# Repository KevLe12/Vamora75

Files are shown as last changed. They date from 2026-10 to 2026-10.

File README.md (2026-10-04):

# Vamora75

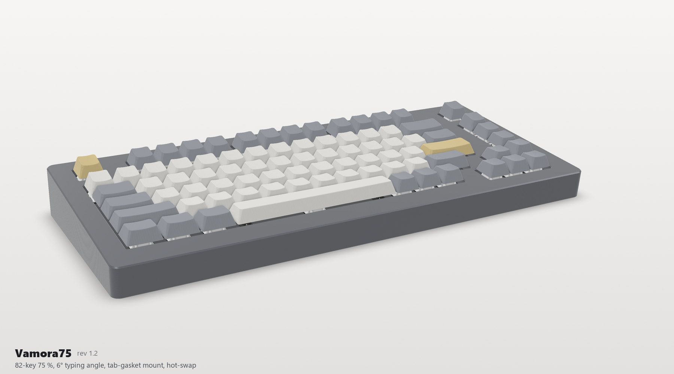
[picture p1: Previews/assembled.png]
Vamora75


**An 82-key 75 % mechanical keyboard with a 6° typing angle, a tab-gasket mount, hot-swap sockets
and an on-board RP2040.** Designed by **Kevin Le, Sammy DeGraaff and Mohammed-Mehdi Hamdaoui**.

> **Status: revision 1.2, complete and checked in software, not built yet.** ERC, DRC, schematic
> parity, plate DRC, 14 CAD interference checks and 30 firmware tests all pass
> ([validation/STATUS.md](validation/STATUS.md)). Build one prototype before a group order and work
> through the open items in [DESIGN_REVIEW.md](DESIGN_REVIEW.md).

## Features

- Exploded 75 % Windows ANSI layout, 82 keys, with a separated arrow cluster
- Hot-swap Kailh sockets for any 3- or 5-pin MX-compatible switch
- PCB-mount screw-in stabilisers on plated, copper-reinforced holes; the plate openings let the
  stabiliser housings pass through
- Tab-gasket sandwich mount: 8 plate tabs, 16 gaskets at 20 % compression, optional flex-cut plate
- 6° typing angle; two-piece case whose top follows the key clusters, so no plate shows between
  them; printed in one piece, in 4 pieces for 250 x 210 mm beds, or CNC
- RP2040 on the board (the Raspberry Pi Pico core circuit), USB-C, ESD protection, fuse, BOOT and
  RESET buttons
- QMK + VIA, or CircuitPython with no compiler
- Black PCB with ENIG gold; "Vamora75" across the PCB front, engraved under the case and in gold on
  the plate (under the top case); *Nam Quốc Sơn Hà* and the designers' names on the PCB back
- Generated from source: one command rebuilds the PCB, plate, case, firmware, manufacturing files,
  3D models and renders, then re-runs every check

## Gallery

| Exploded | Top |
|---|---|
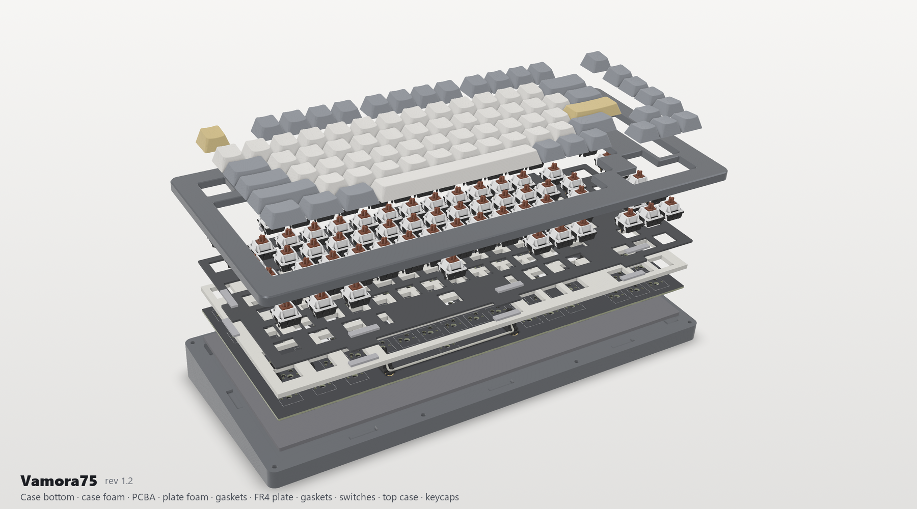
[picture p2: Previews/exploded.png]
Exploded
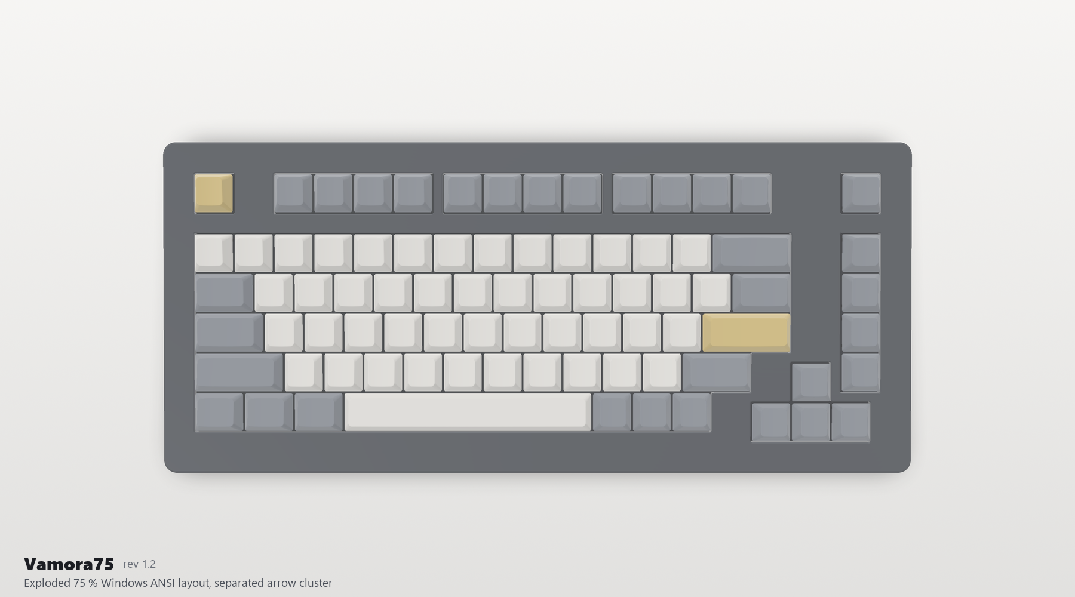
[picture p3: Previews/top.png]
Top
|  |  |
| **Profile** | **Underside** |
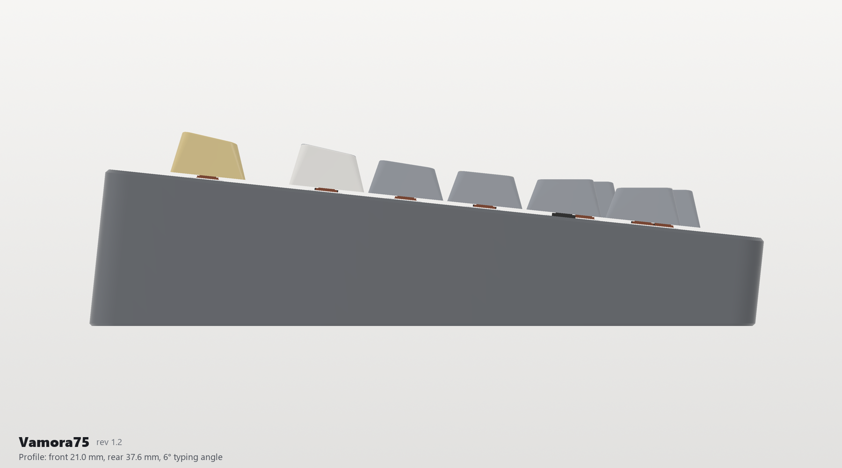
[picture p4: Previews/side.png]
Side
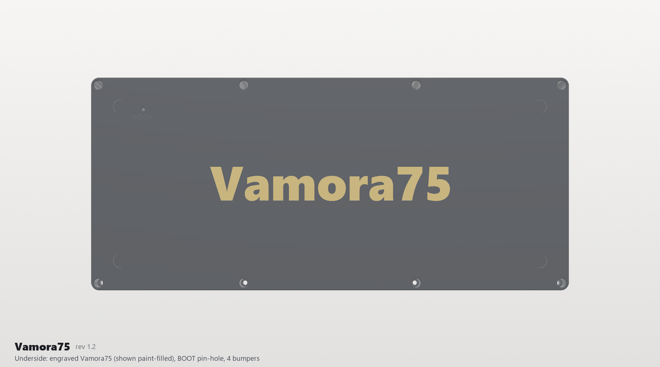
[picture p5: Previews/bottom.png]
Bottom
|  |  |

**PCB + plate + components** (no case): Joe Scotto's MX switches, the PCB-mount stabilisers, Kailh
sockets and every SMD part ([3D file](Mechanical/Vamora75_PCB_plate.step),
[quick-look .glb](Mechanical/Vamora75_PCB_plate.glb)):

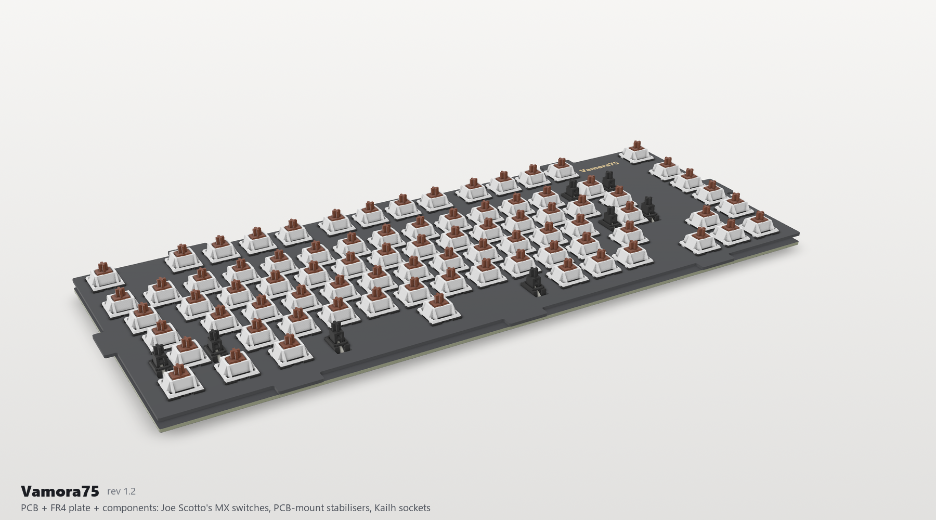
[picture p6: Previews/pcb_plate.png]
PCB and plate


### PCB

| Front ("Vamora75" silkscreen) | Back (*Nam Quốc Sơn Hà*, designers, gold stabiliser rings) |
|---|---|
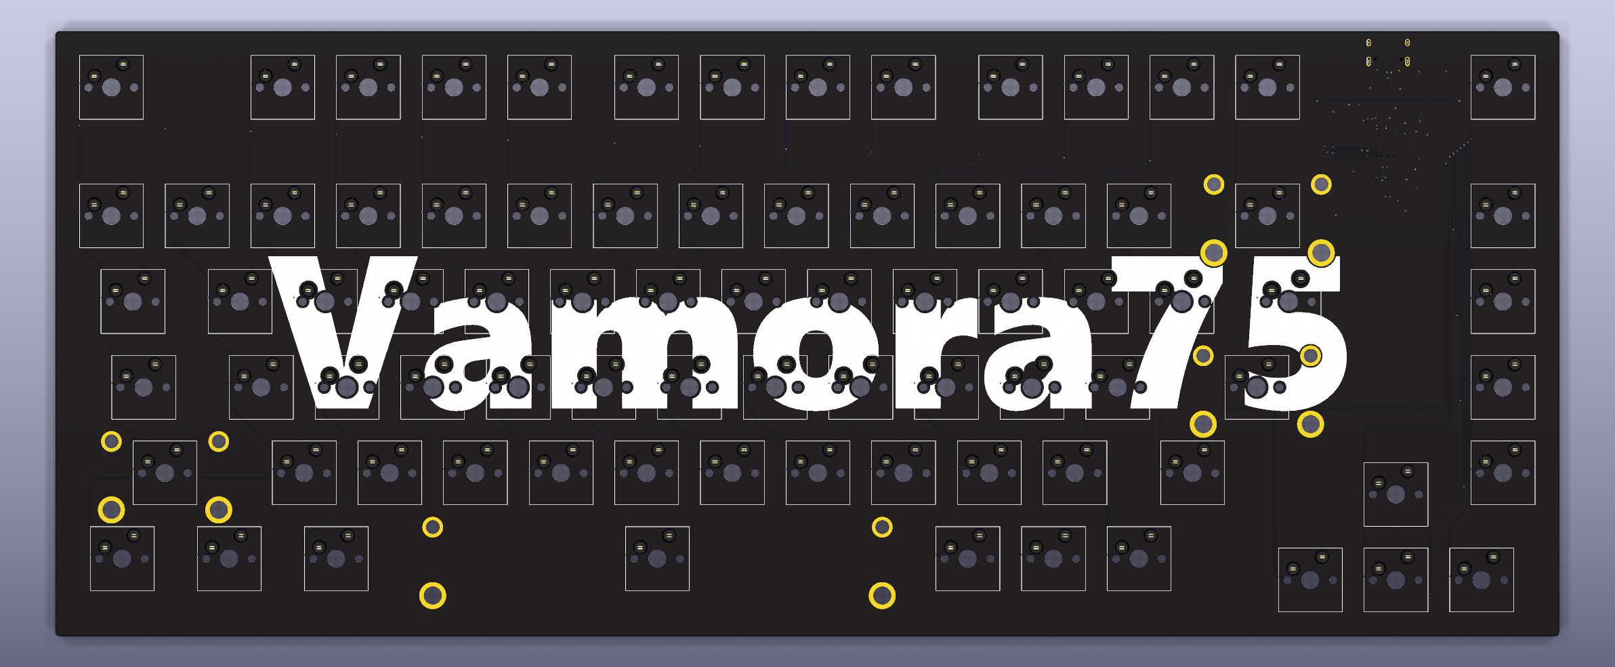
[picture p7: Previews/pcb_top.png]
PCB front
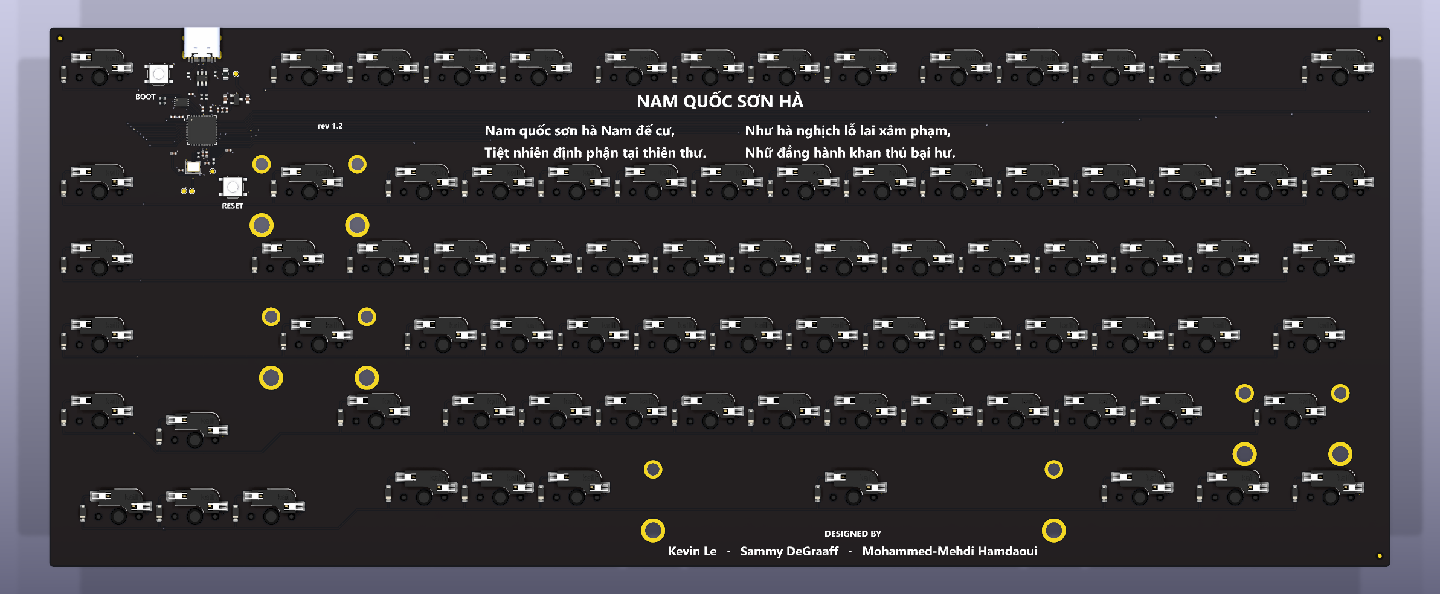
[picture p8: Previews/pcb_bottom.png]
PCB back
|  |  |
| **With Joe Scotto's switch models** | **FR4 plate (name in gold ENIG, under the top case)** |
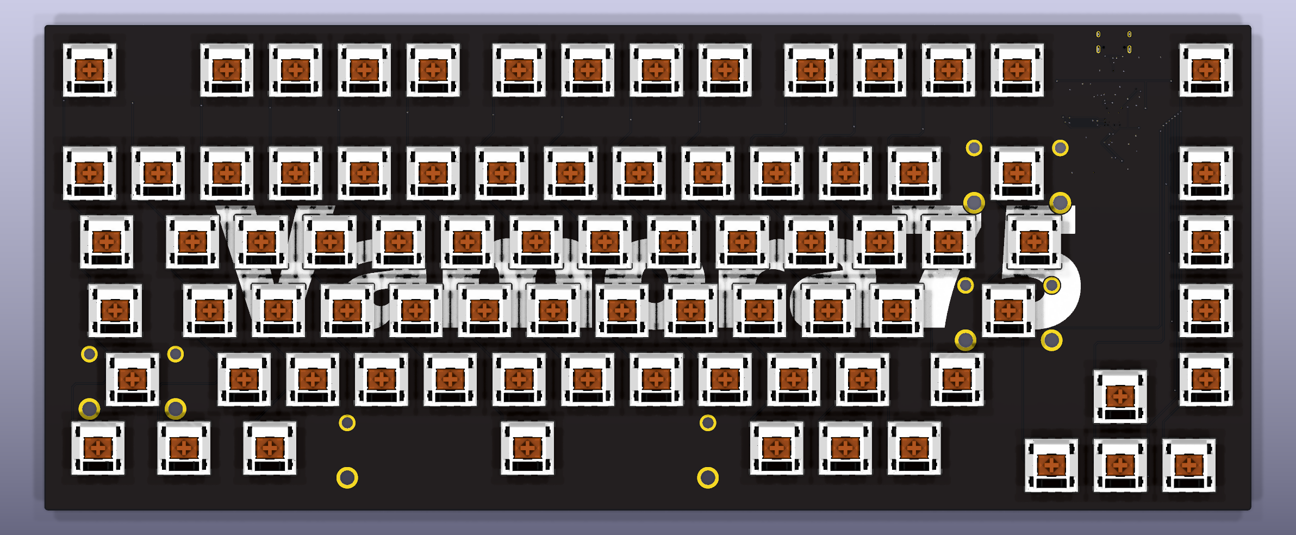
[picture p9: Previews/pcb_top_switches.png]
PCB with switches
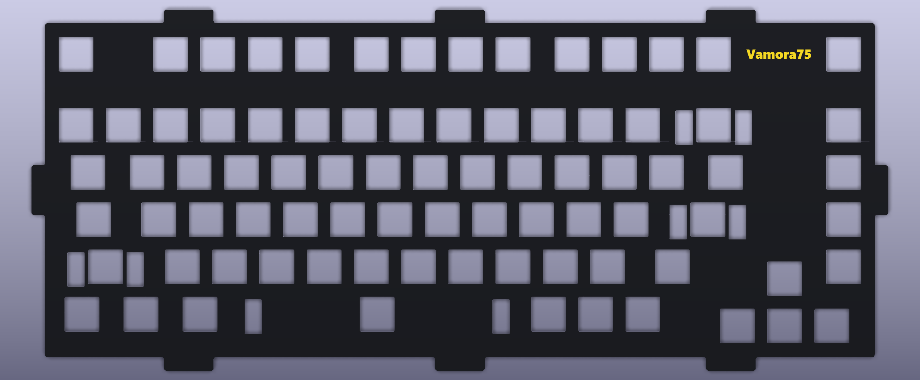
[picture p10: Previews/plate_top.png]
Plate
|  |  |

## 3D files

| File | Shows | Open with |
|---|---|---|
| [Mechanical/Vamora75_assembly.step](Mechanical/Vamora75_assembly.step) | The whole keyboard: case, gaskets, foams, plate, PCBA, switches, stabilisers, keycaps | FreeCAD, Fusion 360, Onshape, SolidWorks |
| [Mechanical/Vamora75_PCB_plate.step](Mechanical/Vamora75_PCB_plate.step) | PCB + plate + every component, without the case | any STEP viewer |
| [Mechanical/Vamora75_PCB_plate.glb](Mechanical/Vamora75_PCB_plate.glb) | The same, as a light coloured model | Windows 3D Viewer, Blender, any web glTF viewer |
| [Mechanical/Vamora75_PCBA.step](Mechanical/Vamora75_PCBA.step) | The PCBA only (KiCad export) | any STEP viewer |
| [PCB/Vamora75.kicad_pro](PCB/Vamora75.kicad_pro) | Schematic and board; press Alt+3 for the 3D view | KiCad 10 |

Case parts, the plate and the soft parts are in [Mechanical/](Mechanical) as STEP/STL/DXF.

## Specifications

| | |
|---|---|
| Layout | 82 keys: exploded 75 % Windows ANSI with an F-row in clusters, a Del/Home/PgUp/PgDn/End column, a separated arrow cluster (0.25u gap), 1.75u RShift and 6.25u space ([layout](Previews/layout.png)) |
| Switches | Any MX-compatible switch, 3- or 5-pin, in Kailh CPG151101S11 hot-swap sockets (ScottoKicad `Hotswap_MX` footprints) |
| Stabilisers | PCB-mount screw-in: Backspace (2u), Enter and LShift (2.25u), Space (6.25u), standard orientation. Plated holes with 4.6 / 6.0 mm copper reinforcement rings; plate openings 7.0 x 14 mm |
| Controller | RP2040, W25Q16JV 2 MB flash, 12 MHz crystal (the Raspberry Pi Pico core circuit), BOOT and RESET buttons |
| USB | USB-C (HRO TYPE-C-31-M-12), USB 2.0 full speed, 5.1 kΩ CC resistors (C-C and A-C cables), USBLC6-2SC6 ESD protection, 0.5 A PTC fuse, XC6206 3.3 V LDO |
| Matrix | 6 x 16, COL2ROW, one 1N4148W per key |
| PCB | 334.61 x 134.59 mm, 2 layers, 1.6 mm, black solder mask, white silkscreen, ENIG. All SMT parts on the bottom (one-sided assembly), GND pour on both layers |
| Plate | FR4, 1.5 mm (1.6 mm also fits), black, 8 gasket tabs, optional flex cuts, "Vamora75" in gold ENIG |
| Mount | Tab-gasket sandwich: 16 gaskets of 20 x 4.5 x 2 mm at 20 % compression. PCB and plate float as one unit |
| Case | Two pieces, 6° typing angle, 21.0 mm high at the front and 37.6 mm at the rear, 358.6 x 161.5 mm. The top-case opening follows the key clusters (the case covers every gap between them). 8 M3 screws into heat-set inserts, "Vamora75" engraved underneath |
| Firmware | QMK + VIA, or CircuitPython |

## Bill of materials

<!-- BOM:start (generated by Source/export_manufacturing.py) -->
Full list: [BOM.csv](BOM.csv). The PCBA parts are placed by JLCPCB from
[Vamora75_BOM_JLCPCB.csv](Manufacturing/PCB/Vamora75_BOM_JLCPCB.csv) and
[Vamora75_CPL_JLCPCB.csv](Manufacturing/PCB/Vamora75_CPL_JLCPCB.csv); you only buy the kit items.

**Kit: what to buy or make**

| Item | Qty | Specification | Source / file |
|---|---|---|---|
| PCBA (this design) | 1 | 2-layer FR4 1.6 mm, black mask, ENIG, bottom-side SMT assembled | Manufacturing/PCB - JLCPCB/PCBWay |
| FR4 plate | 1 | 1.5 mm (1.6 mm fits), black mask, ENIG for the gold name | Manufacturing/Plate - any PCB fab |
| Case top | 1 | PETG/ASA print or CNC 6061 | Mechanical/Case |
| Case bottom | 1 | PETG/ASA print or CNC 6061 (solid wedge, 6 deg) | Mechanical/Case |
| MX-compatible switches | 82 | 3-pin or 5-pin | user choice |
| Keycaps | 82 | 1u x 71, 1.25u x 3, 1.5u x 2, 1.75u x 2, 2u x 1, 2.25u x 2, 6.25u x 1 | any MX set with a 75 % kit (1.75u RShift, 6.25u space) |
| PCB-mount screw-in stabilisers | 4 | 3 x 2u (Backspace, Enter, LShift) + 1 x 6.25u (Space) | Durock/Cherry/TX |
| Gaskets | 16 | 20 x 4.5 x 2 mm Poron 4701-50 or 40A silicone | Mechanical/Soft DXF |
| Case foam | 1 | 3 mm PE / Poron | Mechanical/Soft DXF |
| Plate foam (optional) | 1 | 3.5 mm Poron / PE, with stabiliser/wire windows | Mechanical/Soft DXF |
| Screws | 8 | M3 x 8 ISO 4762 socket head |  |
| Heat-set inserts | 8 | M3 x 4 x 4.0 mm heat-set insert (printed top case; tap M3 if CNC) |  |
| Dowel pins (split print only) | 5 | 3 x 12 mm steel dowel (or printed pin) | only for the 4-piece printed case |
| Bumpers | 4 | 10 x 3 mm silicone bumper |  |
| USB-C cable | 1 | overmould <= 12.3 x 6.5 mm |  |

**PCBA: parts on the board** (197 placements, all on the bottom side)

| Part | Qty | Designators | Footprint | LCSC |
|---|---|---|---|---|
| 10uF CL10A106KP8NNNC | 2 | C1-C2 | C_0603_1608Metric | [C19702](https://www.lcsc.com/product-detail/C19702.html) |
| 100nF CL05B104KO5NNNC | 10 | C3-C7, C9-C12, C15 | Capacitor_0402 | [C1525](https://www.lcsc.com/product-detail/C1525.html) |
| 1uF CL05A105KA5NQNC | 2 | C13-C14 | Capacitor_0402 | [C52923](https://www.lcsc.com/product-detail/C52923.html) |
| 15pF 0402CG150J500NT | 2 | C16-C17 | Capacitor_0402 | [C1548](https://www.lcsc.com/product-detail/C1548.html) |
| 1N4148W | 82 | D1-D82 | Diode_SOD-123 | [C81598](https://www.lcsc.com/product-detail/C81598.html) |
| 500mA SMD0805-050 | 1 | F1 | Fuse_0805_2012Metric | [C66452](https://www.lcsc.com/product-detail/C66452.html) |
| HRO TYPE-C-31-M-12 | 1 | J1 | USB_C_HRO_TYPE-C-31-M-12 | [C165948](https://www.lcsc.com/product-detail/C165948.html) |
| 5.1k 0402WGF5101TCE | 2 | R1-R2 | Resistor_0402 | [C25905](https://www.lcsc.com/product-detail/C25905.html) |
| 27R 0402WGF270JTCE | 2 | R3-R4 | Resistor_0402 | [C25100](https://www.lcsc.com/product-detail/C25100.html) |
| 10k 0402WGF1002TCE | 2 | R5, R7 | Resistor_0402 | [C25744](https://www.lcsc.com/product-detail/C25744.html) |
| 1k 0402WGF1001TCE | 2 | R6, R8 | Resistor_0402 | [C11702](https://www.lcsc.com/product-detail/C11702.html) |
| Kailh CPG151101S11 MX hot-swap socket | 82 | SW1-SW82 | Kailh_CPG151101S11 | [C5156480](https://www.lcsc.com/product-detail/C5156480.html) |
| BOOT TS-1187A-B-A-B | 1 | SW90 | SW_Push_1P1T_XKB_TS-1187A | [C318884](https://www.lcsc.com/product-detail/C318884.html) |
| RESET TS-1187A-B-A-B | 1 | SW91 | SW_Push_1P1T_XKB_TS-1187A | [C318884](https://www.lcsc.com/product-detail/C318884.html) |
| RP2040 | 1 | U1 | QFN-56-1EP_7x7mm_P0.4mm_EP3.2x3.2mm_ThermalVias | [C2040](https://www.lcsc.com/product-detail/C2040.html) |
| USBLC6-2SC6 | 1 | U2 | ESD_SOT-23-6 | [C7519](https://www.lcsc.com/product-detail/C7519.html) |
| XC6206P332MR | 1 | U3 | Voltage_SOT-23 | [C5446](https://www.lcsc.com/product-detail/C5446.html) |
| W25Q16JVUXIQ | 1 | U4 | Winbond_USON-8-1EP_3x2mm_P0.5mm_EP0.2x1.6mm | [C2843335](https://www.lcsc.com/product-detail/C2843335.html) |
| 12MHz ABM8-272-T3 | 1 | Y1 | Crystal_SMD_3225-4Pin_3.2x2.5mm | [C20625731](https://www.lcsc.com/product-detail/C20625731.html) |
<!-- BOM:end -->

## Getting started

1. Read [DESIGN_REVIEW.md](DESIGN_REVIEW.md): the mount, the stabilisers, what changed, and what to
   check on the first prototype.
2. Order the PCBA, the plate, the case and the soft parts:
   [Manufacturing/FABRICATION.md](Manufacturing/FABRICATION.md).
3. Assemble it: [BUILD_GUIDE.md](BUILD_GUIDE.md).
4. Flash the firmware: [Firmware/README.md](Firmware/README.md).
5. To change the design, edit the parameter files and rebuild: [Source/README.md](Source/README.md).

## Repository

| Folder | Contents |
|---|---|
| [PCB/](PCB) | KiCad 10 project: schematic, 2-layer board, project footprint library (ScottoKicad + KiCad stock) with 3D models, custom DRC rules |
| [Plate/](Plate) | KiCad boards for ordering the FR4 plate as a PCB (standard and flex-cut) |
| [Mechanical/](Mechanical) | Case (one-piece and 4-piece print split), plate DXF/STEP/STL, gasket and foam DXFs, assembly STEP, PCB + plate STEP/GLB, PCBA STEP, key positions |
| [Manufacturing/](Manufacturing) | JLCPCB-ready Gerbers/drill, BOM + CPL, schematic PDF, assembly drawing, plate Gerbers, kit BOM |
| [Firmware/](Firmware) | QMK + VIA source, VIA definition, CircuitPython, KLE layout |
| [Artwork/](Artwork) | The "Vamora75" name in SVG/PNG/DXF ([NAME.md](Artwork/NAME.md)) |
| [Previews/](Previews) | Renders |
| [Source/](Source) | Python generators for everything (`build_all.py`) |
| [validation/](validation) | ERC/DRC, mechanical, plate and firmware reports |
| [Archive/](Archive) | Earlier revisions: `rev0.1/`, `rev1.0_outputs.zip`, `rev1.1_outputs.zip` |
| [Reference/](Reference) | Input snapshots (Keyboard75, Aster75) |

## Revisions

- **1.2** (2026-10-03): top case covers the gaps between key clusters, plate openings and foam
  windows for PCB-mount stabilisers, plated and reinforced stabiliser holes, black PCB, designers'
  names on the PCB back, sculpted keycaps, new 3D files and renders.
- **1.1**: arrow cluster moved away from the nav column, Joe Scotto's ScottoKicad footprints and
  models, name-only branding.
- **1.0**: on-board RP2040, new matrix and routing, 6° gasket-mount case.

Details: [CHANGELOG.md](CHANGELOG.md).

## Credits

Designed by **Kevin Le, Sammy DeGraaff and Mohammed-Mehdi Hamdaoui** (team Vamora).

Footprints and 3D models for the switches, sockets, stabilisers and several components are from
Joe Scotto's [ScottoKicad](https://github.com/joe-scotto/scottokeebs). Third-party data and licences:
[ATTRIBUTION.md](ATTRIBUTION.md) and [Licenses/](Licenses).

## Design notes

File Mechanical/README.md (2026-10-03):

# Vamora75 mechanical files

All parts share one coordinate system (STEP/STL, mm): X runs left to right along the front edge,
Y runs toward the rear, and Z points up from the desk. The case sits at its 6° typing angle.
The internal design frame (plate-parallel) is described in `Source/vamora_mech.py`.

| File | Contents |
|---|---|
| `Vamora75_assembly.step` | The whole keyboard: case, gaskets, plate (with its gold name), plate foam, case foam, the PCBA in KiCad's colours (black mask, white silkscreen, gold pads, Joe Scotto's switches, stabilisers, sockets and SMD parts) and sculpted keycaps. Coloured and instanced. |
| `Vamora75_PCB_plate.step` | **PCB + plate + every component**, without the case: the PCBA as above with the FR4 plate fitted 3.5 mm above the PCB (where it sits in the keyboard). Same frame as the PCBA STEP. |
| `Vamora75_PCB_plate.glb` | The same as a coloured glTF file: opens in Windows 3D Viewer, Blender or any web glTF viewer (no CAD software needed). |
| `Vamora75_PCBA.step` | The PCB with solder mask, silkscreen, pads and every component, including Joe Scotto's MX switch on every footprint, exported by KiCad. Origin is the PCB's front-left corner, board bottom at z = 0. |
| `Case/Vamora75_case_top.*`, `Case/Vamora75_case_bottom.*` | One-piece case parts. The top-case opening follows the key clusters (0.25 mm beyond each key's 19.05 mm cell, R1 corners, 0.5 mm chamfer); bridges of 4.3 mm and wider cover every gap between clusters, 1 mm above the plate |
| `Case/print_split/*_L/_R.*` | The same parts split for 250 x 210 mm beds (staggered seams, dowel holes) |
| `Plate/Vamora75_plate_FR4[_flexcut].dxf/.step/.stl` | Plate outline and openings (the DXF has OUTLINE, CUTOUTS and FLEX layers). Stabiliser openings 7.0 x 14 mm for PCB-mount stabilisers. |
| `Soft/*.dxf` | Gaskets (16), case foam (3 mm), plate foam (3.5 mm, with stabiliser/wire windows) |
| `key_positions.csv` | Every key: label, size, matrix, switch/diode refs, PCB and CAD coordinates, stabiliser spacing |
| `build/` | Intermediate files. The switch-free PCBA STEP used by `build_case.py` and the coloured render meshes (`*.npz`) are written here and deleted again by `build_all.py` after rendering. |

Key numbers (from `validation/mechanical.json`):

* Footprint 358.6 x 161.5 mm. Height 21.0 mm at the front and 37.6 mm at the rear. Typing angle 6°.
* Mount: 8 plate tabs (20 x 5.5 mm), 16 gaskets (20 x 4.5 x 2.0 mm) set to 1.6 mm (20 %).
  Tab pockets have 0.5 mm clearance. The PCB and plate have 1.0 mm clearance to every wall.
* Fasteners: 8 M3 x 8 ISO 4762 screws from below, into M3 x 4 heat-set inserts (4.0 mm holes) in the top case.
* USB-C tunnel: 14.0 x 8.0 mm, R3.5, centred on J1. It passes a USB-IF maximum overmould (12.35 x 6.5 mm)
  with 0.8 mm to spare.
* BOOT pin-hole: 2.2 mm, through the floor under SW90.
* 14 interference checks run on every rebuild. Every overlap volume is 0 mm³, including the PCB-mount
  stabilisers through the plate and the plate foam, keycaps pressed fully down (4 mm), the switches
  against the top case, and the gaskets against the plate and case.
* Keycaps in the models are generated sculpted (Cherry-like) caps for looks and clearance checks;
  any MX keycap set fits.

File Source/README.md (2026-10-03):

# Vamora75 sources

Every deliverable in this repository is generated by the scripts in this folder from a few
parameter files. Edit the parameters, rerun, and every file (PCB, plate, case, firmware,
artwork, manufacturing outputs, renders, reports) stays consistent.

```
python -m venv .venv && .venv\Scripts\pip install -r Source\requirements.txt
.venv\Scripts\python Source\build_all.py              # everything, ~8 min (PCB routing ~3 min)
.venv\Scripts\python Source\build_all.py --skip-pcb   # keep the routed board, rebuild the rest
.venv\Scripts\python Source\build_all.py --footprints # also regenerate footprints + 3D models
```

KiCad 10.0.6 must be installed at `C:\Program Files\KiCad\10.0` (paths are at the top of
`build_pcb.py`, `build_all.py`, `export_manufacturing.py`). Joe Scotto's **ScottoKicad** library
is read from `A:\ScottoKicad` (set `VAMORA_SCOTTO` to move it). You only need it to regenerate
footprints (`--footprints`); the project already carries copies of everything it uses. The Segoe UI fonts ship with Windows; any TTF works
(constants in `vamora_logo.py`).

## Parameter files (edit these)

| File | Controls |
|---|---|
| `vamora_layout.py` | revision, date and designers; key positions and sizes, keycodes, matrix row/column of every key, RP2040 GPIO map, stabiliser spacing, PCB size |
| `pcb_plan.py` | placement of diodes and of every controller part (board coordinates), fan-out rule areas |
| `vamora_mech.py` | Z stack, plate tabs, gaskets, case margins, screws, USB tunnel, typing angle, plate cut-outs (incl. stabiliser openings), foam windows, print split |
| `vamora_logo.py` | the "Vamora75" name (`name_text`, Segoe UI Black), text shaping, the product colour palette |

## Pipeline

| Step | Script | Output |
|---|---|---|
| Footprints + 3D models | `gen_footprints.py`, `upgrade_footprints.py` (KiCad Python) | `PCB/Vamora75.pretty`, `PCB/3dmodels`: ScottoKicad hot-swap (with his MX switch model), stabiliser, diode, USB-C and passive footprints and models; KiCad stock RP2040, flash and crystal parts; a generated TS-1187A model. Re-saved in KiCad 10 format; stabiliser holes plated with copper reinforcement rings and keep-outs. |
| Schematic | `gen_schematic.py` | `PCB/Vamora75.kicad_sch` + project symbol library |
| Project / rules | `gen_project.py`, `make_board_plan.py` | `.kicad_pro` (net classes, JLCPCB limits), `.kicad_dru` (0.15 mm only inside fan-out areas) |
| Routing | `route_board.py` (+ `router.py`) | `PCB/build/routes.json` - deterministic: rows on B.Cu, columns on F.Cu, controller fan-out by a grid A* router with clearance fields |
| Checks | `check_connectivity.py` | connectivity + clearance before KiCad sees the board |
| Board | `kicad_build.py` (KiCad Python), `kicad_stackup.py` | `PCB/Vamora75.kicad_pcb` - footprints, nets, tracks, vias, GND pours, rule areas, artwork, black-mask ENIG stackup |
| Silkscreen art | `extract_obstacles.py` (KiCad Python), `gen_artwork.py` | front: a very large "Vamora75" across the middle (knocked out around holes and pads); back: *Nam Quốc Sơn Hà* centred under the F-row, the designers' names under the space bar, BOOT/RESET/rev labels, readable from below |
| DRC / ERC | `build_pcb.py` (orchestrates all of the above) | `validation/erc.json`, `validation/drc.json` |
| Plate | `build_plate.py`, `kicad_plate.py` | `Mechanical/Plate/*` DXF/STEP/STL, `Plate/*.kicad_pcb` |
| Case | `build_case.py` (+ `cad_mesh.py`) | `Mechanical/Case/*`, `Mechanical/Soft/*`, `Mechanical/Vamora75_assembly.step`, `Mechanical/Vamora75_PCB_plate.step/.glb`, `validation/mechanical.json`, render meshes. Inputs: a switch-free PCBA STEP for the checks and the full PCBA STEP for the assemblies. Sculpted keycaps are generated here. |
| Renders | `render_previews.py` | `Previews/*.png`: VTK product renders (PBR materials, studio lighting, ambient occlusion, soft shadows) + KiCad renders in the board's stackup colours (`pcb_top` bare, `pcb_top_switches`, `pcb_bottom`, `plate_top`) |
| Manufacturing | `export_manufacturing.py` | Gerbers, drill, JLCPCB BOM/CPL, PDFs, plate Gerbers, kit BOM |
| Firmware | `gen_firmware.py`, `test_firmware.py` | QMK/VIA/CircuitPython/KLE + `validation/firmware.json` |
| Artwork | `export_artwork.py` | `Artwork/*`: "Vamora75" name SVG/PNG/DXF + overview sheet |
| Layout data | `export_layout.py` | `layout.json`, `Mechanical/key_positions.csv`, `Previews/layout.png` |
| Report | `build_all.py` | `validation/STATUS.md` |

Helpers: `sexp.py` (KiCad s-expressions), `kicad_fp.py` (footprint pad geometry in board
coordinates; bottom side = mirror then rotate, verified against pcbnew), `router.py`,
`cad_mesh.py` (coloured STEP reading, meshes, STEP/GLB assembly writer), `kicad_stackup.py`.

## Changing things safely

* **Moving a key or changing the matrix**: edit `vamora_layout.py`, run `build_all.py`. Routing of
  the matrix is regenerated; check `validation/STATUS.md` for zero DRC/unconnected items.
* **Moving controller parts**: `pcb_plan.py`; the hand-guided fan-out in `route_board.py` refers to
  pad positions, so re-check the DRC carefully.
* **Different typing angle / case height**: `vamora_mech.py` (`TYPING_ANGLE`, `CASE_TOP`, `FLOOR_Z`) -
  `build_case.py` re-runs every interference check.
* The KiCad files are normal KiCad 10 files: you can also edit them by hand in KiCad. A later
  `build_pcb.py` run overwrites the schematic and board, so either keep working in KiCad from then
  on or port the change into the generators.

`Archive/rev0.1/Source` holds the rev 0.1 scripts (module-based board, flat case) for reference.

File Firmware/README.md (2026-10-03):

# Vamora75 firmware

The PCB carries a bare **RP2040** with a **W25Q16JV 2 MB flash** and a **12 MHz crystal** - the same
core circuit as a Raspberry Pi Pico - so both options below run on it unchanged.

| | Matrix | Pins |
|---|---|---|
| Rows 0-5 (diode cathodes) | 6 | GP0, GP6, GP5, GP4, GP3, GP2 |
| Columns 0-15 | 16 | GP29, GP28, GP27, GP26, GP24, GP23, GP22, GP21, GP20, GP19, GP18, GP17, GP16, GP8, GP7, GP1 |
| Diodes | COL2ROW | 1N4148W (SOD-123), one per switch |

Free GPIO: GP9-GP15 and GP25 (GP25 is the Pico's status-LED pin, deliberately left unconnected).

## Entering the bootloader (UF2 drive `RPI-RP2`)

* Brand-new board (blank flash): it enumerates as `RPI-RP2` by itself.
* Hold **Esc** while plugging in (QMK bootmagic), or press **Fn+Esc**.
* Double-tap the **RESET** button (QMK build).
* Hold the **BOOT** button - reachable with a paper clip through the pin-hole in the case bottom - while plugging in.

## Option A - QMK + VIA (recommended)

1. Copy `qmk/keyboards/vamora75` into `qmk_firmware/keyboards/`.
2. `qmk compile -kb vamora75 -km via` (or `-km default`).
3. Copy the resulting `vamora75_via.uf2` to the `RPI-RP2` drive.
4. Remap live in https://usevia.app : Settings -> enable *Show Design tab* -> Design -> load
   `via/vamora75.via.json` (needed until the board is merged into the VIA repository).

`keyboard.json` is data-driven (QMK 0.22+). These sources were generated and statically checked
here (layout/matrix consistency, keymap arity) but **not compiled** - no QMK toolchain in this
environment. Do the first compile before ordering boards.

Default layers: 0 = base, 1 = Fn (hold the Fn key):

| Fn + | Action | Fn + | Action |
|---|---|---|---|
| Esc | bootloader (QK_BOOT) | F7 / F8 | brightness - / + |
| F1 | mute | F9 | calculator |
| F2 / F3 | volume - / + | F10 | Pause |
| F4 | play / pause | F11 | Scroll Lock |
| F5 / F6 | previous / next track | F12 | Print Screen |
| Del | Insert | Win | Windows-key lock (gaming) |
| N | NKRO on/off | | |

## Option B - CircuitPython (no compiler needed)

1. Download the **Raspberry Pi Pico** UF2 from https://circuitpython.org/board/raspberry_pi_pico/
   (10.x). Do *not* use the rev 0.1 Waveshare RP2040-Zero UF2: that build drives GP16 (a matrix
   column on this board) as its NeoPixel.
2. Copy it to `RPI-RP2`; the `CIRCUITPY` drive appears.
3. Copy `CircuitPython/boot.py`, `code.py`, `keymap.py`, `report.py` to `CIRCUITPY`, then replug.
4. Normal use hides the drive and serial port and offers a BIOS-compatible boot keyboard.
   Hold **Esc** while plugging in to get `CIRCUITPY` back for edits.

CircuitPython sends 6 keys + modifiers (6KRO), 5 ms debounce, same Fn layer except Win-lock and NKRO.

## Layout files

* `layout/vamora75.kle.json` - paste into http://www.keyboard-layout-editor.com (Raw data).
* `via/vamora75.via.json` - VIA definition (rows,cols labels).

Generated by `Source/gen_firmware.py`; tests: `Source/test_firmware.py`.

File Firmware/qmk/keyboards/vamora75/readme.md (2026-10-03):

# Vamora75

82-key 75 % (exploded Windows ANSI) hot-swap keyboard with an on-board RP2040.
Designed by Kevin Le, Sammy DeGraaff and Mohammed-Mehdi Hamdaoui (team Vamora).

* Keyboard maintainer: vamora
* Hardware supported: Vamora75 PCB (RP2040, W25Q16JV, USB-C, Kailh hot-swap)
* Hardware availability: open-source design files

Make example for this keyboard (after setting up your build environment):

    qmk compile -kb vamora75 -km default
    qmk compile -kb vamora75 -km via

Flashing example: copy the `.uf2` file to the `RPI-RP2` drive.

See the [build environment setup](https://docs.qmk.fm/#/getting_started_build_tools) and the
[make instructions](https://docs.qmk.fm/#/getting_started_make_guide) for more information.

## Bootloader

Enter the bootloader in 4 ways:

* **Bootmagic reset**: hold Esc (top-left key) and plug in the keyboard
* **Keycode in layout**: Fn+Esc (`QK_BOOT`)
* **Double-tap reset**: double-tap the RESET button on the PCB
* **Physical**: hold BOOT (pin-hole in the case bottom) while plugging in

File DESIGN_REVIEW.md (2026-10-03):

# Vamora75 - design review of rev 0.1 and what changed in rev 1.0 / 1.1 / 1.2

> **rev 1.2 update:** the top-case opening follows the key clusters, so the case covers every gap
> between them and no plate shows inside the keyboard. PCB-mount stabilisers checked in 3D against the plate and plate foam; plate
> stabiliser openings widened to 7.0 mm, foam windows added, and the PCB stabiliser holes are now
> plated with copper reinforcement rings. Black solder mask, the designers' names on the PCB back,
> sculpted keycaps and new renders. See below and `CHANGELOG.md`.
>
> **rev 1.1 update:** the arrow cluster sits 0.25u left and 0.25u down so it no longer crowds the
> Del/Home/PgUp/PgDn/End column. Switch, stabiliser, diode, USB-C and passive footprints and their 3D
> models now come from Joe Scotto's ScottoKicad library, and his MX switch model is shown on the board.
> The PCB front carries a very large "Vamora75" (no logo), the back keeps *Nam Quốc Sơn Hà*, and the
> case and plate show only the name. See `CHANGELOG.md`.

## Is it gasket mount?

**Yes. Rev 0.1 was already a tab-gasket ("sandwich") mount, and rev 1.0 keeps that mount style
and refines it.**

The evidence in the rev 0.1 sources (`Archive/rev0.1/Source/build_mechanical.py`):

* The FR4 plate had six tabs (24 x 6 mm), three on the front edge and three on the rear edge.
* Twelve foam strips (24 x 5.5 x 2 mm) sat in pockets: one under and one over each tab. The
  pockets were cut into the bottom case (Z 18.5-21) and the top case (Z 19.9-23.2).
* The case split at Z 20.0, inside the plate's thickness (plate Z 20.1-21.6). So the only path
  from the plate to the case went through the gaskets.
* The PCB hung from the switches. Nothing screwed the PCB or the plate to the case, and the
  build guide said not to add standoffs.

In rev 1.0 the plate has **8 tabs** (3 front, 3 rear, 1 left, 1 right) and **16 gaskets**
(20 x 4.5 x 2.0 mm). The pockets set each gasket to exactly 1.6 mm, which is 20 % compression.
An optional flex-cut plate adds relief slots behind every tab. The PCB and plate still float as
one unit: the 8 case screws only join the two case halves.

## Do PCB-mount stabilisers fit through the plate?

**Yes.** Every stabilised key (Backspace, Enter, LShift, Space) has a stabiliser opening on each
side of the switch opening, so a PCB-mount (screw-in) stabiliser is screwed to the PCB first and
its housing then passes up through the plate. Rev 1.2 checks this in 3D with Joe Scotto's
stabiliser model on the real PCB, plate and foam:

* **Plate:** the openings are 7.0 x 14 mm (6 mm to the rear, 8 mm to the front for the wire). The
  model's housing is 6.8 mm wide where it passes the plate, so the 6.75 mm Cherry/ai03 opening used
  up to rev 1.1 was 0.025 mm too narrow for it. The 7.0 mm opening leaves 0.1 mm a side even for
  that housing, and more for narrower ones, which also absorbs PCB-to-plate misalignment. The narrowest FR4 web is now between switch
  and stabiliser openings (see `validation/STATUS.md`).
* **Plate foam:** near the PCB the housing base is longer than the plate opening (about
  6.8 x 19.2 mm) and the wire runs in front of it, so the foam now has one window per stabilised
  key that clears both housings and the wire by 0.6 mm.
* **PCB:** the four holes per stabiliser are plated and carry copper rings on both sides (4.6 mm on
  the 3.05 mm holes, 6.0 mm on the 3.99 mm screw holes). The screw head and washer clamp onto a
  flat metal ring instead of solder mask, and the plated barrels stiffen the hole walls. No trace
  runs within 0.5 mm of a ring on the bottom side.
* Both new checks (plate x stabilisers, plate foam x stabilisers) report 0 mm³ of overlap.

Plate-mount (clip-in) stabilisers are not supported: the openings are deliberately loose.

## Review findings and fixes

| Area | Rev 0.1 finding | Consequence | Rev 1.0 |
|---|---|---|---|
| Controller | Waveshare RP2040-Zero module soldered upside-down under the PCB on headers, 3.5 mm gap set with a home-made spacer jig | Tall stack (module board plus its parts under the main PCB), so the case was 28 mm with no typing angle. The module had to be hand-soldered at an exact height. BOOT/RESET could only be reached through an open hole in the case floor. The tunnel had to be 20 x 8.5 mm. | RP2040 on the PCB, using the Raspberry Pi Pico core circuit (W25Q16JV, 12 MHz ABM8 crystal, 1 kΩ XOUT resistor, 15 pF). Added USBLC6-2SC6 ESD protection, a 0.5 A PTC fuse, 5.1 kΩ CC resistors, an XC6206 LDO, BOOT/RESET buttons and test pads, all machine-placed. USB-C sits at the PCB rear edge behind a 14 x 8 mm tunnel; BOOT is reachable through a 2.2 mm pin-hole. |
| Matrix | 7 x 12 (84 slots) for 6 physical rows; GP7-15 + GP26-28 columns | Rows did not match the physical rows, and the matrix could not be fanned out cleanly from a bare MCU | 6 x 16 COL2ROW. Each row is one physical row. GPIOs were chosen so the QFN fans out with no crossings. GP9-15 and GP25 are left free. |
| PCB | Inherited routing, cleaned from 5,820 to 1,686 segments; COL9 kept its original routing after a failed shortcut | Hard to maintain or modify | Re-routed from scratch by a deterministic generator: rows on B.Cu at y+3 mm, columns on F.Cu, a column bus in the 0.5u gap, and the controller fan-out by a grid A* router. GND pour on both layers. Zero DRC violations under JLCPCB-legal rules (0.15 mm only inside three named fan-out areas). |
| Hot-swap footprint | Keyboard75 MX hot-swap footprints | No accurate 3D model or bottom-side courtyard data for assembly | ScottoKicad `Hotswap_MX_*` footprints (Kailh CPG151101S11 on B.Cu) and `Stabilizer_MX_*` footprints with keep-outs, with Scotto's socket, switch and stabiliser models (rev 1.1; rev 1.0 used generated equivalents). LCSC part C5156480. All SMT parts are on the bottom side, so JLCPCB can assemble the board in one pass. Rev 1.2: plated stabiliser holes with copper reinforcement rings. |
| Plate openings | Sharp 14 mm squares; stabiliser openings were plain 8 x 18.4 mm boxes | FR4 is routed with cutters of 1 mm or more, so true sharp corners are impossible. The stabiliser openings did not follow any stabiliser specification. | 14.0 mm openings with 0.5 mm corners (router-native; MX housings have chamfered corners). Stabiliser openings: ai03's "MX simple" profile (6.75 x 14 mm, +6/-8 mm) up to rev 1.1, 7.0 x 14 mm from rev 1.2 so PCB-mount housings pass with clearance. |
| Stabilisers | Spacebar stabiliser drilled reversed relative to the 2u keys | Needs reversed wires or a different stabiliser part | All four stabilisers (Backspace, Enter, LShift, Space) use the standard Cherry orientation. |
| Mount | 6 tabs, long edges only | Plate support was uneven along the short edges | 8 tabs, pockets sized for 20 % gasket compression, optional flex cuts |
| Case | Flat (0 deg), 28 mm tall, needed a 359 mm print bed; M3 screws tapped into 2.5 mm printed pilots and cut to 24 mm | Uncomfortable typing angle, threads that wear out, and few printers could print it | 6 deg wedge (21.0 mm at the front, 37.1 mm at the rear). M3x8 screws into heat-set inserts. A 4-piece split with staggered seams and dowels fits 250 x 210 mm beds. Added bumper recesses, a BOOT pin-hole and a USB tunnel sized for the largest overmould the USB spec allows. |
| Manufacturing | BOM without assembly data | Needed manual sourcing and hand assembly | JLCPCB BOM with LCSC numbers, a CPL with socket centroid correction, Gerbers/drill, schematic PDF and bottom assembly drawing. The plate is ordered as a PCB with the name in gold ENIG. |
| Branding | Generic "V / mountain / river" mark | Did not fit the product | Rev 1.0 had a badge (archived). Rev 1.1 uses the name only: a very large "Vamora75" across the PCB front, engraved on the case and in gold on the plate (see `Artwork/NAME.md`). The PCB back keeps *Nam Quốc Sơn Hà* and, from rev 1.2, the designers' names. |
| Firmware | QMK for the module pin-out; CircuitPython UF2 for the RP2040-Zero | That UF2 drives GP16 as a NeoPixel, which is now a matrix column | QMK (data-driven) + VIA keymap and definition; CircuitPython for the Raspberry Pi Pico build. 30 automated checks, including netlist vs. firmware pins. |

## Kept from rev 0.1

* Layout: 82-key exploded 75 % Windows ANSI with the same key positions, except the arrow
  cluster, which rev 1.1 moved 0.25u left and down (the PCB grew to 334.6125 x 134.5875 mm).
* Kailh CPG151101S11 sockets, 1N4148W SOD-123 diodes, COL2ROW.
* FR4 plate, tab-gasket mount, two-piece case.
* *Nam Quốc Sơn Hà* on the PCB bottom silkscreen, centred under the F-row in rev 1.1.

## Open items - verify on the first prototype

1. **QMK compile** (`qmk compile -kb vamora75 -km via`). The sources are statically checked but have
   not been compiled here.
2. **JLCPCB stock and rotations**: check the stock of C5156480 (Kailh socket), C2040 (RP2040),
   C2843335 (flash), C20625731 (crystal) and C165948 (USB-C). In the placement preview, check every
   bottom-side part, in particular the socket orientation, U1 pin 1 and the diode cathode (pad 1 = ROW).
3. **USB-C on the bottom side**: the plug enters below the PCB through the rear tunnel. Use a cable
   whose overmould is 12.35 x 6.5 mm or smaller (most are).
4. **Printed tolerances**: tab pockets have 0.5 mm clearance and insert holes are 4.0 mm. Print one
   corner first.
5. **Plate thickness**: designed for 1.5 mm. 1.6 mm also fits, with about 0.05 mm more compression per gasket.
6. **Electrical bring-up**: before plugging in, check the test pads TP1-TP4 for shorts. The board must
   show up as `RPI-RP2` with blank flash (see `BUILD_GUIDE.md`).
7. **Stabilisers**: screw one stabiliser in, fit the plate over it and press the stabilised key a few
   times before fitting the rest. The plated holes are finished to the Cherry sizes (3.05 / 3.99 mm,
   PTH tolerance ±0.08 mm); check that the first housing seats flat on the PCB.

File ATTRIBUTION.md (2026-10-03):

# Attribution

Vamora75 is designed by **Kevin Le, Sammy DeGraaff and Mohammed-Mehdi Hamdaoui** (team Vamora).
Every deliverable is generated by the scripts in `Source/`. The inputs and third-party material are
listed below. Keep this file and `Licenses/` when you share the project.

## Project inputs (supplied by the team)

- **Keyboard75 / Keyboard75_Exploded_ANSI** (local project): the 82-key exploded 75 % layout, key
  positions and PCB outline. Rev 1.0 keeps the layout. Its schematic, matrix, controller and
  routing were all replaced. Original notes: `Reference/Keyboard75_README.md`.
- **Aster75** (local project): the two-piece tab-gasket case approach used in rev 0.1. Rev 1.0
  rebuilt the case with new code and dimensions. Its attribution is in `Reference/Aster75_ATTRIBUTION.md`.
  Aster75 credits **The Manta75** by Eric Becourt (mymakercorner), hardware licensed CC BY 4.0
  (https://github.com/mymakercorner/the_manta75). The licence is in `Licenses/`.
- **Rev 0.1** (`Archive/rev0.1/`) also used ai03's MX_V2 library (MIT, `Licenses/MX_V2_LICENSE.txt`)
  and the Waveshare RP2040-Zero.

## ScottoKicad (Joe Scotto) - used from rev 1.1

Rev 1.1 uses footprints and 3D models from Joe Scotto's **ScottoKicad** library
(https://github.com/joe-scotto/scottokeebs, local copy `A:\ScottoKicad`), copied into
`PCB/Vamora75.pretty` and `PCB/3dmodels` so the project opens without the library installed:

- `Hotswap_MX_1.00u` ... `Hotswap_MX_6.25u`: MX switch + Kailh CPG151101S11 hot-swap socket
  footprints, with the `Hotswap_MX.step` socket model and `MX_PCB.step` switch model.
- `Stabilizer_MX_2.00u`, `Stabilizer_MX_6.25u`: PCB-mount stabiliser footprints and models.
- `Diode_SOD-123`, `USB_C_HRO_TYPE-C-31-M-12`, `Resistor_0402`, `Capacitor_0402`,
  `ESD_SOT-23-6`, `Voltage_SOT-23`, and the diode and USB-C models.
- `MX_*_CAD.step` keycap models (rev 1.1 renders and assembly only; rev 1.2 uses generated
  sculpted keycaps instead).

Changes made in the copies: re-saved in KiCad 10 format; USB-C shield pads renamed `S1` to
`SH` to match KiCad's USB-C symbol; stabiliser holes turned into plated holes with copper
reinforcement rings (4.6 / 6.0 mm, rev 1.2) and B.Cu keep-outs 0.5 mm beyond the rings; the MX
switch model added to the hot-swap footprints; 3D-model paths pointed at `${KIPRJMOD}/3dmodels`. Per ScottoKicad's README, its parts come from several libraries, mostly
licensed CC-BY-SA 4.0: KiSwitch (switches, stabilisers, sockets), Keebio, Kleeb, Marbastlib,
Adafruit and others. See `Licenses/ScottoKicad-NOTICE.md`. Check the individual upstream
libraries before redistributing the library files themselves.

## Third-party data (rev 1.0, still used)

- **KiCad 10 libraries**: the stock footprints and 3D models for QFN-56 (RP2040), USON-8, crystal,
  0603 capacitors, fuse, test pad, fiducial and TS-1187A, plus the 0402/SOT-23 models.
  They are licensed CC-BY-SA 4.0 with the KiCad design exception (`Licenses/KiCad-library-license.md`).
  The files are copied into `PCB/Vamora75.pretty` and `PCB/3dmodels` so the project is
  self-contained.
- **Plate stabiliser openings**: based on the "MX simple" profile from ai03's plate generator
  (https://github.com/ai03-2725/another-keyboard-builder), widened to 7.0 mm in rev 1.2. Only the
  published dimensions are used; they are reimplemented in `Source/vamora_mech.py`.
- **Reference circuit**: the RP2040 core circuit (crystal, flash, decoupling, USB) follows Raspberry
  Pi's "Hardware design with RP2040" guide and the Pico design. The part numbers are the same ones
  Raspberry Pi uses.
- **Fonts**: the "Vamora75" name and the small labels are glyph outlines from **Segoe UI Black /
  Segoe UI Bold** (Microsoft, shipped with Windows), shaped with HarfBuzz and converted with
  fontTools. Only vector outlines appear in the outputs; no font file is redistributed. To use an
  open font, point `SEGOE_BLACK`/`SEGOE_BOLD` in `Source/vamora_logo.py` at, for example, Noto Sans
  (SIL OFL) and rebuild.
- **Nam Quốc Sơn Hà** (PCB bottom silkscreen): a medieval poem in the public domain, in the common
  Hán-Việt transcription, set in Segoe UI Bold.
- **QMK Firmware** is GPL-2.0-or-later (https://github.com/qmk/qmk_firmware, `Licenses/QMK-LICENSE.txt`).
  The keyboard definition in `Firmware/qmk` is provided under the same licence. The QMK core is not included.
- **CircuitPython** (MIT, `Licenses/CircuitPython-LICENSE.txt`): the user downloads the official
  Raspberry Pi Pico UF2 from circuitpython.org. The four `.py` files in `Firmware/CircuitPython` are
  original.
- **Manufacturer and part names** (Raspberry Pi, Winbond, Kailh, HRO, Abracon, STMicroelectronics,
  Torex, XKB, JLCPCB/LCSC, Poron) identify compatible parts only. No endorsement is implied.

## Original work in this project

The case and plate design, the PCB design, the sculpted keycap models, the renders and all
`Source/` scripts were created for Vamora75 (the rev 1.0 badge artwork is kept in
`Archive/rev1.0_outputs.zip`). The AnnovaX75 project by Arnav Kumar (AGPL-3.0) was looked at as a
reference for presentation only; none of its files are used. No new licence is claimed
over third-party inputs beyond their own notices.

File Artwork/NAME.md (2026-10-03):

# Vamora75 name artwork

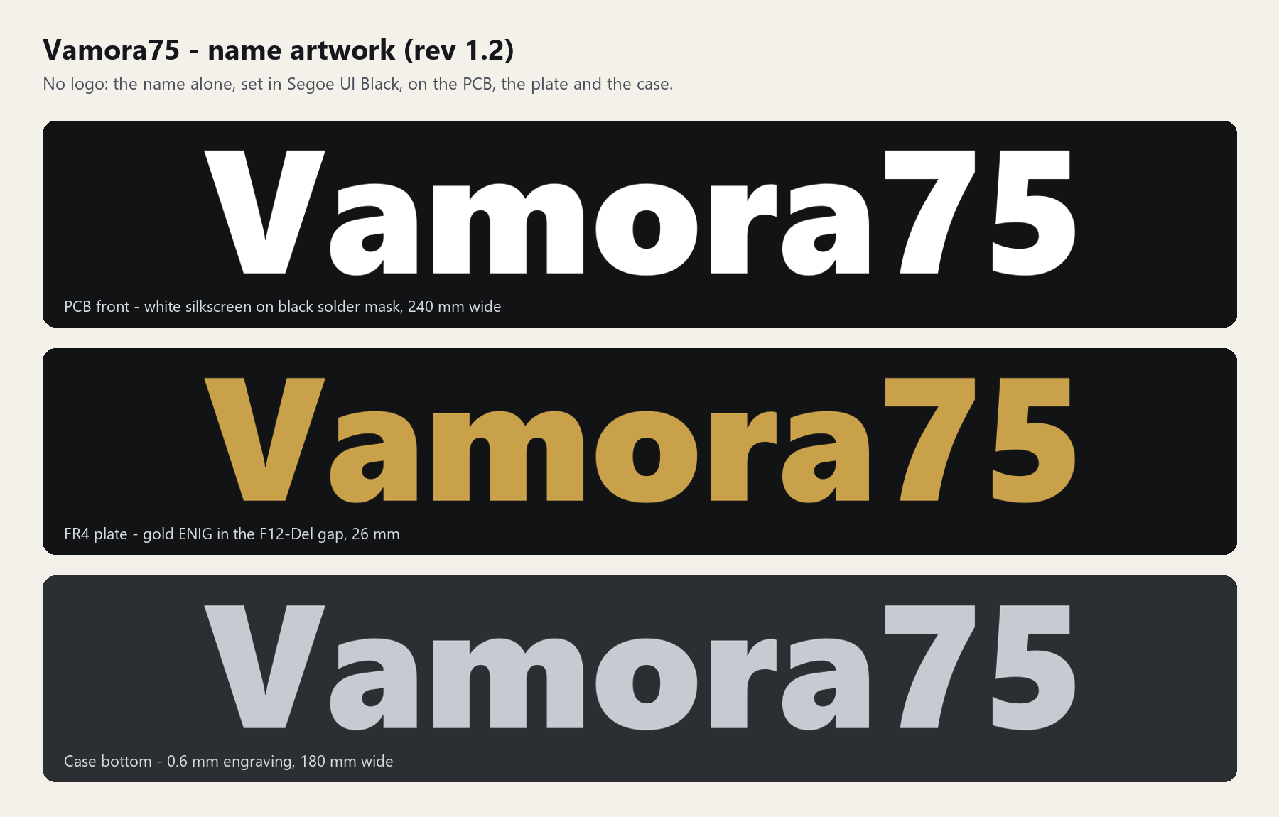
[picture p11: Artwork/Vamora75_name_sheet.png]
Vamora75


From rev 1.1 the board carries **no logo, only the name "Vamora75"**. It is set in Segoe UI
Black and is the same outline everywhere:

| Place | Size | Process |
|---|---|---|
| PCB front, across the middle of the board | 240 mm wide (about 72 % of the board) | White silkscreen on black solder mask, knocked out around every hole and exposed pad. Joe Scotto's switch outlines run through the letters; the tented vias are printed over. |
| FR4 plate, in the key-free F12-Del gap | 26 mm wide | Bare copper under a mask opening (gold with ENIG). From rev 1.2 the top case covers this gap, so the name shows only with the case open |
| Case bottom, centred | 180 mm wide | 0.6 mm engraving, can be paint-filled. The print-split seam is placed so it falls between two letters. |

Files:

| File | Use |
|---|---|
| `Vamora75_name_black.svg/.png` | Dark name, transparent background |
| `Vamora75_name_white.svg/.png` | White name, transparent background |
| `Vamora75_name_on_graphite.svg/.png` | White on the case colour (graphite) |
| `Vamora75_name_engrave.dxf` | Closed outlines in mm (CNC, laser, engraving) |
| `Vamora75_name_sheet.png` | Overview |

The geometry comes from `Source/vamora_logo.py` (`name_text`); regenerate with
`Source/export_artwork.py`. To use a different font, change `SEGOE_BLACK` there and rebuild
(`Source/build_all.py`) so the PCB, plate and case stay identical. The PCB back carries the
*Nam Quốc Sơn Hà* poem and the designers' names (Segoe UI Bold, generated by `Source/gen_artwork.py`). The rev 1.0 badge
(keycap with interlaced star and trilingual tagline) is kept in `Archive/rev1.0_outputs.zip`.

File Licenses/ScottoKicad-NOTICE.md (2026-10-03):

# ScottoKicad - notice

Footprints and 3D models in `PCB/Vamora75.pretty` and `PCB/3dmodels` whose names start with
`Hotswap_MX_`, `Stabilizer_MX_`, `Diode_SOD-123`, `USB_C_HRO_TYPE-C-31-M-12`, `Resistor_0402`,
`Capacitor_0402`, `ESD_SOT-23-6` and `Voltage_SOT-23` (plus `Hotswap_MX.step`, `MX_PCB.step`,
`Stabilizer_MX_*.step`, `Diode_SOD-123.step`, `USB_C_HRO_TYPE-C-31-M-12.step`) come from
**ScottoKicad** by Joe Scotto (rev 1.1 also used his keycap models; rev 1.2 does not):
https://github.com/joe-scotto/scottokeebs

ScottoKicad's README says it collects parts from these libraries and asks users to check each one's
licence ("most are Creative Commons CC-BY-SA 4.0"):

- KiSwitch - https://github.com/kiswitch/kiswitch (switches, stabilisers, sockets)
- KiCad-RP-Pico - https://github.com/ncarandini/KiCad-RP-Pico
- kicad-lib-arduino - https://github.com/g200kg/kicad-lib-arduino
- Marbastlib - https://github.com/ebastler/marbastlib
- Kleeb - https://github.com/crides/kleeb
- Keebio-Parts.pretty - https://github.com/keebio/Keebio-Parts.pretty
- Adafruit_CAD_Parts - https://github.com/adafruit/Adafruit_CAD_Parts

The modifications made for Vamora75 are listed in `ATTRIBUTION.md`. Where CC-BY-SA 4.0 applies,
redistributed copies of these library files keep that licence.

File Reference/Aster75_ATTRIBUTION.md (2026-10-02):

# Attribution and sources

## Manta75 hardware and firmware

Controller circuitry and the key arrangement are derived from **The Manta75**, by **Eric Becourt (Rico / mymakercorner)**.

- Hardware source: https://github.com/mymakercorner/the_manta75
- Supplied local reference: the_manta75 directory provided by the user.
- Hardware license: Creative Commons Attribution 4.0 International, copied in Licenses/Manta75-CC-BY-4.0.md.
- Firmware source: https://github.com/mymakercorner/qmk_firmware/tree/the_manta75
- QMK source and binary retain their original GPL licensing and notices; see Firmware/QMK-LICENSE.txt.

Changes made for this package: fixed 83-key ANSI layout; Kailh MX socket footprints; fresh matrix routing; removal of personal copper/mask artwork; new ISP access pads and service markings; local libraries; a rebuilt modern schematic; a new two-piece gasket-mounted case, plate, gasket pattern, and optional risers. Original source-author credit is retained here instead of decorative PCB artwork. The supplied VIA firmware binary is unmodified.

## USB daughterboard

**Unified Daughterboard Project — UDB-C-JSH**, revision C5, downloaded source commit prefix **2b6c52a**.

- Source: https://github.com/Unified-Daughterboard/UDB-C-JSH
- Documentation: https://unified-daughterboard.github.io/
- License: MIT; complete notice in USB_daughterboard/LICENSE.
- Original contributors are credited in USB_daughterboard/README.md.
- Changes and remaining assembly review item are recorded in USB_daughterboard/MODIFICATIONS.md.

## Library symbols and manufacturer drawing

- Local schematic symbol subset: KiCad community libraries from the installed KiCad 10 distribution. They retain the KiCad library CC-BY-SA 4.0 license with design-use exception; see Licenses/KiCad-library-license.md and https://www.kicad.org/libraries/license/ . The symbol subsets were expanded from inherited symbols and packaged locally for portability.
- Kailh socket geometry reference: manufacturer drawing **CPG151101S11-16 / KHA-PG1511-388EN**, 2022-06-01, in the manufacturer's product specification: https://www.kailhswitch.com/Content/upload/pdf/202215927/CPG151101S11-16.pdf . Manufacturer documents and marks remain the property of their owners; the original PDF is not redistributed in this package.

The new files are provided as a prototype derivative with these provenance notices. No endorsement by the original designers, KiCad, or component manufacturers is claimed.

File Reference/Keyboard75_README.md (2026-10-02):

# Keyboard75 — exploded ANSI, Rev A

82-key, two-layer, full-height MX hot-swap keyboard with a Windows key, standard US ANSI legends, and a USB-C Waveshare RP2040-Zero module. This is a custom PCB, not a drop-in replacement for a commercial 75% case.

## Open the project

Open `Keyboard75_Exploded_ANSI.kicad_pro` in KiCad 7 or newer. The schematic, routed PCB, symbols and footprints are included; no third-party library installation is needed. The controller is an off-the-shelf **original Waveshare RP2040-Zero module**, not a bare RP2040 chip. USB-C, power regulation, flash and decoupling are already on that module.

## Mechanical specification

- PCB: 334.6125 × 129.825 × 1.6 mm FR4, 2 copper layers.
- Switch pitch: 19.05 mm. 82 Kailh CPG151101S11 sockets on the **bottom**. Supports full-height 3-pin and 5-pin MX compatible switches.
- Keycaps: 6.25u spacebar, 1.75u right Shift, 1.25u left modifiers, 1u right Alt/Fn/Ctrl.
- Four stabilized keys: Backspace, Enter, left Shift and Space. Use three 2u Cherry compatible PCB stabilizers and one 6.25u / 100 mm stabilizer pair. Spacebar stabilizers are reversed relative to the other stabilized keys.
- Six 2.2 mm M2 mounting holes. Keep screw head diameter at or below 4.4 mm. Coordinates are in `docs/mounting_holes.csv`.
- Module: 18 × 23.5 mm body mounted underneath, components toward the case bottom. USB-C faces the rear in the Esc/F1 gap, 31.575 mm from the PCB left edge. Module bottom header row is 0.21 mm below the bottom side-row pins; the footprint reflects this.
- The module, pins and sockets require bottom clearance. Design the case using their actual assembled heights. Leave access to module BOOT and RESET buttons.
- Plate DXF uses millimetres: 14 mm switch openings, 8 × 18.4 mm stabilizer clearance openings, M2 holes and PCB outline. Use a nominal 1.5 mm plate and check clip/kerf tolerances against the chosen switches and stabilizers. The plate is a starting mechanical drawing, not a certified fit.

## Circuit and firmware

7 × 12 matrix, one 1N4148W SOD-123 diode per key. Switch pad 1 goes to COL; switch pad 2 goes to diode anode; diode cathode **pad 1** goes to ROW. Use QMK `COL2ROW`. Diode cathode stripe must face the cathode pad marked by the diode footprint.

ROW0–ROW6: GP0–GP6. COL0–COL8: GP7–GP15. COL9–COL11: GP26, GP27, GP28. Module pin 20 / GP29 is unused. There are two spare matrix positions. Module 5V, 3V3 and GND are exposed at three measurement pads; do not connect external power while using USB.

Copy `firmware/qmk/keyboards/custom/kb75_ansi` into a current QMK checkout and run `qmk compile -kb custom/kb75_ansi -km default`. The base layer includes left Windows (GUI) and an Fn key. Fn+Esc enters the bootloader; Fn+F1–F6 controls media, Fn+F12 is Print Screen and Fn+Home is Insert. For initial flashing hold the module BOOT button while connecting USB, then copy the built UF2 to the bootloader drive. Firmware is provided as source and **has not been compiled or tested on hardware**.

## Fabrication and assembly

Use `fabrication/` Gerbers and both PTH and NPTH Excellon drill files. Board defaults: 2 layers, FR4 1.6 mm, 1 oz copper, no impedance control, 0.25 mm traces, 0.20 mm clearance, 0.60/0.30 mm vias. Inspect the boardhouse preview before ordering. Front paste may be empty because sockets and diodes are on the bottom and the measurement pads require no paste.

1. Confirm keycap, plate, stabilizer and case fit using the provided position drawings.
2. Solder the 82 bottom diodes, aligning cathode stripes to pad 1.
3. Solder the 82 bottom hot-swap sockets. Support each socket when inserting a switch.
4. Attach the RP2040-Zero underneath through its 23 header connections. Pin 1 is GP0; pin 23 is 5V. Verify orientation against the schematic and footprint before soldering.
5. Inspect for solder bridges, check resistance between 5V and GND, flash firmware and test every key before completing the case.

## Validation and status

The native KiCad DRC report and independent net/matrix checks are in `checks/`. These checks cover the manufactured PCB connections and geometry, not physical production. **Rev A is an unbuilt prototype**: no hardware, USB enumeration, stabilizer/plate/case fit or firmware build has been tested. Standalone schematic ERC was not run; schematic-to-PCB net agreement is checked separately. Review the mechanical design with the actual parts before ordering a batch.

## Files

Native KiCad project, schematic and routed PCB; self-contained libraries; Gerbers and drill files; plate DXF; layout and PCB SVGs; BOM and coordinate CSVs; matching QMK source; generation/routing scripts and validation reports.

## Sources

- Kailh socket drawing: https://www.kailhswitch.com/uploads/15927/files/CPG151101S11.pdf
- MX socket geometry reference: https://github.com/ai03-2725/MX_V2
- Original module: https://www.waveshare.com/wiki/RP2040-Zero
- Module schematic: https://files.waveshare.com/upload/4/4c/RP2040_Zero.pdf
- QMK RP2040 documentation: https://docs.qmk.fm/platformdev_rp2040

SOD-123 and test point footprints originate from KiCad's standard footprint library. Keyboard/module footprints and project files are included locally. See `sources/KiCad_footprints_copyright.txt` for distribution terms.

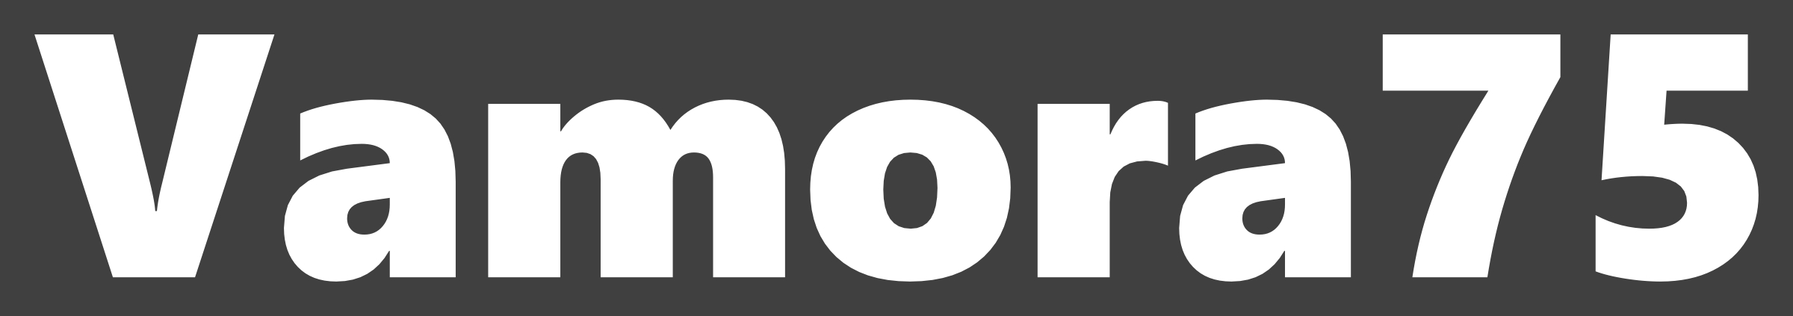
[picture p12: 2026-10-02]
Artwork/Vamora75_name_white.png

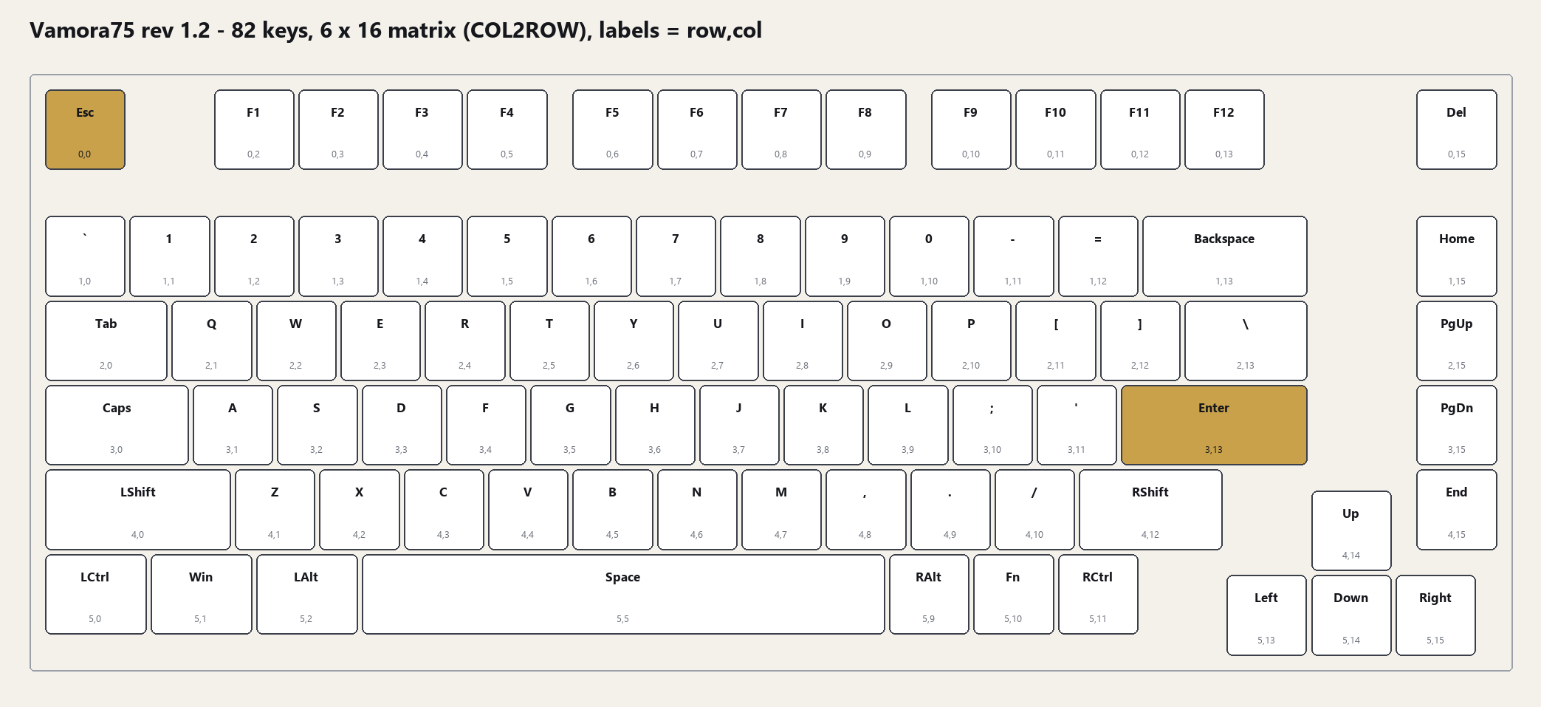
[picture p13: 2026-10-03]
Previews/layout.png

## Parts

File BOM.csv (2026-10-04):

Section | Item | Qty | Specification | Designators | LCSC part | Source / file
Kit | PCBA (this design) | 1 | 2-layer FR4 1.6 mm, black mask, ENIG, bottom-side SMT assembled |  |  | Manufacturing/PCB - JLCPCB/PCBWay
Kit | FR4 plate | 1 | 1.5 mm (1.6 mm fits), black mask, ENIG for the gold name |  |  | Manufacturing/Plate - any PCB fab
Kit | Case top | 1 | PETG/ASA print or CNC 6061 |  |  | Mechanical/Case
Kit | Case bottom | 1 | PETG/ASA print or CNC 6061 (solid wedge, 6 deg) |  |  | Mechanical/Case
Kit | MX-compatible switches | 82 | 3-pin or 5-pin |  |  | user choice
Kit | Keycaps | 82 | 1u x 71, 1.25u x 3, 1.5u x 2, 1.75u x 2, 2u x 1, 2.25u x 2, 6.25u x 1 |  |  | any MX set with a 75 % kit (1.75u RShift, 6.25u space)
Kit | PCB-mount screw-in stabilisers | 4 | 3 x 2u (Backspace, Enter, LShift) + 1 x 6.25u (Space) |  |  | Durock/Cherry/TX
Kit | Gaskets | 16 | 20 x 4.5 x 2 mm Poron 4701-50 or 40A silicone |  |  | Mechanical/Soft DXF
Kit | Case foam | 1 | 3 mm PE / Poron |  |  | Mechanical/Soft DXF
Kit | Plate foam (optional) | 1 | 3.5 mm Poron / PE, with stabiliser/wire windows |  |  | Mechanical/Soft DXF
Kit | Screws | 8 | M3 x 8 ISO 4762 socket head
Kit | Heat-set inserts | 8 | M3 x 4 x 4.0 mm heat-set insert (printed top case; tap M3 if CNC)
Kit | Dowel pins (split print only) | 5 | 3 x 12 mm steel dowel (or printed pin) |  |  | only for the 4-piece printed case
Kit | Bumpers | 4 | 10 x 3 mm silicone bumper
Kit | USB-C cable | 1 | overmould <= 12.3 x 6.5 mm
PCBA (assembled by JLCPCB) | 10uF CL10A106KP8NNNC | 2 | C_0603_1608Metric | C1,C2 | C19702 | Manufacturing/PCB/Vamora75_BOM_JLCPCB.csv
PCBA (assembled by JLCPCB) | 100nF CL05B104KO5NNNC | 10 | Capacitor_0402 | C3,C4,C5,C6,C7,C9,C10,C11,C12,C15 | C1525 | Manufacturing/PCB/Vamora75_BOM_JLCPCB.csv
PCBA (assembled by JLCPCB) | 1uF CL05A105KA5NQNC | 2 | Capacitor_0402 | C13,C14 | C52923 | Manufacturing/PCB/Vamora75_BOM_JLCPCB.csv
PCBA (assembled by JLCPCB) | 15pF 0402CG150J500NT | 2 | Capacitor_0402 | C16,C17 | C1548 | Manufacturing/PCB/Vamora75_BOM_JLCPCB.csv
PCBA (assembled by JLCPCB) | 1N4148W | 82 | Diode_SOD-123 | D1,D2,D3,D4,D5,D6,D7,D8,D9,D10,D11,D12,D13,D14,D15,D16,D17,D18,D19,D20,D21,D22,D23,D24,D25,D26,D27,D28,D29,D30,D31,D32,D33,D34,D35,D36,D37,D38,D39,D40,D41,D42,D43,D44,D45,D46,D47,D48,D49,D50,D51,D52,D53,D54,D55,D56,D57,D58,D59,D60,D61,D62,D63,D64,D65,D66,D67,D68,D69,D70,D71,D72,D73,D74,D75,D76,D77,D78,D79,D80,D81,D82 | C81598 | Manufacturing/PCB/Vamora75_BOM_JLCPCB.csv
PCBA (assembled by JLCPCB) | 500mA SMD0805-050 | 1 | Fuse_0805_2012Metric | F1 | C66452 | Manufacturing/PCB/Vamora75_BOM_JLCPCB.csv
PCBA (assembled by JLCPCB) | HRO TYPE-C-31-M-12 | 1 | USB_C_HRO_TYPE-C-31-M-12 | J1 | C165948 | Manufacturing/PCB/Vamora75_BOM_JLCPCB.csv
PCBA (assembled by JLCPCB) | 5.1k 0402WGF5101TCE | 2 | Resistor_0402 | R1,R2 | C25905 | Manufacturing/PCB/Vamora75_BOM_JLCPCB.csv
PCBA (assembled by JLCPCB) | 27R 0402WGF270JTCE | 2 | Resistor_0402 | R3,R4 | C25100 | Manufacturing/PCB/Vamora75_BOM_JLCPCB.csv
PCBA (assembled by JLCPCB) | 10k 0402WGF1002TCE | 2 | Resistor_0402 | R5,R7 | C25744 | Manufacturing/PCB/Vamora75_BOM_JLCPCB.csv
PCBA (assembled by JLCPCB) | 1k 0402WGF1001TCE | 2 | Resistor_0402 | R6,R8 | C11702 | Manufacturing/PCB/Vamora75_BOM_JLCPCB.csv
PCBA (assembled by JLCPCB) | Kailh CPG151101S11 MX hot-swap socket | 82 | Kailh_CPG151101S11 | SW1,SW2,SW3,SW4,SW5,SW6,SW7,SW8,SW9,SW10,SW11,SW12,SW13,SW14,SW15,SW16,SW17,SW18,SW19,SW20,SW21,SW22,SW23,SW24,SW25,SW26,SW27,SW28,SW29,SW30,SW31,SW32,SW33,SW34,SW35,SW36,SW37,SW38,SW39,SW40,SW41,SW42,SW43,SW44,SW45,SW46,SW47,SW48,SW49,SW50,SW51,SW52,SW53,SW54,SW55,SW56,SW57,SW58,SW59,SW60,SW61,SW62,SW63,SW64,SW65,SW66,SW67,SW68,SW69,SW70,SW71,SW72,SW73,SW74,SW75,SW76,SW77,SW78,SW79,SW80,SW81,SW82 | C5156480 | Manufacturing/PCB/Vamora75_BOM_JLCPCB.csv
PCBA (assembled by JLCPCB) | BOOT TS-1187A-B-A-B | 1 | SW_Push_1P1T_XKB_TS-1187A | SW90 | C318884 | Manufacturing/PCB/Vamora75_BOM_JLCPCB.csv
PCBA (assembled by JLCPCB) | RESET TS-1187A-B-A-B | 1 | SW_Push_1P1T_XKB_TS-1187A | SW91 | C318884 | Manufacturing/PCB/Vamora75_BOM_JLCPCB.csv
PCBA (assembled by JLCPCB) | RP2040 | 1 | QFN-56-1EP_7x7mm_P0.4mm_EP3.2x3.2mm_ThermalVias | U1 | C2040 | Manufacturing/PCB/Vamora75_BOM_JLCPCB.csv
PCBA (assembled by JLCPCB) | USBLC6-2SC6 | 1 | ESD_SOT-23-6 | U2 | C7519 | Manufacturing/PCB/Vamora75_BOM_JLCPCB.csv
PCBA (assembled by JLCPCB) | XC6206P332MR | 1 | Voltage_SOT-23 | U3 | C5446 | Manufacturing/PCB/Vamora75_BOM_JLCPCB.csv
PCBA (assembled by JLCPCB) | W25Q16JVUXIQ | 1 | Winbond_USON-8-1EP_3x2mm_P0.5mm_EP0.2x1.6mm | U4 | C2843335 | Manufacturing/PCB/Vamora75_BOM_JLCPCB.csv
PCBA (assembled by JLCPCB) | 12MHz ABM8-272-T3 | 1 | Crystal_SMD_3225-4Pin_3.2x2.5mm | Y1 | C20625731 | Manufacturing/PCB/Vamora75_BOM_JLCPCB.csv

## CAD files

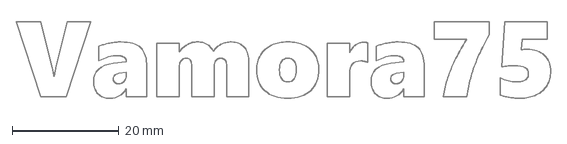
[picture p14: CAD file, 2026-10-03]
Artwork/Vamora75_name_engrave.dxf
100.0 x 14.3 mm

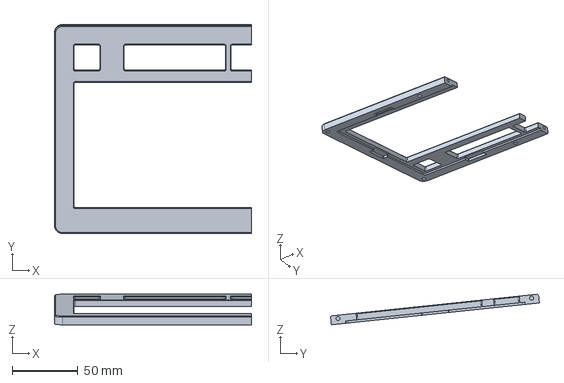
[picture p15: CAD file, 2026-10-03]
Mechanical/Case/print_split/Vamora75_case_top_L.step
149.3 x 158.3 x 23.2 mm

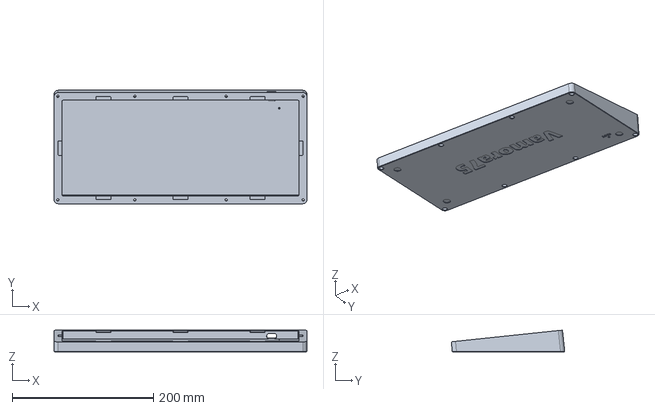
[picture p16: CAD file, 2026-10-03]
Mechanical/Case/Vamora75_case_bottom.step
358.6 x 160.9 x 30.8 mm

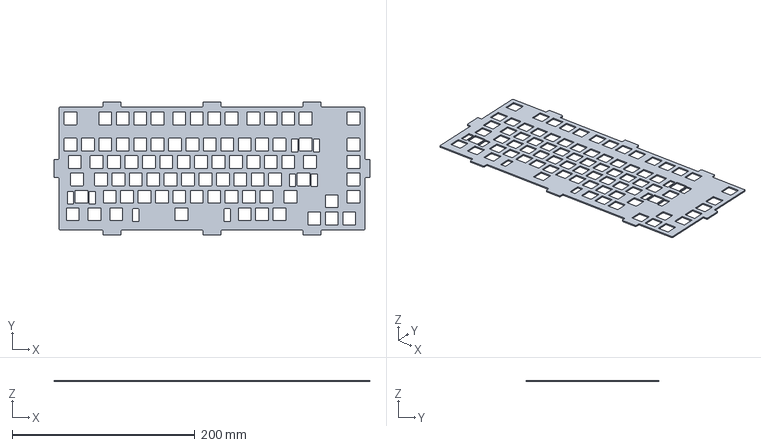
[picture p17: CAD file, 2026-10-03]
Mechanical/Plate/Vamora75_plate_FR4.step
345.6 x 145.6 x 1.50 mm

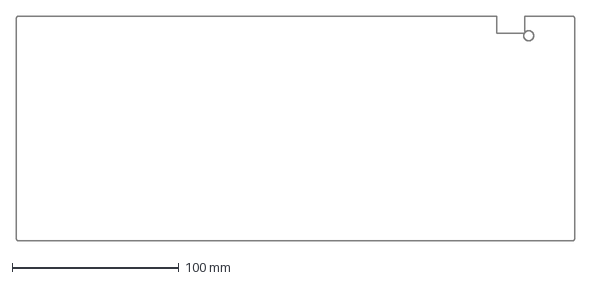
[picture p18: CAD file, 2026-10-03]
Mechanical/Soft/Vamora75_case_foam_3mm.dxf
335.1 x 135.1 mm

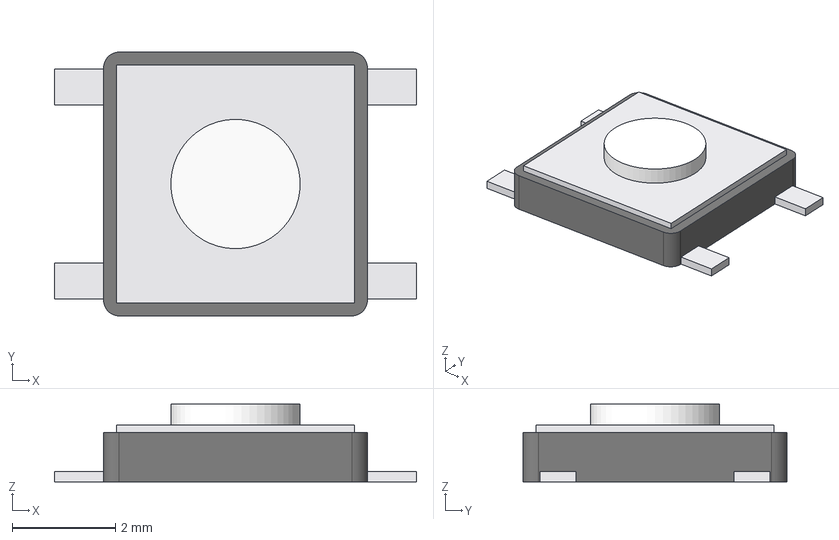
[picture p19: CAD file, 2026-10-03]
PCB/3dmodels/SW_Push_1P1T_XKB_TS-1187A.step
7.00 x 5.10 x 1.50 mm
metal
actuator

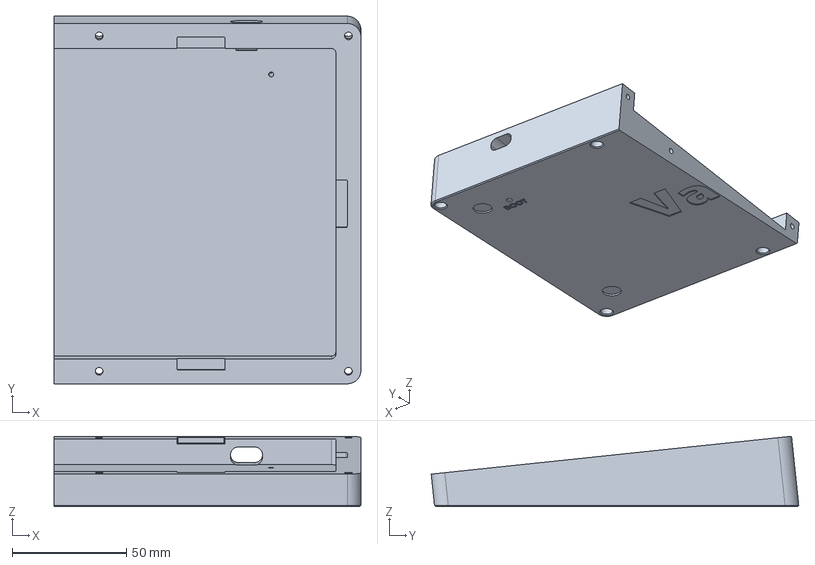
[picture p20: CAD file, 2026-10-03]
Mechanical/Case/print_split/Vamora75_case_bottom_R.step
134.4 x 160.9 x 30.8 mm

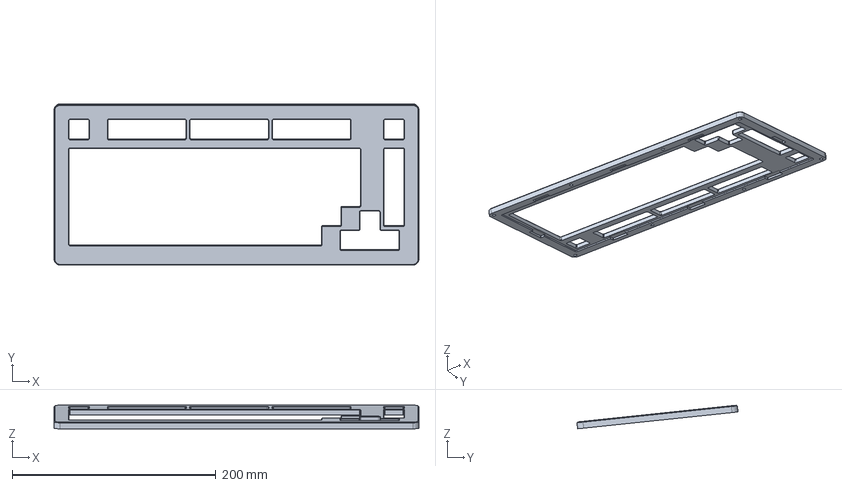
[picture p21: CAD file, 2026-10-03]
Mechanical/Case/Vamora75_case_top.step
358.6 x 158.3 x 23.2 mm

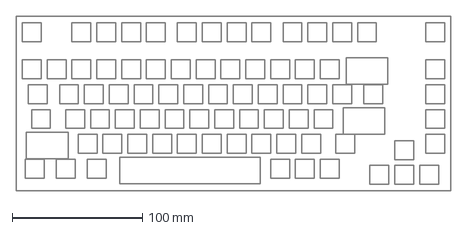
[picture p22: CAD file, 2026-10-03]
Mechanical/Soft/Vamora75_plate_foam_3.5mm.dxf
333.6 x 133.6 mm

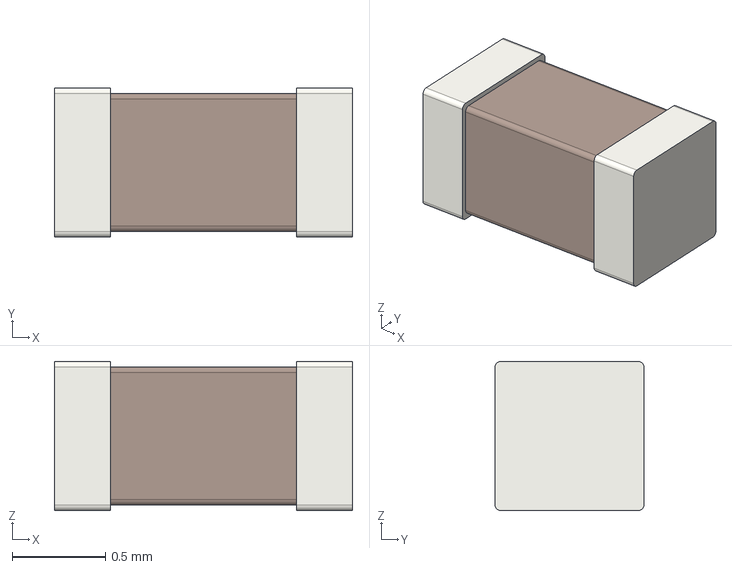
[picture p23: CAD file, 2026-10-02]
PCB/3dmodels/C_0603_1608Metric.step
1.60 x 0.8 x 0.8 mm

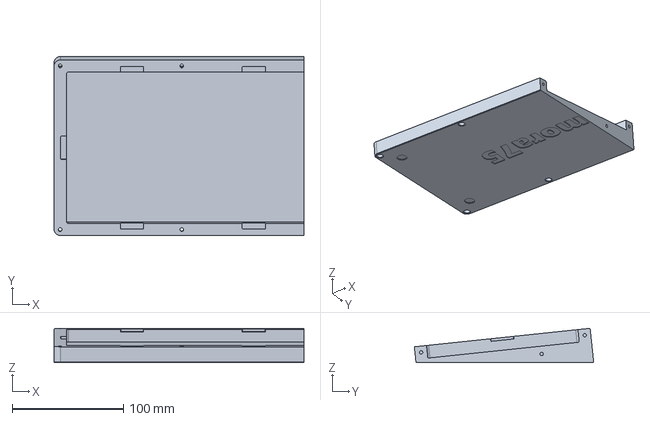
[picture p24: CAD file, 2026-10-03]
Mechanical/Case/print_split/Vamora75_case_bottom_L.step
224.2 x 160.9 x 30.8 mm

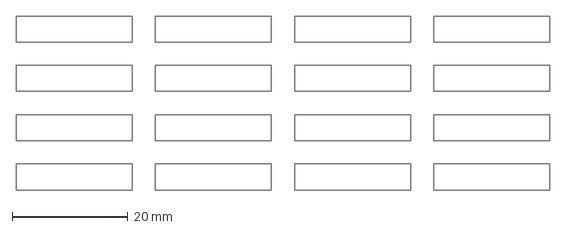
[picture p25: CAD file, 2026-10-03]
Mechanical/Soft/Vamora75_gaskets_16x_20x4.5x2mm.dxf
92.0 x 30.0 mm

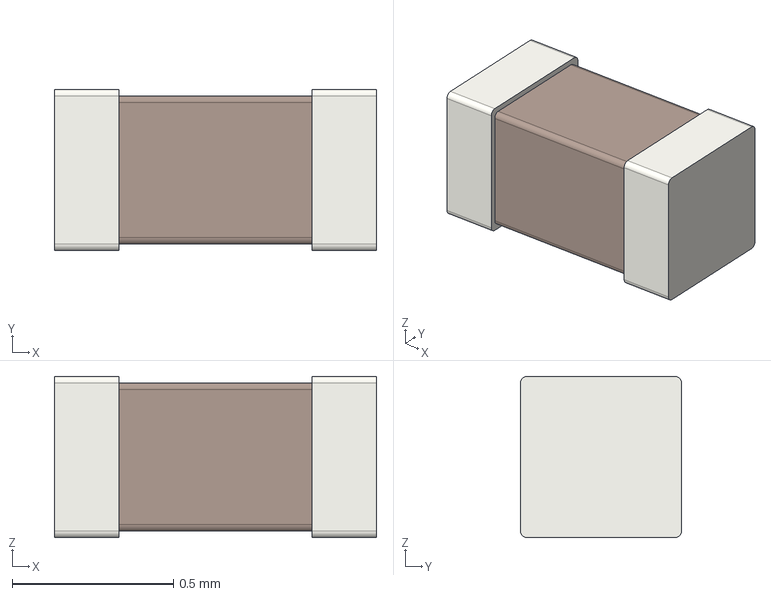
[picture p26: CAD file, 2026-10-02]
PCB/3dmodels/C_0402_1005Metric.step
1.00 x 0.5 x 0.5 mm

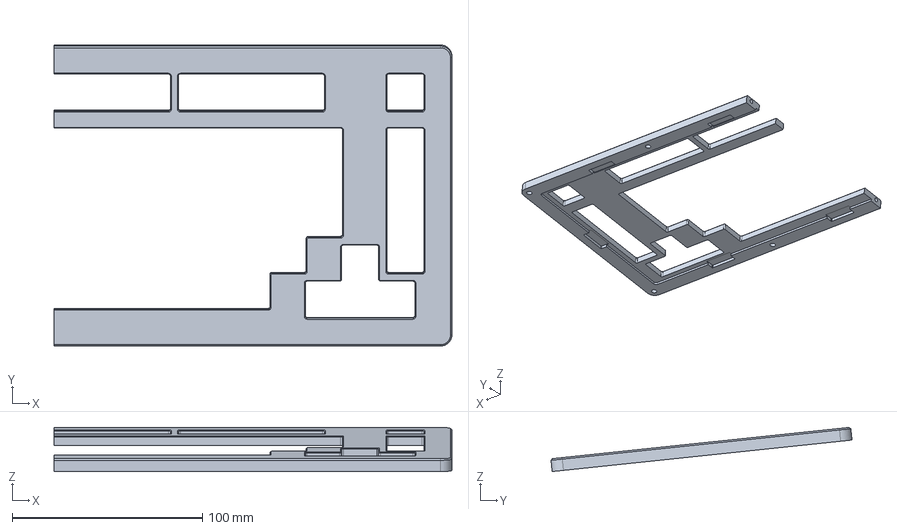
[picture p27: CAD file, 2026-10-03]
Mechanical/Case/print_split/Vamora75_case_top_R.step
209.3 x 158.3 x 23.2 mm

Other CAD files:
Mechanical/Plate/Vamora75_plate_FR4_flexcut.step
PCB/3dmodels/R_0402_1005Metric.step
PCB/3dmodels/Winbond_USON-8-1EP_3x2mm_P0.5mm_EP0.2x1.6mm.step
PCB/3dmodels/Stabilizer_MX_2.00u.step
Mechanical/Case/Vamora75_case_bottom.stl
Mechanical/Case/Vamora75_case_top.stl
Mechanical/Case/print_split/Vamora75_case_bottom_L.stl
Mechanical/Case/print_split/Vamora75_case_bottom_R.stl
Mechanical/Case/print_split/Vamora75_case_top_L.stl
Mechanical/Case/print_split/Vamora75_case_top_R.stl
Mechanical/Plate/Vamora75_plate_FR4.dxf
Mechanical/Plate/Vamora75_plate_FR4.stl
Mechanical/Plate/Vamora75_plate_FR4_flexcut.dxf
Mechanical/Plate/Vamora75_plate_FR4_flexcut.stl
PCB/3dmodels/Crystal_SMD_3225-4Pin_3.2x2.5mm.step
PCB/3dmodels/Diode_SOD-123.step
PCB/3dmodels/Fuse_0805_2012Metric.step
PCB/3dmodels/Hotswap_MX.step
PCB/3dmodels/MX_PCB.step
PCB/3dmodels/QFN-56-1EP_7x7mm_P0.4mm_EP3.2x3.2mm.step
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

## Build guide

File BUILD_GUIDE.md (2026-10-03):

# Vamora75 rev 1.2 - build guide

## 1. Parts

The complete list is [Manufacturing/Vamora75_kit_BOM.csv](Manufacturing/Vamora75_kit_BOM.csv), and
how to order each item is in [Manufacturing/FABRICATION.md](Manufacturing/FABRICATION.md). In short:

* The PCBA. All parts are on the bottom: 82 sockets, 82 diodes, RP2040, flash, crystal, USB-C,
  ESD protection, LDO and buttons. It is assembled by the fab in one pass.
* The FR4 plate (standard or flex-cut) and 16 gaskets (20 x 4.5 x 2 mm).
* Case top and bottom, printed or machined, with 8 M3 x 8 socket-head screws and 8 M3 heat-set
  inserts. A split print also needs 5 dowels (3 x 12 mm).
* 4 PCB-mount screw-in stabilisers: three 2u (Backspace, Enter, LShift) and one 6.25u (Space).
* 82 MX-compatible switches (3- or 5-pin) and a 75 % keycap set (RShift 1.75u, Space 6.25u).
* Optional: 3 mm case foam, 3.5 mm plate foam and 4 bumpers (10 x 3 mm).

Tools: a multimeter, a soldering iron with a heat-set insert tip, a 2.5 mm hex key (long), tweezers
or a bent paper clip, and a USB-C cable whose plug overmould is 12.35 x 6.5 mm or smaller.

## 2. Bring up the bare PCBA (before any mechanical work)

1. **Look it over.** Check the bottom side for bridges at U1 (QFN-56) and U4, and check that every
   socket is flat. Diode cathode bars face pad 1, which is the ROW side.
2. **Check for shorts** with a meter, using the test pads near the controller:
   TP4 (+5V), TP2 (+3V3), TP1 (RUN), TP3 (GND). Neither +5V nor +3V3 may read as a short to GND
   (more than about 100 Ω, rising as the capacitors charge).
3. **Plug in USB.** With blank flash, the RP2040 enumerates as the drive `RPI-RP2`. Measure
   3.3 V (±3 %) between TP2 and TP3.
4. **Flash the firmware**: copy the QMK `.uf2`, or the CircuitPython UF2 plus its 4 files (see
   [Firmware/README.md](Firmware/README.md)).
5. **Test the matrix.** Open the VIA key tester (usevia.app -> Key Tester) or
   https://config.qmk.fm/#/test. Short each socket by touching both of its contacts through the two
   3 mm switch-pin holes from the top, using tweezers. All 82 keys must register, and each must
   register only once. The silkscreen has no key legends (the front carries the big "Vamora75", the
   back the poem and the designers' names); use `Previews/layout.png` or
   `Manufacturing/PCB/Vamora75_assembly_bottom.pdf` to find a key.

## 3. Stabilisers, switches, plate

6. **Stabilisers.** Clip and lube them if you like, then fit the four screw-in stabilisers on the
   PCB top (ScottoKicad `Stabilizer_MX` footprints, marked ST1-ST4 on the fabrication layer). Each
   housing clips into the small 3.05 mm hole at the rear and is screwed through the large 3.99 mm
   hole at the front; the screw heads (with washers if your set has them) sit on the bottom on the
   6 mm gold reinforcement rings. All four are in the standard orientation: wire toward the front
   (toward you). Tighten the screws snugly, not hard. Check that each housing sits flat on the PCB.
7. **Plate foam (optional).** Lay the 3.5 mm foam on the PCB top. It has a window around each
   stabiliser and its wire, so nothing presses on the housings.
8. **Switches.** Lower the plate over the PCB so the stabiliser housings come up through their
   openings (7.0 x 14 mm, they pass without force). Clip four switches into the plate corners (Esc,
   Del, LCtrl, Right), line up the plate with the PCB, and press those switches into their sockets.
   Then fit the rest, and check that every stabilised key returns freely.
   **Support the sockets from below** as you press. The USB-C receptacle stands 3.3 mm below the
   PCB, taller than the sockets (1.85 mm), so let that corner hang over the edge of the table, or
   rest the PCB on the case foam. Straighten any bent switch pin rather than forcing it.

## 4. Case

9. **Heat-set inserts.** Press the 8 M3 inserts into the underside of the top case (the parting
   face) with an iron at about 220-240 °C for PETG/ASA. Keep them straight and flush.
   For a machined case, tap M3 instead (2.5 mm pilot).
10. **Split print only.** Glue each pair of halves with 3 x 12 mm dowels: 2 in the top seam, 3 in the
    bottom seam. Use epoxy or CA, and clamp the halves on a flat surface.
11. **Case foam.** Lay the 3 mm foam in the bottom case. It has cut-outs for the USB-C receptacle and
    the BOOT pin-hole.
12. **Gaskets.** Stick 8 gaskets onto the floors of the 8 pockets in the bottom case. Stick the other
    8 either on top of the plate tabs or onto the pocket ceilings of the top case.
13. **Drop in the PCB and plate as one unit.** The USB-C goes to the rear right, in line with the
    tunnel, and each tab rests on its lower gasket. The PCB and plate must not touch the case walls
    anywhere (there is 1 mm of clearance all round).
14. **Close the case.** Put the top case on, then drive the 8 M3 x 8 screws in from below. The rear
    counterbores are deep, so use a long hex key. Tighten in a cross pattern only until the two halves
    meet: the pockets already set the gasket compression (1.6 mm, 20 %), so overtightening only
    strains the inserts.
15. **Finish.** Fit the keycaps and the 4 bumpers in their recesses, then test every key again.
    Also test Fn+F1-F12, NKRO (Fn+N), sleep/wake and replugging the cable.

## 5. Reference data

Z stack, measured perpendicular to the plate, from the PCB top surface (0):

| Item | Z (mm) |
|---|---:|
| Case floor | -7.1 |
| Case foam (3 mm) | -7.1 to -4.1 |
| Lowest bottom-side part (USB-C) | -4.9 |
| Sockets (bottom of body) | -3.45 |
| PCB | -1.6 to 0 |
| Plate foam (optional) | 0 to 3.5 |
| Lower gasket seat / plate / upper gasket seat | 1.9 / 3.5-5.0 / 6.6 |
| Case parting plane | 4.25 |
| Top-case lip underside | 6.0 |
| Top of case | 11.0 |

The whole frame is tilted 6° about the front-bottom edge. The front edge of the case is 21.0 mm
high and the rear is 37.6 mm.

**Entering the bootloader later:** press Fn+Esc, hold Esc while plugging in, or double-tap RESET
(QMK). Last resort: push a paper clip through the pin-hole marked BOOT on the case bottom (rear
left as you look at the bottom) while plugging in.

**Hand-assembly alternative:** if your fab cannot source the Kailh sockets, order the PCBA without
them and hand-solder the 82 sockets (two large pads each). The controller parts (0.4 mm-pitch QFN)
should still be machine-assembled.

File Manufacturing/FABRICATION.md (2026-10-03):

# Vamora75 rev 1.2 - fabrication

Everything here is generated by `Source/export_manufacturing.py` from `PCB/` and `Plate/`.
Regenerate it after any design change.

## 1. Main PCB + assembly (PCBA)

Files in `PCB/`:

| File | Use |
|---|---|
| `Vamora75_gerbers_JLCPCB.zip` | Gerber X2 (9 layers) + Excellon drill (PTH and NPTH) + drill maps |
| `Vamora75_BOM_JLCPCB.csv` | 19 lines, 197 placements, all with LCSC part numbers |
| `Vamora75_CPL_JLCPCB.csv` | Positions: origin at the board's lower-left corner, mm. Every placement is on the **Bottom** side. The ScottoKicad switch footprints sit on the top layer in KiCad, but the Kailh socket they carry is a bottom-side part, so the CPL reports sockets as Bottom, rotated 180, at the socket body centre (-0.62, +3.81 mm from the switch centre). |
| `Vamora75_schematic.pdf`, `Vamora75_assembly_bottom.pdf` | Review and hand-assembly drawings (the bottom view is mirrored so it reads correctly) |
| `gerbers/` | The same files unzipped, for viewers |

Board order settings (JLCPCB names):

| Setting | Value |
|---|---|
| Layers | 2 |
| Dimensions | 334.61 x 134.59 mm |
| Thickness | 1.6 mm, FR-4 |
| Outer copper | 1 oz |
| Min. track / space | 0.15 / 0.15 mm (0.15 mm clearance only in the RP2040, flash and USB fan-outs) |
| Min. via | 0.45 mm pad / 0.2 mm drill (standard price at 0.45 mm and up) |
| Surface finish | **ENIG** (the design assumes it: flat 0.4 mm QFN pads and the gold stabiliser rings). HASL lead-free also works |
| Mask / silkscreen | **Black** / white (set in the KiCad stackup). The top silkscreen carries a 240 mm "Vamora75" across the middle, the bottom silkscreen the *Nam Quốc Sơn Hà* poem. Keep vias tented (the default for KiCad Gerbers): both artworks print over them. |
| Order number | Choose "Specify location" or "Remove", so it does not land on the artwork |
| Plated holes | The 16 stabiliser holes are plated (finished 3.05 / 3.99 mm) with exposed copper rings; they are in the PTH drill file. No castellated or edge-plated features |

Assembly settings: **assemble the bottom side**, Economic or Standard (JLCPCB tells you if a part
needs Standard), tooling holes added by JLCPCB.

| Part | LCSC | Notes |
|---|---|---|
| Kailh CPG151101S11 socket x 82 | C5156480 | Check stock; if unavailable, hand-solder (BUILD_GUIDE §5) |
| RP2040 | C2040 | Extended part |
| W25Q16JVUXIQ | C2843335 | 2 MB, the same flash as the Raspberry Pi Pico |
| ABM8-272-T3 12 MHz | C20625731 | RP2040-approved crystal (15 pF + 1 kΩ) |
| HRO TYPE-C-31-M-12 | C165948 | |
| USBLC6-2SC6 / XC6206P332MR / PTC 0.5 A | C7519 / C5446 / C66452 | |
| 1N4148W x 82 | C81598 | Cathode (pad 1) to ROW |
| TS-1187A x 2 (BOOT, RESET) | C318884 | |
| Passives | C1525, C19702, C52923, C1548, C25905, C25100, C25744, C11702 | 0402 / 0603 |

**Before paying, check the placement preview for every bottom part**: socket orientation (its two
metal tabs on the two large pads), the U1 pin-1 dot, the U4 pin-1 dot, the D1-D82 cathode bars on
the ROW pad, and the J1 opening at the board edge. Bottom-side rotations are the most common CPL
error. Test pads TP1-TP4 and fiducials FID1-FID3 are deliberately left out of the BOM and CPL.

## 2. FR4 plate (order it as a PCB)

Files in `Plate/`: `Vamora75_Plate_gerbers.zip` (standard) and `Vamora75_Plate_flexcut_gerbers.zip`
(relief slots behind each gasket tab). The KiCad sources are in `../Plate/`.

| Setting | Value |
|---|---|
| Layers | 2 (copper is used only for the "Vamora75" name) |
| Thickness | **1.5 mm** if offered, otherwise 1.6 mm (fits; gaskets compress about 0.05 mm more) |
| Surface finish | **ENIG** gives a gold name; HASL gives silver |
| Mask / silkscreen | Black recommended / white |
| Notes | 98 routed openings, no drilled holes, stabiliser openings 7.0 x 14 mm, minimum web 1.44 mm, slots 1.2 mm |

The plate is also provided as DXF and STEP (`../Mechanical/Plate/`) for laser-cut aluminium, brass,
POM or PC. Use the same outline. For metal plates, check that the switch clips fit the thickness.

## 3. Case

`../Mechanical/Case/`: one-piece STEP/STL for CNC or for printers with a bed of 360 mm or more.
`../Mechanical/Case/print_split/`: four pieces (the largest is about 224 x 161 mm) for 250 x 210 mm beds.
The seams are staggered, and each one has dowel holes (3.1 mm, 6 mm deep per side). The bottom seam is placed in a gap between two letters of the engraved name.

* **3D printing (PETG or ASA):** print the bottom on its flat underside (the engraved "Vamora75" prints
  as a 0.6 mm recess in the first layers), and print the top upside down (keyboard face on the bed;
  the bridges between key clusters then print flat on the bed, no supports).
  Use 0.2 mm layers, 4 walls, 20 % gyroid infill and 5 top/bottom layers. The insert holes are
  4.0 mm for M3 x 4 heat-set inserts.
* **CNC (6061-T6):** use the one-piece STEP. Tap M3 instead of using inserts. The solid wedge under
  the floor can be pocketed from below to save weight; keep 2.5 mm under the floor and leave the
  screw bosses solid.

## 4. Soft parts (`../Mechanical/Soft/`, DXF in mm)

| File | Material |
|---|---|
| `Vamora75_gaskets_16x_20x4.5x2mm.dxf` | 2.0 mm Poron 4701-50 or 40A silicone, adhesive-backed |
| `Vamora75_case_foam_3mm.dxf` | 3 mm PE or Poron |
| `Vamora75_plate_foam_3.5mm.dxf` | 3.5 mm Poron or PE (optional); square switch openings plus one window per stabilised key |

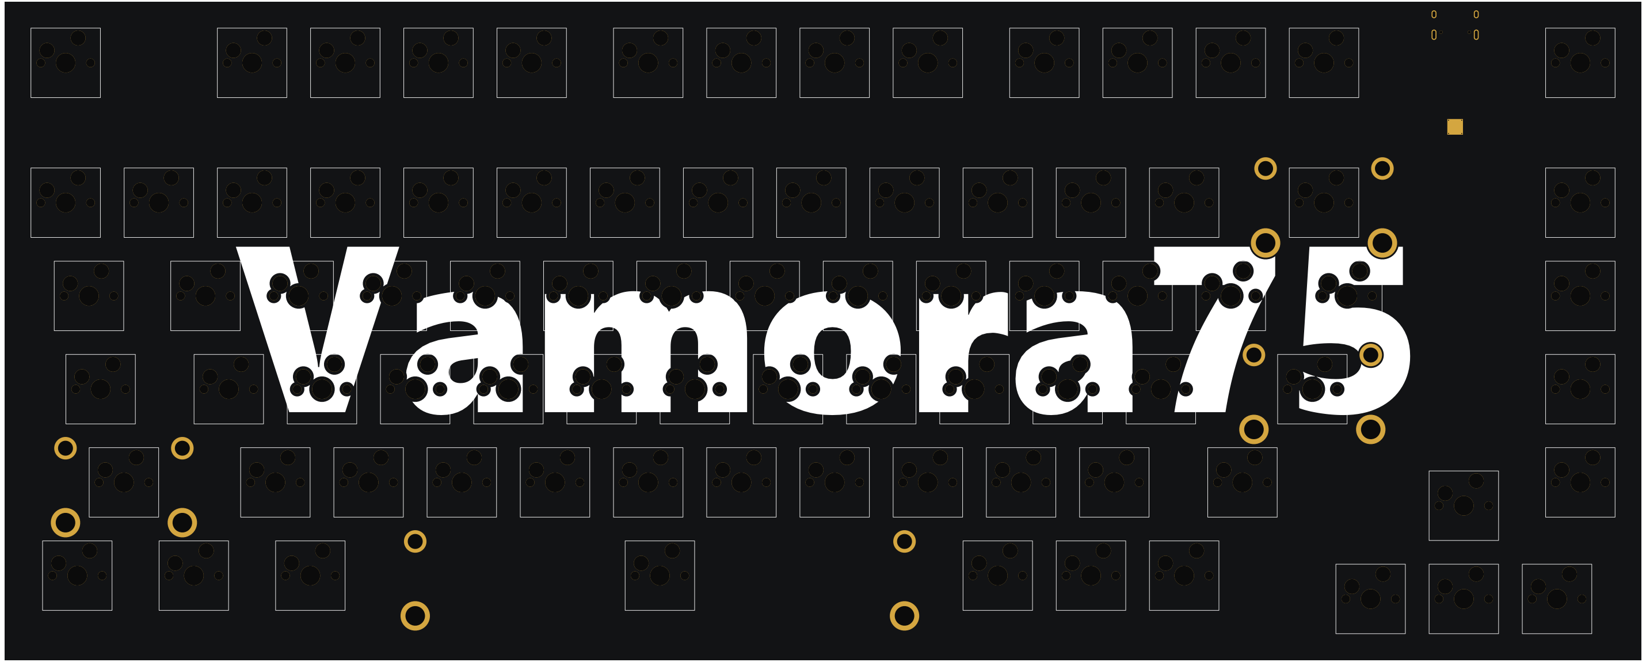
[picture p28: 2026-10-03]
PCB/build/artwork_front_view.png

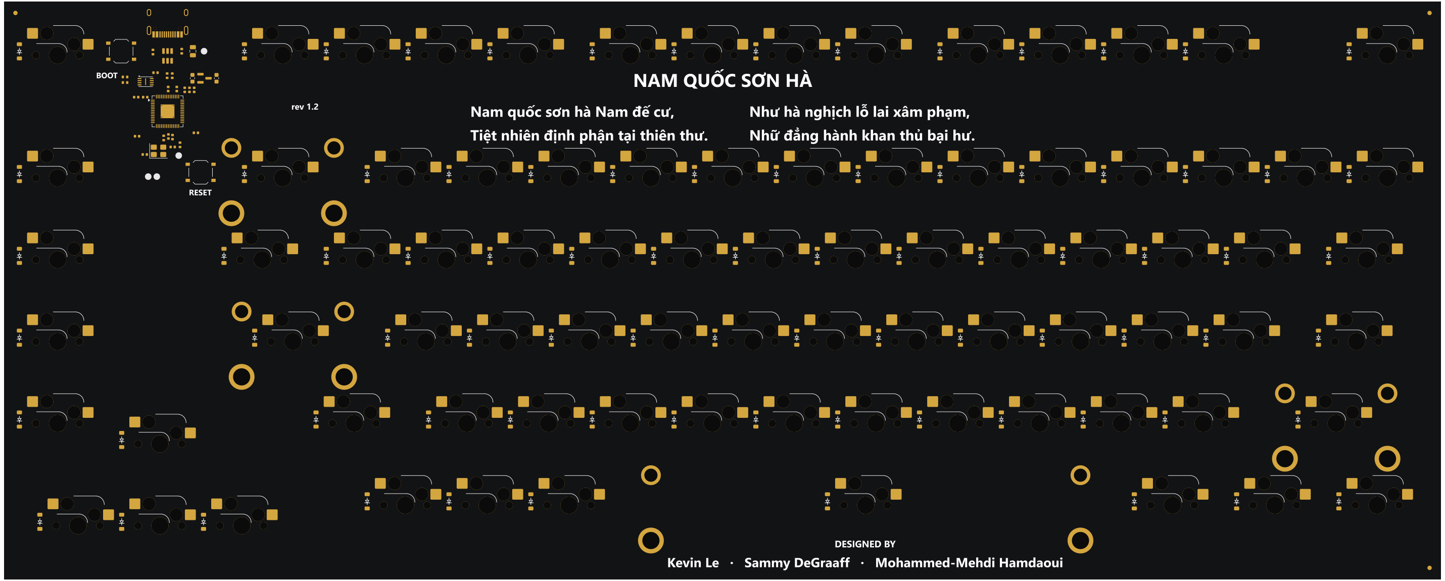
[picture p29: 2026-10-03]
PCB/build/artwork_bottom_view.png

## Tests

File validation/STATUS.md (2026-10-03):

# Vamora75 rev 1.2 - validation status

Generated 2026-10-03 by `Source/build_all.py`. These are digital checks of the
design files; no board has been built or tested yet (see BUILD_GUIDE.md, bring-up).

| Check | Result |
|---|---|
| Schematic ERC (KiCad 10, all severities) | clean |
| PCB DRC violations (all severities, zones refilled) | clean |
| PCB unconnected items | clean |
| Schematic <-> PCB parity | clean |
| Vamora75_Plate DRC / unconnected | clean / clean |
| Vamora75_Plate_flexcut DRC / unconnected | clean / clean |
| Plate min. FR4 web (switch-stab) | 1.438 mm |
| Mechanical interference (14 pairs, incl. stabilisers through plate and foam, keycaps bottomed out, USB-C plug) | PASS |
| PCBA bottom parts to case floor | 2.1 mm |
| USB-C plug clearance in tunnel (side / vertical) | 0.825 / 0.75 mm |
| Firmware checks (QMK/VIA/KLE vs layout, netlist vs pins, CircuitPython HID) | 30/30 pass |

Not verified here: QMK compilation (no toolchain in the build environment), JLCPCB part stock and
rotations in their placement preview, physical fit of printed parts, USB enumeration, typing feel.

Raw reports: `erc.json`, `drc.json`, `mechanical.json`, `plate.json`, `firmware.json`, `schematic.net.xml`.

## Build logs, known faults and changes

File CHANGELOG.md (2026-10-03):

# Changelog

## rev 1.2 - 2026-10-03

Designed by Kevin Le, Sammy DeGraaff and Mohammed-Mehdi Hamdaoui.

**Stabilisers (PCB-mount, screw-in)**
- Plate: the stabiliser openings are **7.0 mm wide** (were 6.75 mm), still 14 mm long. A 3D check
  against Joe Scotto's stabiliser model showed its housing is 6.8 mm wide where it passes through
  the plate, so the 6.75 mm opening would have rubbed it. The new opening leaves 0.1 mm a side
  even for that housing.
- PCB: the stabiliser holes are now **plated, with copper reinforcement rings** on both sides
  (4.6 mm rings on the 3.05 mm holes, 6.0 mm rings on the 3.99 mm screw holes, exposed and gold
  with ENIG). The plated barrels and rings stiffen the board where the screws and washers clamp it
  and where the housings sit. The finished hole sizes are unchanged. The bottom-layer keep-outs now
  extend 0.5 mm beyond each ring, and two column traces near LShift were re-routed around the rings.
- Plate foam: one window per stabilised key over both housings and the wire. Close to the PCB the
  housing base is longer than the plate opening, so the old foam cut-outs would have pressed on it.
- Two new interference checks: plate x stabilisers and plate foam x stabilisers (both 0 mm³).

**Top case**
- The opening now **follows the key clusters** instead of being one rectangle over the key field:
  the case covers every gap between clusters (Esc-F1, the band under the F-row, the gaps between the
  F-key groups, the area around Del and the nav column, around the arrows and under the bottom row),
  so the plate is no longer visible inside the keyboard. Each key keeps at least 0.7 mm of clearance
  around its keycap; the narrowest bridge between clusters is 4.3 mm wide and sits 1 mm above the
  plate, so the plate still floats on its gaskets. The gold name on the plate is now under the case.

**PCB**
- **Black solder mask**, white silkscreen, ENIG finish: set in the board stackup, so KiCad's 3D
  viewer, the renders and the fabrication notes all show the black board.
- The back silkscreen adds the designers: "DESIGNED BY Kevin Le · Sammy DeGraaff ·
  Mohammed-Mehdi Hamdaoui", under the space bar. The poem and the name on the front are unchanged.
- The title blocks name the team instead of countries.
- The board file had lost all of its footprint-to-schematic links during a KiCad editing session;
  the rebuild restored them (schematic parity is clean). The schematic labels that were tidied by
  hand in that session (power symbols near the RP2040, the crystal value) are kept.

**3D model and renders**
- Sculpted keycaps (Cherry-like row profile with a dished top) replace the flat CAD keycaps in the
  assembly and the renders.
- `Mechanical/Vamora75_assembly.step` now keeps KiCad's colours: black solder mask, white silkscreen,
  gold pads, and the real colours of every part, including Scotto's switches.
- New: **`Mechanical/Vamora75_PCB_plate.step`** and **`.glb`**, the PCB, plate and every component
  (switches, stabilisers, sockets, SMD parts) without the case. The .glb opens in Windows 3D Viewer
  or any web glTF viewer.
- New renders with studio lighting, physically based materials, ambient occlusion and soft
  shadows, plus a top view and a PCB + plate view. KiCad renders use the board's stackup colours.
- New colourway: graphite case, bone alphas, slate modifiers, brass Esc and Enter.

**Docs**
- README rewritten. References to countries and flags were removed from the files, the firmware
  headers and the colour palette (the archived revisions are unchanged).

The rev 1.1 outputs are kept in `Archive/rev1.1_outputs.zip`.

## rev 1.1 - 2026-10-02

**Layout**
- The arrow cluster moved **0.25u left and 0.25u down**. Up no longer touches End, and Right no
  longer sits in the Del/Home/PgUp/PgDn/End column; there is a 0.25u gap on both sides. The PCB,
  plate and case are 4.76 mm deeper (PCB 334.61 x 134.59 mm).

**Joe Scotto's ScottoKicad library**
- Switch footprints are now ScottoKicad `Hotswap_MX_*` (Kailh CPG151101S11 on B.Cu), and the
  stabilisers are separate ScottoKicad `Stabilizer_MX_2.00u/6.25u` footprints.
- The diode, HRO USB-C, 0402 R/C and SOT-23(-6) footprints also come from ScottoKicad. Their pads
  are identical to the KiCad-stock parts they replace, so the controller routing is unchanged.
- His 3D models are used: socket, MX switch, stabilisers, USB-C, diode, and the MX keycaps in the
  assembly STEP and renders. His MX switch model is shown on every switch footprint, so the
  KiCad 3D viewer and `Mechanical/Vamora75_PCBA.step` show the board with switches fitted.

**Branding**
- No logo. The PCB **front** carries one very large "Vamora75" (240 mm wide) across the middle,
  knocked out around every hole and exposed pad; Scotto's switch outlines run through the letters.
  The case bottom is engraved "Vamora75" (180 mm), and the plate carries "Vamora75" in gold.
- The PCB **back** keeps *Nam Quốc Sơn Hà*, now centred under the F-row and larger than in rev 1.0
  (2.4 mm letters, title over the two couplets), next to the BOOT/RESET labels and "rev 1.1".
- Removed from the PCB: the badge, tagline, credits and per-key legends.

**Board**
- Re-routed: row lines jog to the lowered arrows, column 15 and the ROW5 feed were re-planned, and a
  router clean-up step removes vias left connected on one layer only.
- ERC, DRC, unconnected items and schematic parity are all clean again.
- CPL: the sockets are reported as bottom-side parts (the ScottoKicad switch footprints sit on the
  top layer).

**Everything else** (plate, case, foams, firmware layout data, renders, Gerbers, BOM/CPL) was
regenerated for the new outline. The rev 1.0 outputs are kept in `Archive/rev1.0_outputs.zip`.

## rev 1.0 - 2026-10-02

The whole design was rebuilt from the same layout. See [DESIGN_REVIEW.md](DESIGN_REVIEW.md) for the reasons.

**Electronics**
- The RP2040-Zero module is replaced by an RP2040 on the board, using the Pico core circuit:
  W25Q16JV flash, 12 MHz ABM8-272-T3 crystal, XC6206 3.3 V LDO, USBLC6-2SC6 ESD protection, 0.5 A
  PTC fuse, HRO TYPE-C-31-M-12 at the rear edge, BOOT and RESET buttons, and 4 test pads.
- Matrix changed from 7 x 12 to 6 x 16 COL2ROW, with a crossing-free GPIO map and GP9-15/GP25 left free.
- New footprints for the Kailh CPG151101S11 sockets (1u-6.25u, PCB-mount stabiliser holes), with
  3D models of the socket, the MX switch, the USB-C receptacle and the tact switch.
- Re-routed from scratch on 2 layers with a GND pour on both. All parts are on the bottom side.
  ERC, DRC, unconnected items and schematic parity are all clean in KiCad 10.0.6.
- JLCPCB BOM (LCSC numbers) and CPL, Gerbers/drill, schematic PDF and bottom assembly drawing.

**Plate**
- MX openings with 0.5 mm router corners and ai03 "MX simple" stabiliser openings. All stabilisers
  are in the standard orientation (the spacebar was reversed in rev 0.1).
- 8 gasket tabs (rev 0.1 had 6), an optional flex-cut variant, and a gold ENIG emblem and wordmark in
  the visible gaps. Ordered as a KiCad board.

**Case**
- 6° wedge (rev 0.1 was flat), 21.0 mm at the front and 37.1 mm at the rear.
- Tab-gasket sandwich kept: 16 gaskets with pockets sized for 20 % compression.
- M3 x 8 screws into heat-set inserts (rev 0.1 tapped printed pilots and cut screws to length).
- 4-piece print split for 250 x 210 mm beds, with dowels.
- USB tunnel sized for the largest USB-IF overmould, BOOT pin-hole, bumper recesses, and the badge
  engraved on the bottom.
- 12 automated interference checks: case, PCBA, plate, gaskets, switches, keycaps pressed down,
  and the USB plug.

**Firmware**
- QMK data-driven `keyboard.json` + default and VIA keymaps, VIA definition, CircuitPython for the
  Pico UF2, and KLE layout. 30 automated checks, including netlist vs. firmware pins.

**Brand**
- A badge logo (keycap emblem and wordmark) on the PCB silkscreen, the plate and the case engraving,
  with SVG/PNG/DXF files (replaced by the plain name in rev 1.1). *Nam Quốc Sơn Hà* stays on the PCB.

**Project**
- Everything is generated by `Source/build_all.py` and validated in `validation/STATUS.md`.
- The superseded rev 0.1 files are kept unchanged in `Archive/rev0.1/`.

## rev 0.1 - 2026-10-01

The first coordinated design: RP2040-Zero module under the PCB, Kailh hot-swap, FR4 plate, flat
printed tab-gasket case and CircuitPython firmware. See `Archive/rev0.1/README.md`.

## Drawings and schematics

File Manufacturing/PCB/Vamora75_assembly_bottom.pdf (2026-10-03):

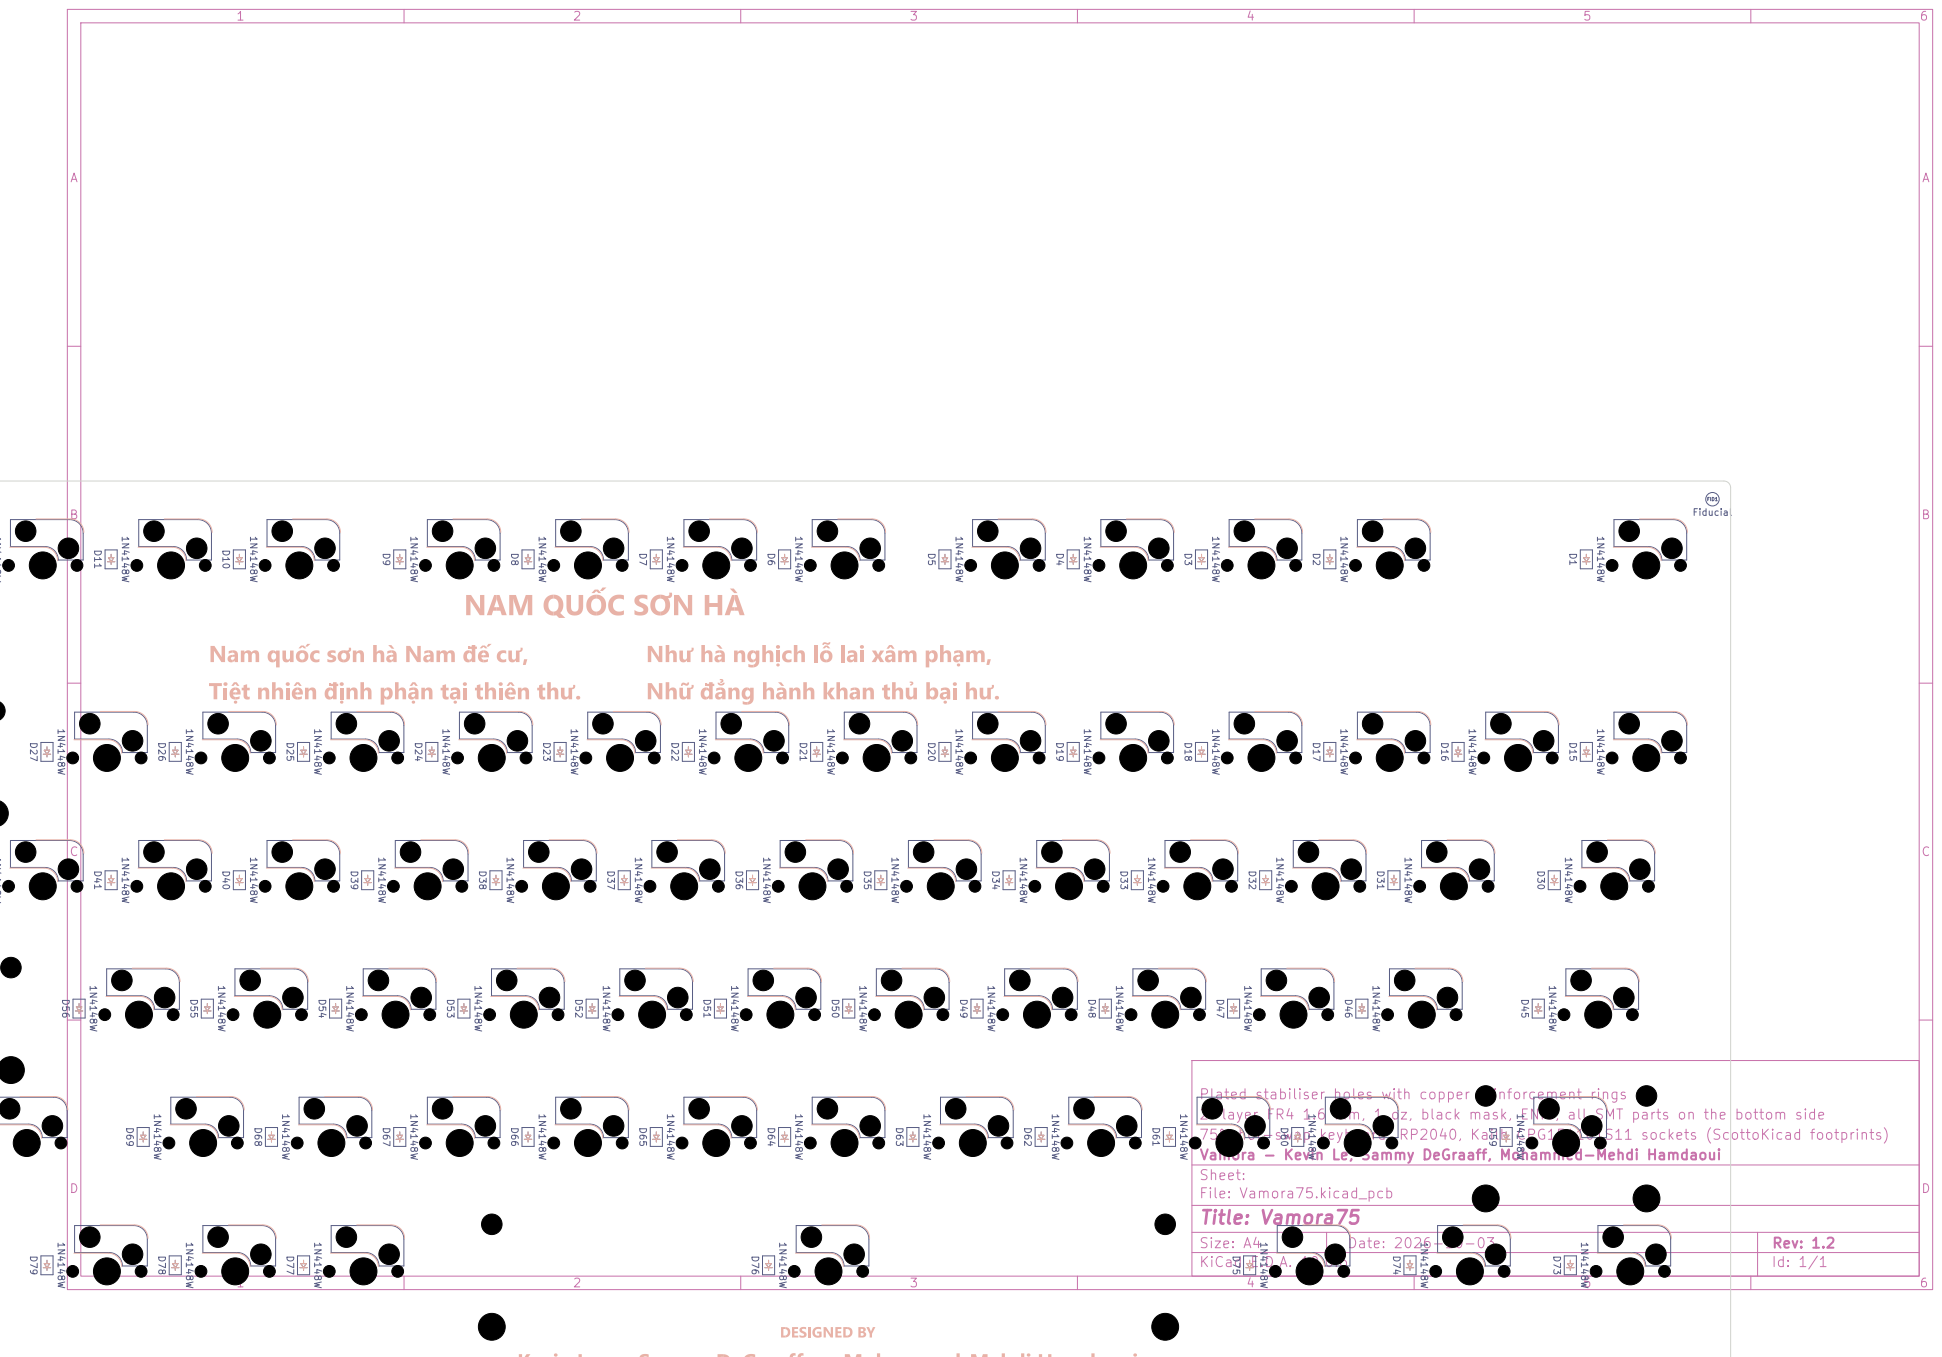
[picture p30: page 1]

Vamora - Kevin Le, Sammy DeGraaff, Mohammed-Mehdi Hamdaoui
Sheet: File: Vamora75.kicad_pcb | D Date: 2026-10-03

Title: Vamora75
Size: A4 | | Rev: 1.2

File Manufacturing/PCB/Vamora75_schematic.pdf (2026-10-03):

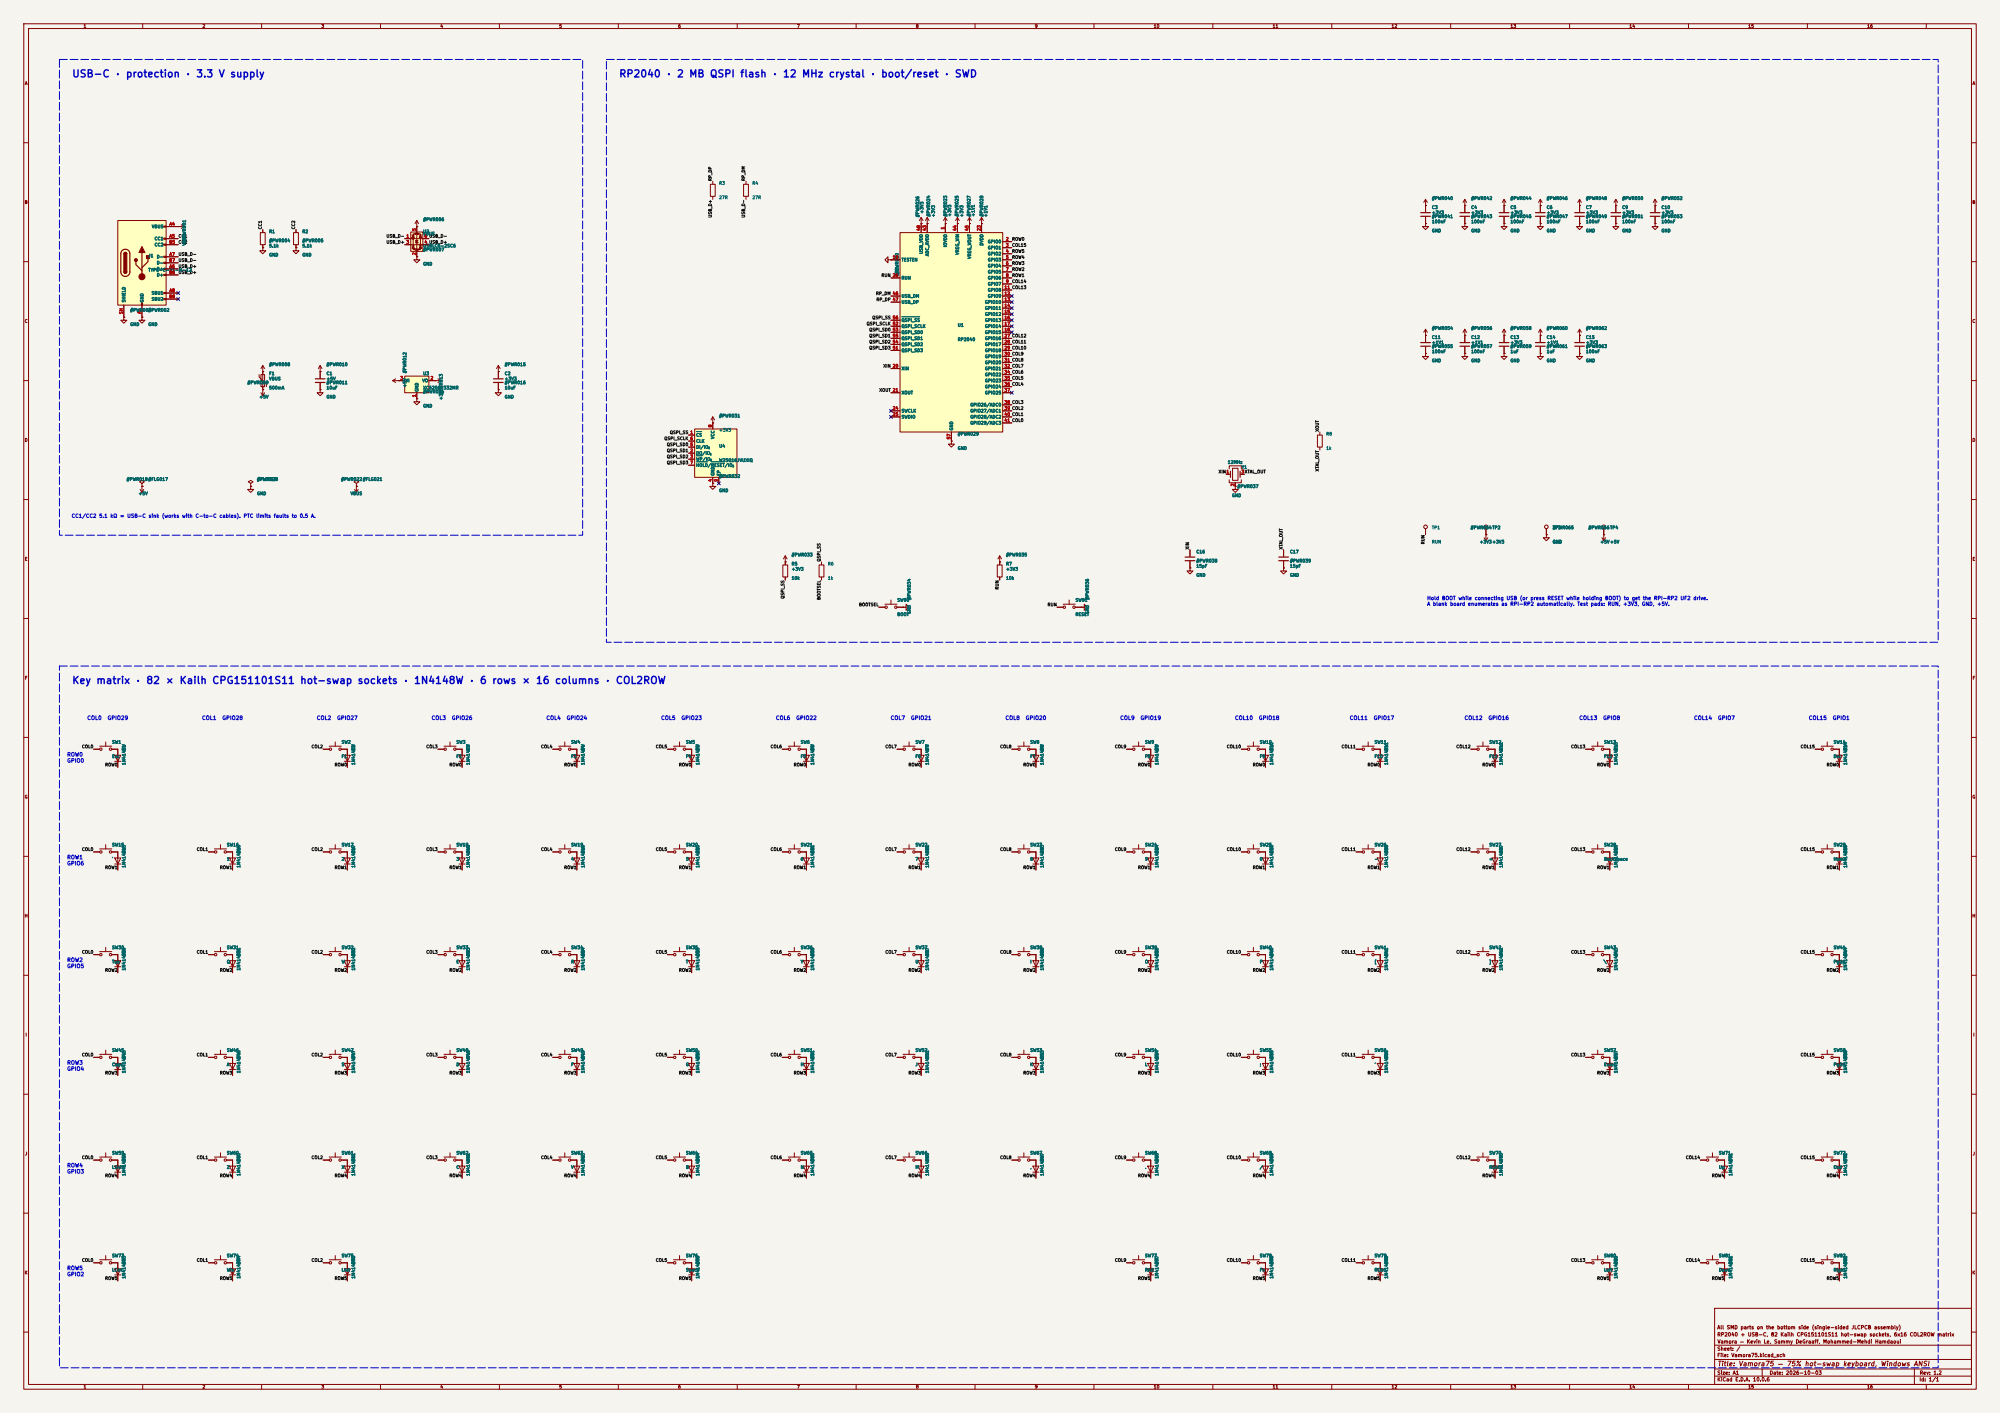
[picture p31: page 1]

RP2040 · 2 MB QSPI flash · 12 MHz crystal · boot/reset · SWD

4 DI/IO0 5 CLK 6 HOLD/RESET/IO3 7 VCC

Hold BOOT while connecting USB (or press RESET while holding BOOT) to get the RPI-RP2 UF2 drive.
A blank board enumerates as RPI-RP2 automatically. Test pads: RUN, +3V3, GND, +5V.

Key matrix · 82 × Kailh CPG151101S11 hot-swap sockets · 1N4148W · 6 rows × 16 columns · COL2ROW

RP2040 + USB-C, 82 Kailh CPG151101S11 hot-swap sockets, 6x16 COL2ROW matrix Vamora — Kevin Le, Sammy DeGraaff, Mohammed-Mehdi Hamdaoui

Sheet: / File: Vamora75.kicad_sch

Title: Vamora75 — 75% hot-swap keyboard, Windows ANSI
Size: A1 | Rev: 1.2
KiCad E.D.A. 10.0.6 | Id: 1/1

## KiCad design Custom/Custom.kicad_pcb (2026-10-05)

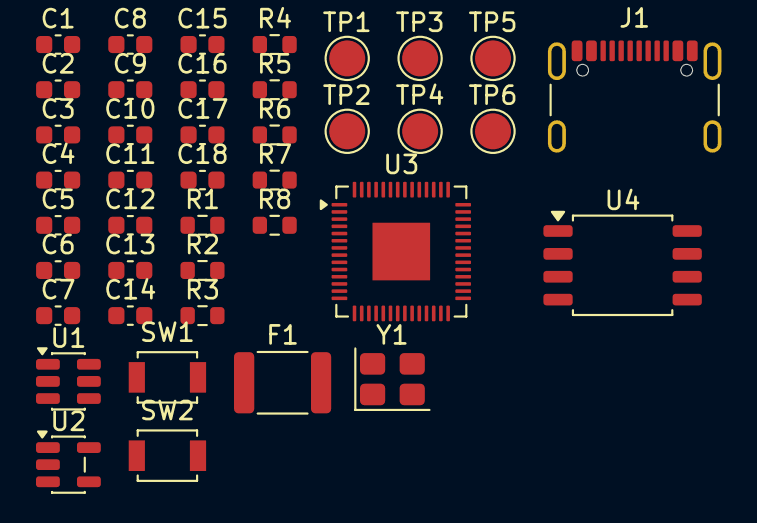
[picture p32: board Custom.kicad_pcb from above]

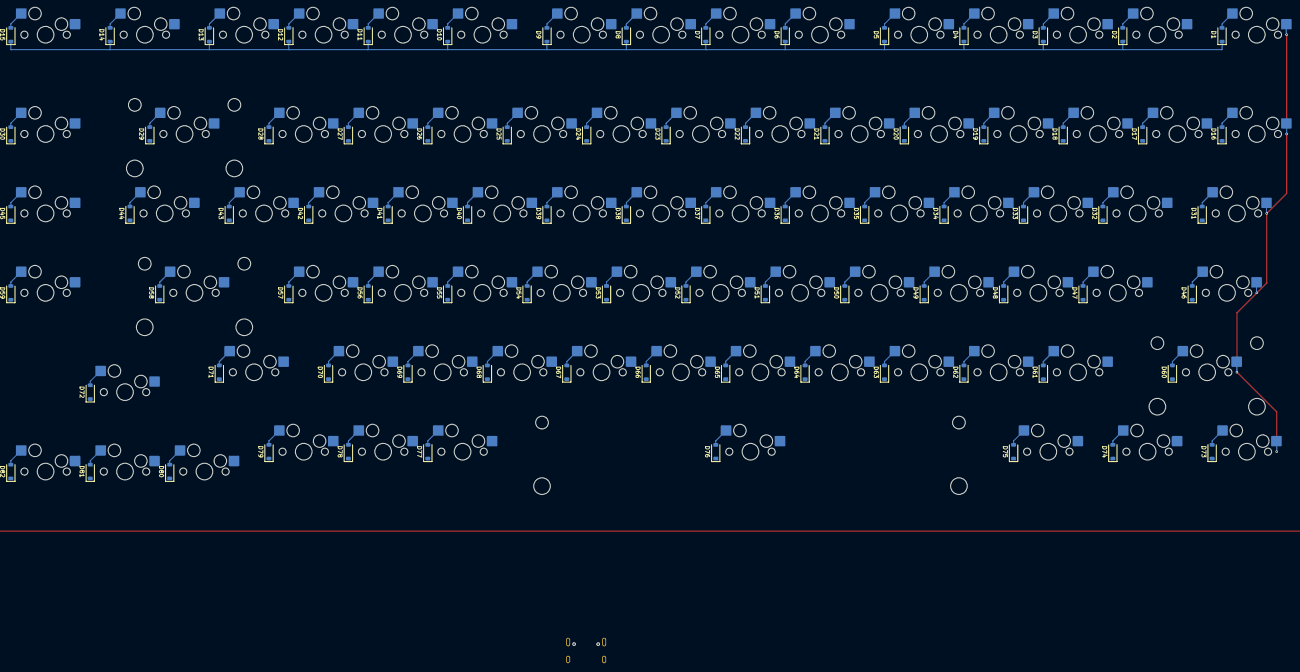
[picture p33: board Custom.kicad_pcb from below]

Board: 2 copper layers, 205 parts (164 on the bottom side), 129 nets.

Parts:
C1, C7, C8, C9, C10, C11, C12, C13, C14, C15, C17, C18: 100nF; C_0603_1608Metric
C2, C3: 15pF; C_0603_1608Metric
C4, C5, C6, C16: 1uF; C_0603_1608Metric
D1, D2, D3, D4, D5, D6, D7, D8, D9, D10, D11, D12, D13, D14, D15, D16, D17, D18, D19, D20, D21, D22, D23, D24, D25, D26, D27, D28, D29, D30, D31, D32, D33, D34, D35, D36, D37, D38, D39, D40, D41, D42, D43, D44, D45, D46, D47, D48, D49, D50, D51, D52, D53, D54, D55, D56, D57, D58, D59, D60, D61, D62, D63, D64, D65, D66, D67, D68, D69, D70, D71, D72, D73, D74, D75, D76, D77, D78, D79, D80, D81, D82: 1N4148W; D_SOD-123
F1: MF-MSMF050-2; Fuse_1812_4532Metric
J1: USB_C_Receptacle_USB2.0_16P; USB_C_Receptacle_GCT_USB4105-xx-A_16P_TopMnt_Horizontal
R1, R7: 10k; R_0603_1608Metric
R2, R8: 1k; R_0603_1608Metric
R3, R4: 5.1k; R_0603_1608Metric
R5, R6: 27; R_0603_1608Metric
SW1: RESET; SW_SPST_B3U-1000P
SW2: BOOT; SW_SPST_B3U-1000P
SW3, SW4, SW5, SW6, SW7, SW8, SW9, SW10, SW11, SW12, SW13, SW14, SW15, SW16, SW17, SW18, SW19, SW20, SW21, SW22, SW23, SW24, SW25, SW26, SW27, SW28, SW29, SW30, SW32, SW34, SW35, SW36, SW37, SW38, SW39, SW40, SW41, SW42, SW43, SW44, SW45, SW47, SW49, SW50, SW51, SW52, SW53, SW54, SW55, SW56, SW57, SW58, SW59, SW61, SW63, SW64, SW65, SW66, SW67, SW68, SW69, SW70, SW71, SW72, SW74, SW79, SW80, SW81, SW82, SW83, SW84: MX-Hotswap-1U
SW31: MX-Hotswap-2U
SW33, SW46: MX-Hotswap-1.5U
SW48, SW73: MX-Hotswap-1.75U
SW60, SW62: MX-Hotswap-2.25U
SW75, SW76, SW77: MX-Hotswap-1.25U
SW78: MX-Hotswap-6.25U
TP1, TP2, TP3, TP4, TP5, TP6: TestPoint; TestPoint_Pad_D2.0mm
U1: USBLC6-2SC6; SOT-23-6
U2: AP2112K-3.3; SOT-23-5
U3: RP2040; QFN-56-1EP_7x7mm_P0.4mm_EP3.2x3.2mm
U4: W25Q16JVSS; SOIC-8_5.3x5.3mm_P1.27mm
Y1: ABM8-272-T3; Crystal_SMD_3225-4Pin_3.2x2.5mm

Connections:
+1V1: C16.1, C17.1, C18.1, TP2.1 (1_1), U3.23 (DVDD), U3.45 (VREG_VOUT), U3.50 (DVDD)
+3V3: C5.1, C6.1, C7.1, C8.1, C9.1, C10.1, C11.1, C12.1, C13.1, C14.1, C15.1, R1.1, R7.1, TP3.1 (1_1), U2.5 (VOUT), U3.1 (IOVDD), U3.10 (IOVDD), U3.22 (IOVDD), U3.33 (IOVDD), U3.42 (IOVDD), U3.43 (ADC_AVDD), U3.44 (VREG_VIN), U3.48 (USB_VDD), U3.49 (IOVDD), U4.8 (VCC)
+5V: C4.1, F1.2, TP4.1 (1_1), U2.1 (VIN), U2.3 (EN)
/BOOTSEL: R2.2, SW2.1
/CC1: J1.A5 (CC1), R3.1
/CC2: J1.B5 (CC2), R4.1
/QSPI_SCLK: U3.52 (QSPI_SCLK), U4.6 (CLK)
/QSPI_SD0: U3.53 (QSPI_SD0), U4.5 (DI/IO_{0})
/QSPI_SD1: U3.55 (QSPI_SD1), U4.2 (DO/IO_{1})
/QSPI_SD2: U3.54 (QSPI_SD2), U4.3 (~WP/IO_{2})
/QSPI_SD3: U3.51 (QSPI_SD3), U4.7 (~HOLD/~RESET/IO_{3})
/QSPI_SS: R2.1, R7.2, U3.56 (~QSPI_SS), U4.1 (~CS)
/RP_USB_DM: R6.2, U3.46 (USB_DM)
/RP_USB_DP: R5.2, U3.47 (USB_DP)
/RP_XIN: C2.1, U3.20 (XIN), Y1.1
/RP_XOUT: R8.2, U3.21 (XOUT)
/RUN: R1.2, SW1.1, U3.26 (RUN)
/SWCLK_TEST: TP5.1 (1_1), U3.24 (SWCLK)
/SWDIO_TEST: TP6.1 (1_1), U3.25 (SWDIO)
/USB_DM_CONN: J1.A7 (D-), J1.B7 (D-), U1.3 (I/O2)
/USB_DM_PROT: R6.1, U1.4 (I/O2)
/USB_DP_CONN: J1.A6 (D+), J1.B6 (D+), U1.1 (I/O1)
/USB_DP_PROT: R5.1, U1.6 (I/O1)
/VBUS_RAW: C1.1, F1.1, J1.A4 (VBUS), J1.A9 (VBUS), J1.B4 (VBUS), J1.B9 (VBUS), U1.5 (VBUS)
/XTAL_OUT: C3.1, R8.1, Y1.3
COL0: SW3.1, SW18.1, SW33.1, SW48.1, SW62.1, SW75.1, U3.8 (GPIO6)
COL1: SW4.1, SW19.1, SW34.1, SW49.1, SW76.1, U3.9 (GPIO7)
COL2: SW5.1, SW20.1, SW35.1, SW50.1, SW63.1, SW77.1, U3.11 (GPIO8)
COL3: SW6.1, SW21.1, SW36.1, SW51.1, SW64.1, U3.12 (GPIO9)
COL4: SW7.1, SW22.1, SW37.1, SW52.1, SW65.1, U3.13 (GPIO10)
COL5: SW8.1, SW23.1, SW38.1, SW53.1, SW66.1, SW78.1, U3.14 (GPIO11)
COL6: SW9.1, SW24.1, SW39.1, SW54.1, SW67.1, U3.15 (GPIO12)
COL7: SW10.1, SW25.1, SW40.1, SW55.1, SW68.1, U3.16 (GPIO13)
COL8: SW11.1, SW26.1, SW41.1, SW56.1, SW69.1, U3.17 (GPIO14)
COL9: SW12.1, SW27.1, SW42.1, SW57.1, SW70.1, SW79.1, U3.18 (GPIO15)
COL10: SW13.1, SW28.1, SW43.1, SW58.1, SW71.1, SW80.1, U3.27 (GPIO16)
COL11: SW14.1, SW29.1, SW44.1, SW59.1, SW72.1, SW81.1, U3.28 (GPIO17)
COL12: SW15.1, SW30.1, SW45.1, SW60.1, SW73.1, SW82.1, U3.29 (GPIO18)
COL13: SW16.1, SW31.1, SW46.1, SW74.1, SW83.1, U3.30 (GPIO19)
COL14: SW17.1, SW32.1, SW47.1, SW61.1, SW84.1, U3.31 (GPIO20)
GND: C1.2, C2.2, C3.2, C4.2, C5.2, C6.2, C7.2, C8.2, C9.2, C10.2, C11.2, C12.2, C13.2, C14.2, C15.2, C16.2, C17.2, C18.2, J1.A1 (GND), J1.A12 (GND), J1.B1 (GND), J1.B12 (GND), J1.SH (SHIELD), R3.2, R4.2, SW1.2, SW2.2, TP1.1 (1_1), U1.2 (GND), U2.2 (GND), U3.19 (TESTEN), U3.57 (GND), U4.4 (GND), Y1.2 (G), Y1.4 (G)
unnamed: D1.2 (A), SW3.2
unnamed: D2.2 (A), SW4.2
unnamed: D3.2 (A), SW5.2
unnamed: D4.2 (A), SW6.2
unnamed: D5.2 (A), SW7.2
unnamed: D6.2 (A), SW8.2
unnamed: D7.2 (A), SW9.2
unnamed: D8.2 (A), SW10.2
unnamed: D9.2 (A), SW11.2
unnamed: D10.2 (A), SW12.2
unnamed: D11.2 (A), SW13.2
unnamed: D12.2 (A), SW14.2
unnamed: D13.2 (A), SW15.2
unnamed: D14.2 (A), SW16.2
unnamed: D15.2 (A), SW17.2
unnamed: D16.2 (A), SW18.2
unnamed: D17.2 (A), SW19.2
unnamed: D18.2 (A), SW20.2
unnamed: D19.2 (A), SW21.2
unnamed: D20.2 (A), SW22.2
unnamed: D21.2 (A), SW23.2
unnamed: D22.2 (A), SW24.2
unnamed: D23.2 (A), SW25.2
unnamed: D24.2 (A), SW26.2
unnamed: D25.2 (A), SW27.2
unnamed: D26.2 (A), SW28.2
unnamed: D27.2 (A), SW29.2
unnamed: D28.2 (A), SW30.2
unnamed: D29.2 (A), SW31.2
unnamed: D30.2 (A), SW32.2
unnamed: D31.2 (A), SW33.2
unnamed: D32.2 (A), SW34.2
unnamed: D33.2 (A), SW35.2
unnamed: D34.2 (A), SW36.2
unnamed: D35.2 (A), SW37.2
unnamed: D36.2 (A), SW38.2
unnamed: D37.2 (A), SW39.2
unnamed: D38.2 (A), SW40.2
unnamed: D39.2 (A), SW41.2
unnamed: D40.2 (A), SW42.2
unnamed: D41.2 (A), SW43.2
unnamed: D42.2 (A), SW44.2
unnamed: D43.2 (A), SW45.2
unnamed: D44.2 (A), SW46.2
unnamed: D45.2 (A), SW47.2
unnamed: D46.2 (A), SW48.2
unnamed: D47.2 (A), SW49.2
unnamed: D48.2 (A), SW50.2
unnamed: D49.2 (A), SW51.2
unnamed: D50.2 (A), SW52.2
unnamed: D51.2 (A), SW53.2
unnamed: D52.2 (A), SW54.2
unnamed: D53.2 (A), SW55.2
unnamed: D54.2 (A), SW56.2
unnamed: D55.2 (A), SW57.2
unnamed: D56.2 (A), SW58.2
unnamed: D57.2 (A), SW59.2
unnamed: D58.2 (A), SW60.2
unnamed: D59.2 (A), SW61.2
unnamed: D60.2 (A), SW62.2
unnamed: D61.2 (A), SW63.2
unnamed: D62.2 (A), SW64.2
unnamed: D63.2 (A), SW65.2
unnamed: D64.2 (A), SW66.2
unnamed: D65.2 (A), SW67.2
unnamed: D66.2 (A), SW68.2
unnamed: D67.2 (A), SW69.2
unnamed: D68.2 (A), SW70.2
unnamed: D69.2 (A), SW71.2
unnamed: D70.2 (A), SW72.2
unnamed: D71.2 (A), SW73.2
unnamed: D72.2 (A), SW74.2
unnamed: D73.2 (A), SW75.2
unnamed: D74.2 (A), SW76.2
unnamed: D75.2 (A), SW77.2
unnamed: D76.2 (A), SW78.2
unnamed: D77.2 (A), SW79.2
unnamed: D78.2 (A), SW80.2
unnamed: D79.2 (A), SW81.2
unnamed: D80.2 (A), SW82.2
unnamed: D81.2 (A), SW83.2
unnamed: D82.2 (A), SW84.2
ROW0: D1.1 (K), D2.1 (K), D3.1 (K), D4.1 (K), D5.1 (K), D6.1 (K), D7.1 (K), D8.1 (K), D9.1 (K), D10.1 (K), D11.1 (K), D12.1 (K), D13.1 (K), D14.1 (K), D15.1 (K), U3.2 (GPIO0)
ROW1: D16.1 (K), D17.1 (K), D18.1 (K), D19.1 (K), D20.1 (K), D21.1 (K), D22.1 (K), D23.1 (K), D24.1 (K), D25.1 (K), D26.1 (K), D27.1 (K), D28.1 (K), D29.1 (K), D30.1 (K), U3.3 (GPIO1)
ROW2: D31.1 (K), D32.1 (K), D33.1 (K), D34.1 (K), D35.1 (K), D36.1 (K), D37.1 (K), D38.1 (K), D39.1 (K), D40.1 (K), D41.1 (K), D42.1 (K), D43.1 (K), D44.1 (K), D45.1 (K), U3.4 (GPIO2)
ROW3: D46.1 (K), D47.1 (K), D48.1 (K), D49.1 (K), D50.1 (K), D51.1 (K), D52.1 (K), D53.1 (K), D54.1 (K), D55.1 (K), D56.1 (K), D57.1 (K), D58.1 (K), D59.1 (K), U3.5 (GPIO3)
ROW4: D60.1 (K), D61.1 (K), D62.1 (K), D63.1 (K), D64.1 (K), D65.1 (K), D66.1 (K), D67.1 (K), D68.1 (K), D69.1 (K), D70.1 (K), D71.1 (K), D72.1 (K), U3.6 (GPIO4)
ROW5: D73.1 (K), D74.1 (K), D75.1 (K), D76.1 (K), D77.1 (K), D78.1 (K), D79.1 (K), D80.1 (K), D81.1 (K), D82.1 (K), U3.7 (GPIO5)

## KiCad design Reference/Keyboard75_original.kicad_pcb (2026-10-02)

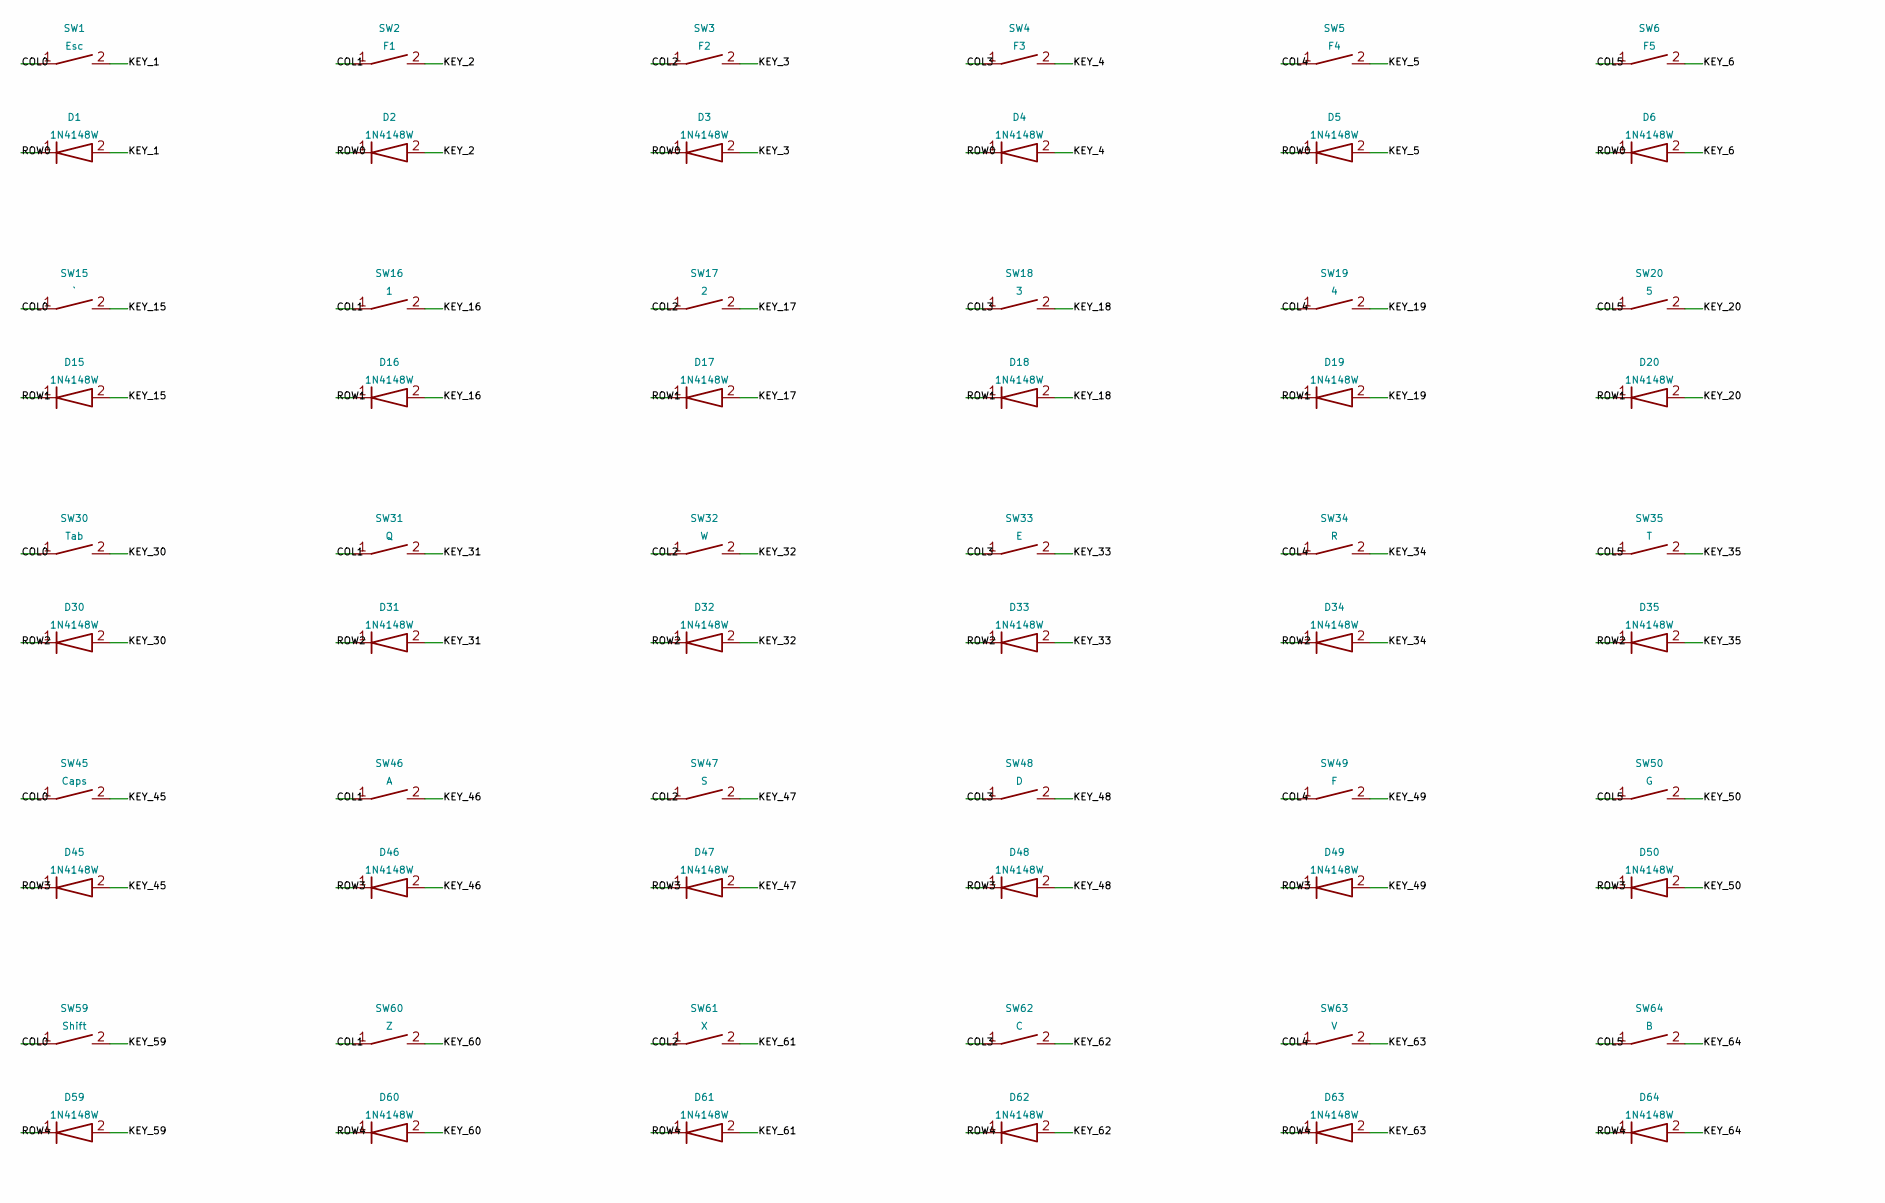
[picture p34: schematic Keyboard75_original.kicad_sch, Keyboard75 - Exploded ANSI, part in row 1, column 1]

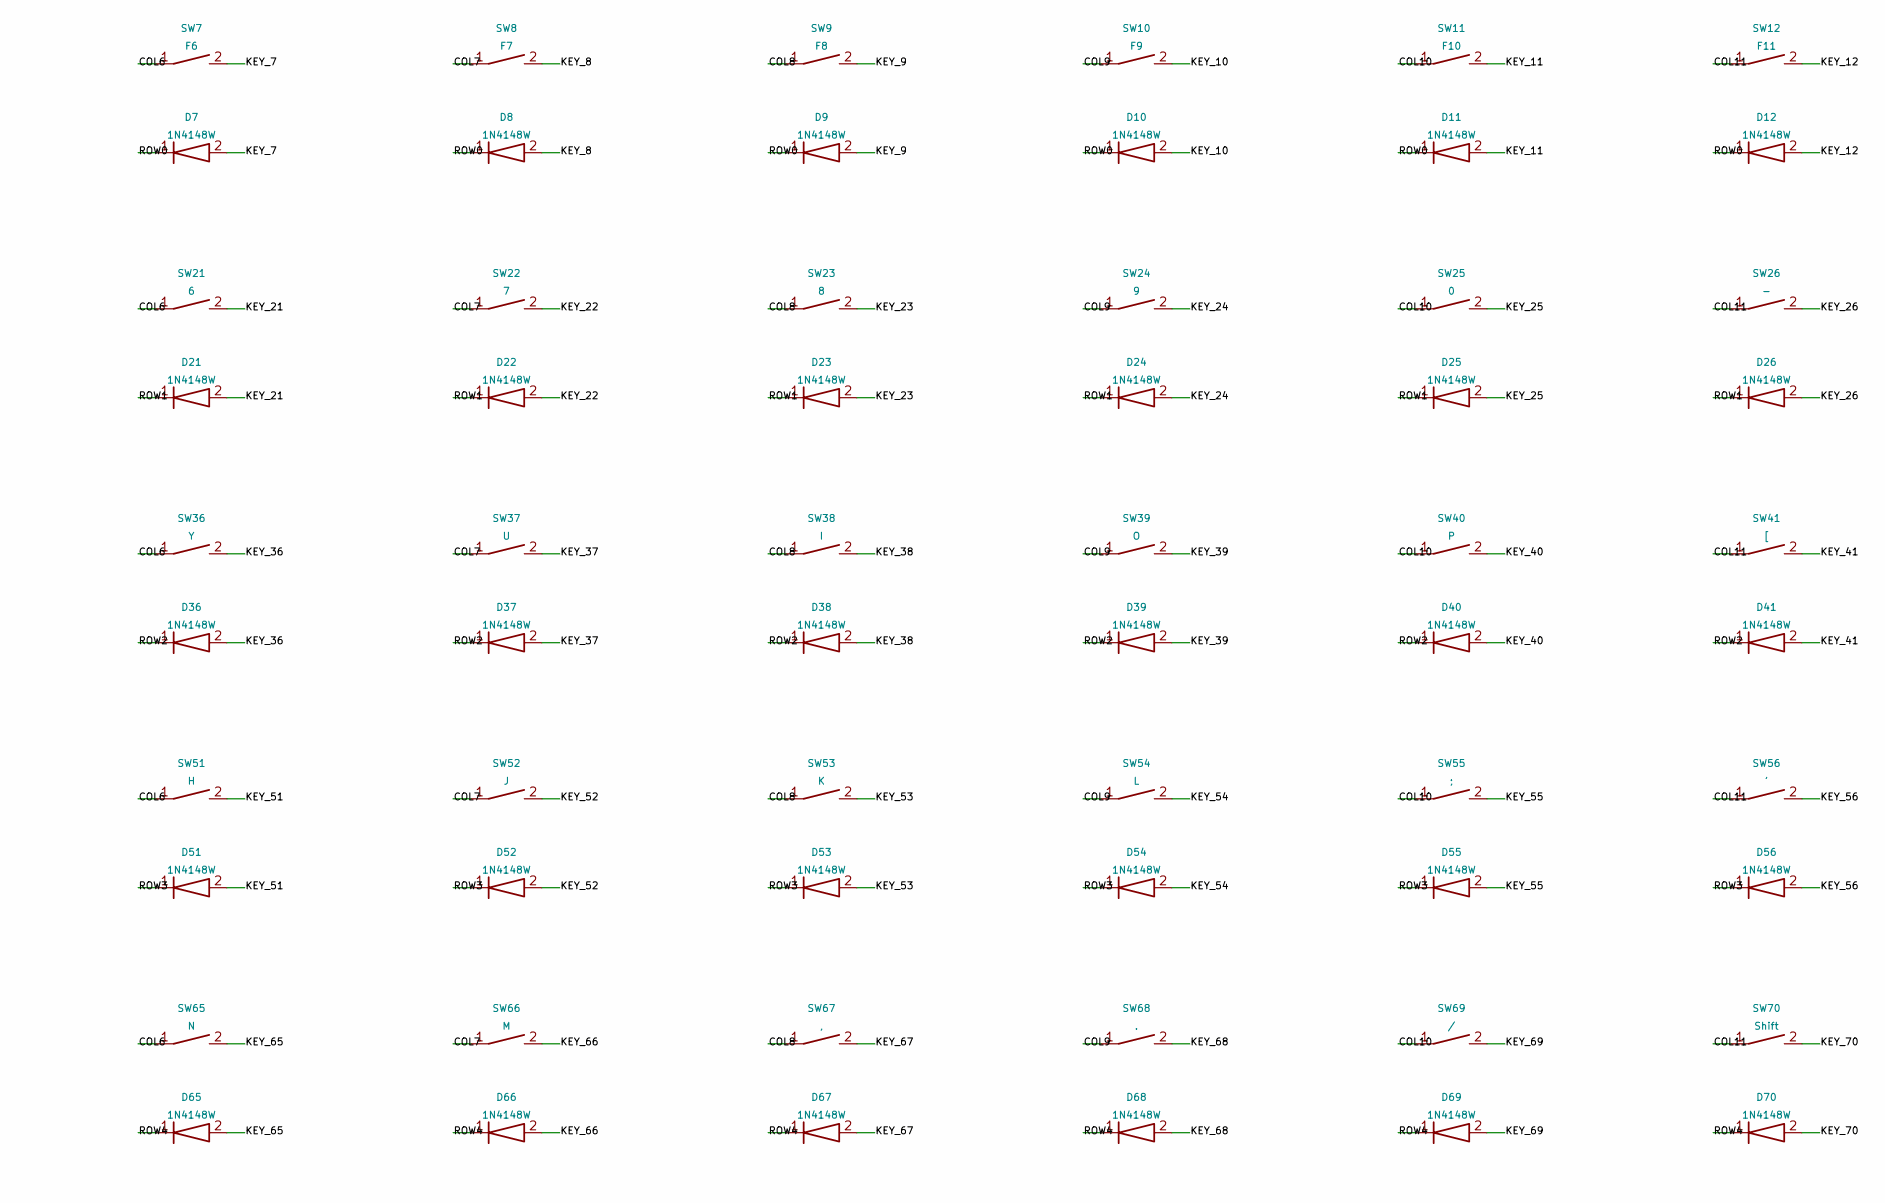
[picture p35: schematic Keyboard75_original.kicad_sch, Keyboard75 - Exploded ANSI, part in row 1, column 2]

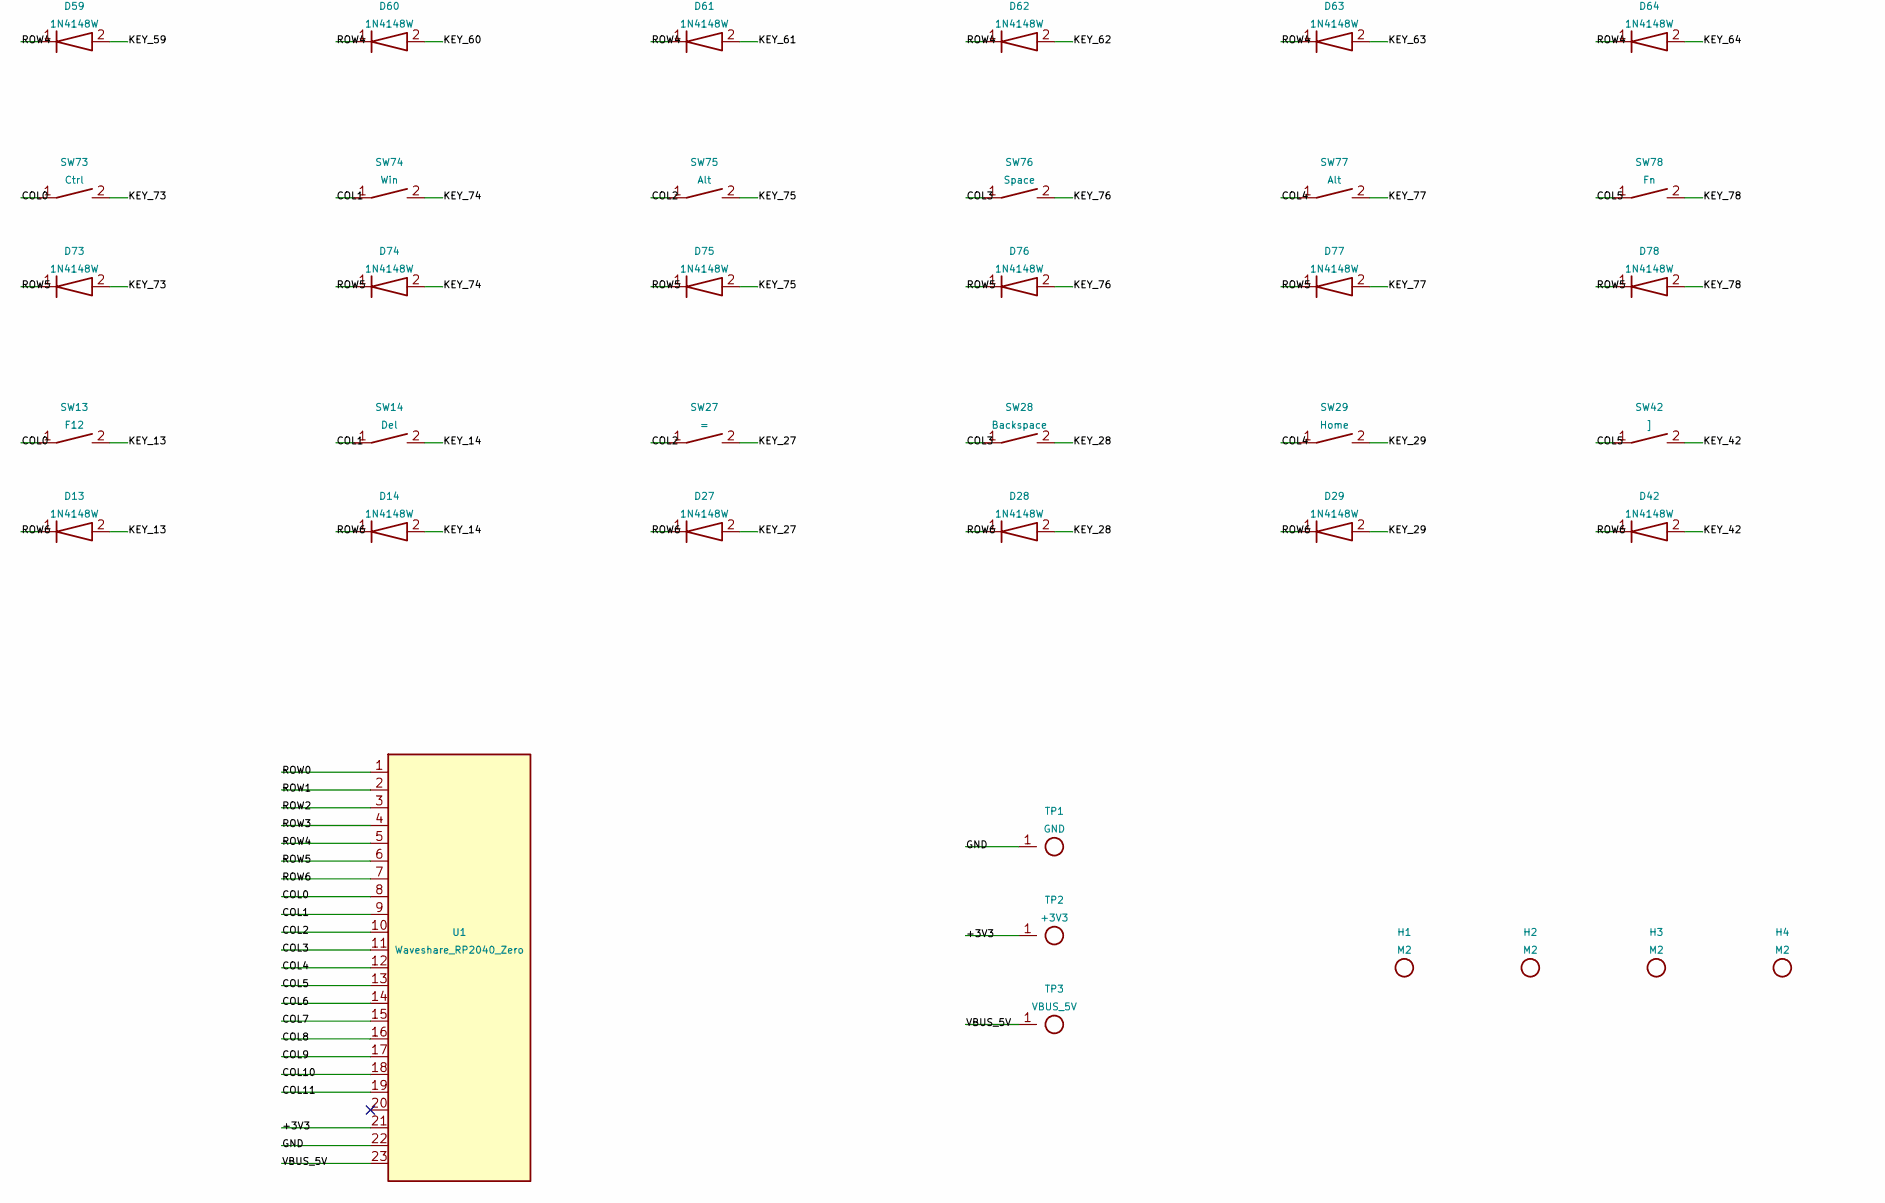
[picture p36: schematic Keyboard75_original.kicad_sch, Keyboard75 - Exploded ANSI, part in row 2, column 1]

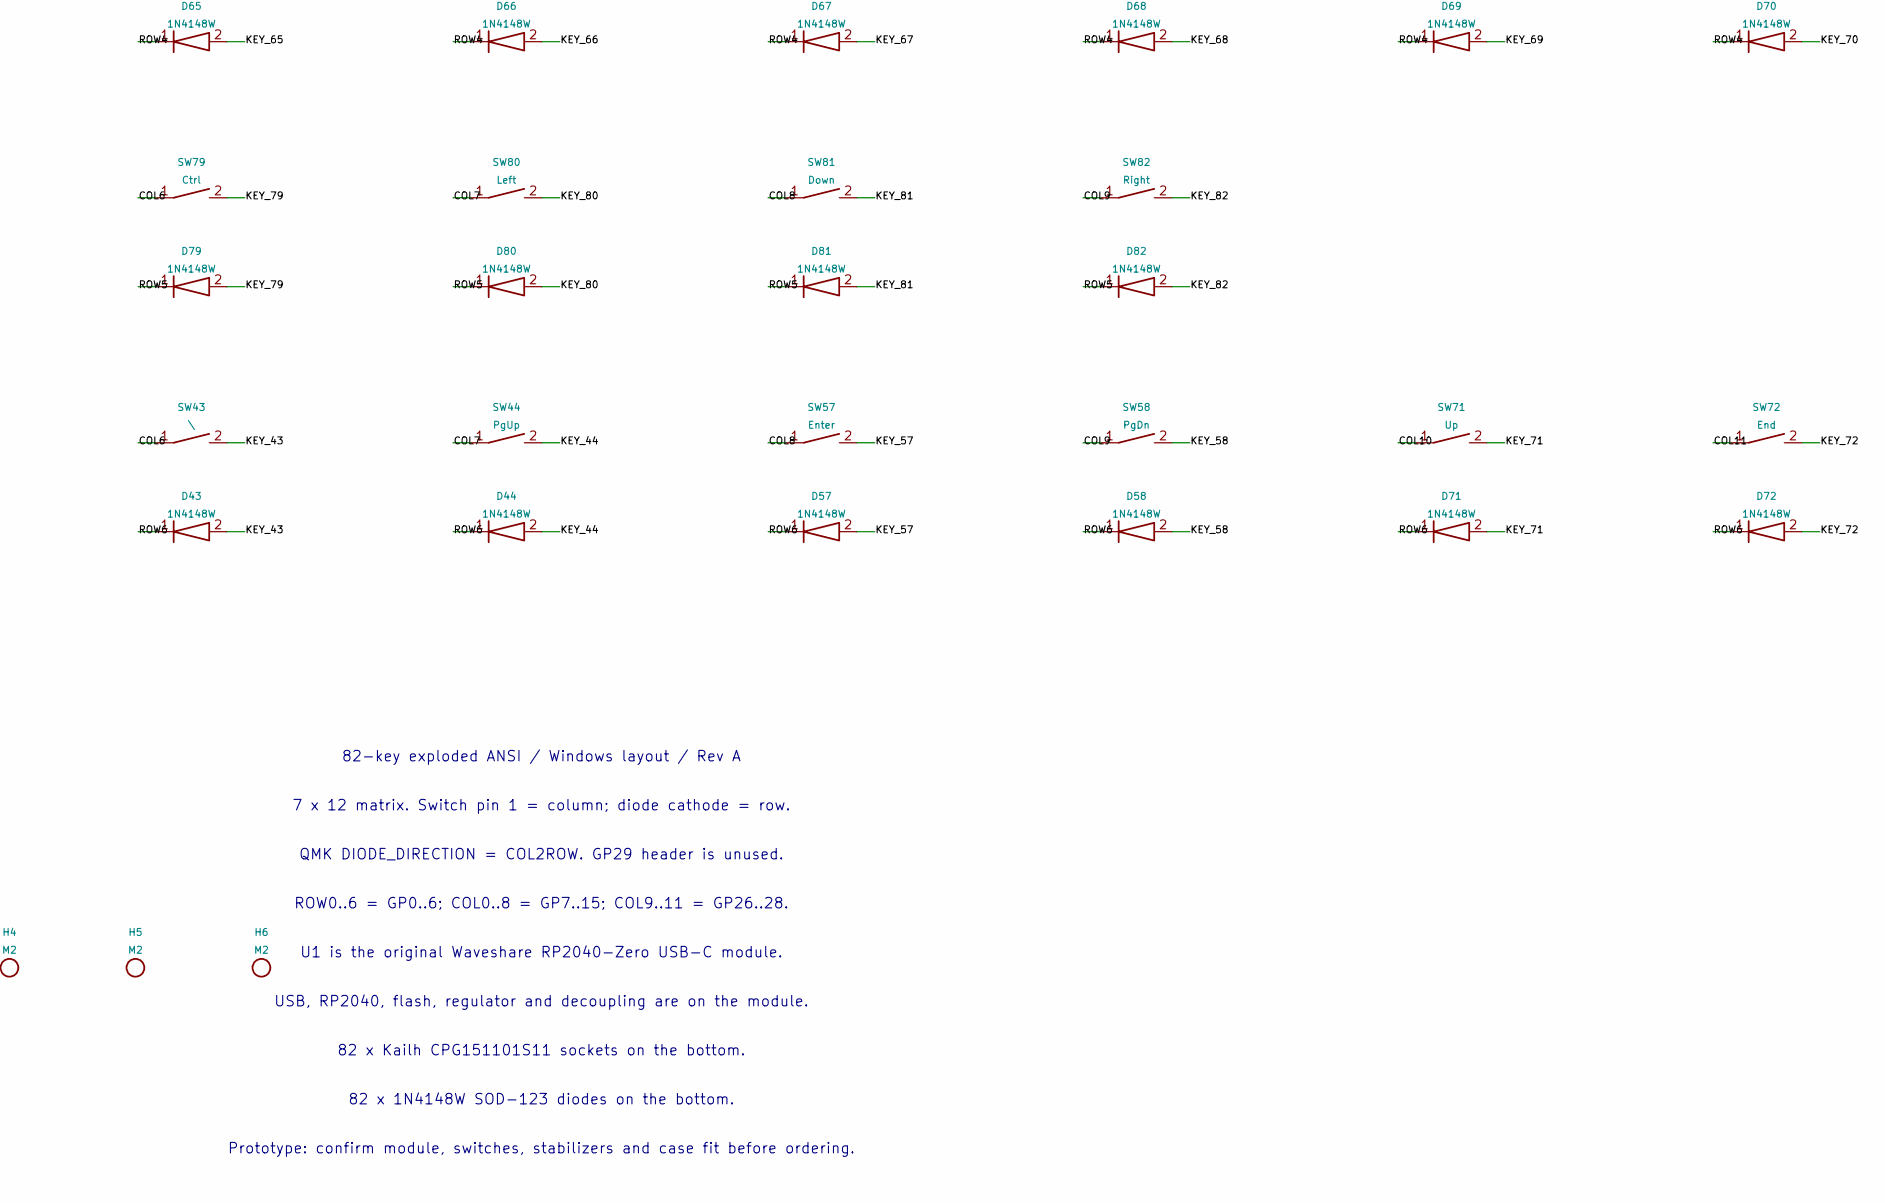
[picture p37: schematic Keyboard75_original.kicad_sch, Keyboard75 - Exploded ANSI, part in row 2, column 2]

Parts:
D1, D2, D3, D4, D5, D6, D7, D8, D9, D10, D11, D12, D13, D14, D15, D16, D17, D18, D19, D20, D21, D22, D23, D24, D25, D26, D27, D28, D29, D30, D31, D32, D33, D34, D35, D36, D37, D38, D39, D40, D41, D42, D43, D44, D45, D46, D47, D48, D49, D50, D51, D52, D53, D54, D55, D56, D57, D58, D59, D60, D61, D62, D63, D64, D65, D66, D67, D68, D69, D70, D71, D72, D73, D74, D75, D76, D77, D78, D79, D80, D81, D82: 1N4148W; D_SOD123
H1, H2, H3, H4, H5, H6: M2; MountingHole_M2
SW1: Esc; MX_Hotswap_1u
SW2: F1; MX_Hotswap_1u
SW3: F2; MX_Hotswap_1u
SW4: F3; MX_Hotswap_1u
SW5: F4; MX_Hotswap_1u
SW6: F5; MX_Hotswap_1u
SW7: F6; MX_Hotswap_1u
SW8: F7; MX_Hotswap_1u
SW9: F8; MX_Hotswap_1u
SW10: F9; MX_Hotswap_1u
SW11: F10; MX_Hotswap_1u
SW12: F11; MX_Hotswap_1u
SW13: F12; MX_Hotswap_1u
SW14: Del; MX_Hotswap_1u
SW15: `; MX_Hotswap_1u
SW16: 1; MX_Hotswap_1u
SW17: 2; MX_Hotswap_1u
SW18: 3; MX_Hotswap_1u
SW19: 4; MX_Hotswap_1u
SW20: 5; MX_Hotswap_1u
SW21: 6; MX_Hotswap_1u
SW22: 7; MX_Hotswap_1u
SW23: 8; MX_Hotswap_1u
SW24: 9; MX_Hotswap_1u
SW25: 0; MX_Hotswap_1u
SW26: -; MX_Hotswap_1u
SW27: =; MX_Hotswap_1u
SW28: Backspace; MX_Hotswap_2u
SW29: Home; MX_Hotswap_1u
SW30: Tab; MX_Hotswap_1p5u
SW31: Q; MX_Hotswap_1u
SW32: W; MX_Hotswap_1u
SW33: E; MX_Hotswap_1u
SW34: R; MX_Hotswap_1u
SW35: T; MX_Hotswap_1u
SW36: Y; MX_Hotswap_1u
SW37: U; MX_Hotswap_1u
SW38: I; MX_Hotswap_1u
SW39: O; MX_Hotswap_1u
SW40: P; MX_Hotswap_1u
SW41: [; MX_Hotswap_1u
SW42: ]; MX_Hotswap_1u
SW43: \; MX_Hotswap_1p5u
SW44: PgUp; MX_Hotswap_1u
SW45: Caps; MX_Hotswap_1p75u
SW46: A; MX_Hotswap_1u
SW47: S; MX_Hotswap_1u
SW48: D; MX_Hotswap_1u
SW49: F; MX_Hotswap_1u
SW50: G; MX_Hotswap_1u
SW51: H; MX_Hotswap_1u
SW52: J; MX_Hotswap_1u
SW53: K; MX_Hotswap_1u
SW54: L; MX_Hotswap_1u
SW55: ;; MX_Hotswap_1u
SW56: '; MX_Hotswap_1u
SW57: Enter; MX_Hotswap_2p25u
SW58: PgDn; MX_Hotswap_1u
SW59: Shift; MX_Hotswap_2p25u
SW60: Z; MX_Hotswap_1u
SW61: X; MX_Hotswap_1u
SW62: C; MX_Hotswap_1u
SW63: V; MX_Hotswap_1u
SW64: B; MX_Hotswap_1u
SW65: N; MX_Hotswap_1u
SW66: M; MX_Hotswap_1u
SW67: ,; MX_Hotswap_1u
SW68: .; MX_Hotswap_1u
SW69: /; MX_Hotswap_1u
SW70: Shift; MX_Hotswap_1p75u
SW71: Up; MX_Hotswap_1u
SW72: End; MX_Hotswap_1u
SW73: Ctrl; MX_Hotswap_1p25u
SW74: Win; MX_Hotswap_1p25u
SW75: Alt; MX_Hotswap_1p25u
SW76: Space; MX_Hotswap_6p25u
SW77: Alt; MX_Hotswap_1u
SW78: Fn; MX_Hotswap_1u
SW79: Ctrl; MX_Hotswap_1u
SW80: Left; MX_Hotswap_1u
SW81: Down; MX_Hotswap_1u
SW82: Right; MX_Hotswap_1u
TP1: GND; TestPoint
TP2: +3V3; TestPoint
TP3: VBUS_5V; TestPoint
U1: Waveshare_RP2040_Zero; RP2040_Zero

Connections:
/+3V3: TP2.1, U1.21 (3V3)
/COL0: SW1.1 (COL), SW13.1 (COL), SW15.1 (COL), SW30.1 (COL), SW45.1 (COL), SW59.1 (COL), SW73.1 (COL), U1.8 (GP7)
/COL1: SW2.1 (COL), SW14.1 (COL), SW16.1 (COL), SW31.1 (COL), SW46.1 (COL), SW60.1 (COL), SW74.1 (COL), U1.9 (GP8)
/COL2: SW3.1 (COL), SW17.1 (COL), SW27.1 (COL), SW32.1 (COL), SW47.1 (COL), SW61.1 (COL), SW75.1 (COL), U1.10 (GP9)
/COL3: SW4.1 (COL), SW18.1 (COL), SW28.1 (COL), SW33.1 (COL), SW48.1 (COL), SW62.1 (COL), SW76.1 (COL), U1.11 (GP10)
/COL4: SW5.1 (COL), SW19.1 (COL), SW29.1 (COL), SW34.1 (COL), SW49.1 (COL), SW63.1 (COL), SW77.1 (COL), U1.12 (GP11)
/COL5: SW6.1 (COL), SW20.1 (COL), SW35.1 (COL), SW42.1 (COL), SW50.1 (COL), SW64.1 (COL), SW78.1 (COL), U1.13 (GP12)
/COL6: SW7.1 (COL), SW21.1 (COL), SW36.1 (COL), SW43.1 (COL), SW51.1 (COL), SW65.1 (COL), SW79.1 (COL), U1.14 (GP13)
/COL7: SW8.1 (COL), SW22.1 (COL), SW37.1 (COL), SW44.1 (COL), SW52.1 (COL), SW66.1 (COL), SW80.1 (COL), U1.15 (GP14)
/COL8: SW9.1 (COL), SW23.1 (COL), SW38.1 (COL), SW53.1 (COL), SW57.1 (COL), SW67.1 (COL), SW81.1 (COL), U1.16 (GP15)
/COL9: SW10.1 (COL), SW24.1 (COL), SW39.1 (COL), SW54.1 (COL), SW58.1 (COL), SW68.1 (COL), SW82.1 (COL), U1.17 (GP26)
/COL10: SW11.1 (COL), SW25.1 (COL), SW40.1 (COL), SW55.1 (COL), SW69.1 (COL), SW71.1 (COL), U1.18 (GP27)
/COL11: SW12.1 (COL), SW26.1 (COL), SW41.1 (COL), SW56.1 (COL), SW70.1 (COL), SW72.1 (COL), U1.19 (GP28)
/GND: TP1.1, U1.22 (GND)
/KEY_1: D1.2 (A), SW1.2 (A)
/KEY_2: D2.2 (A), SW2.2 (A)
/KEY_3: D3.2 (A), SW3.2 (A)
/KEY_4: D4.2 (A), SW4.2 (A)
/KEY_5: D5.2 (A), SW5.2 (A)
/KEY_6: D6.2 (A), SW6.2 (A)
/KEY_7: D7.2 (A), SW7.2 (A)
/KEY_8: D8.2 (A), SW8.2 (A)
/KEY_9: D9.2 (A), SW9.2 (A)
/KEY_10: D10.2 (A), SW10.2 (A)
/KEY_11: D11.2 (A), SW11.2 (A)
/KEY_12: D12.2 (A), SW12.2 (A)
/KEY_13: D13.2 (A), SW13.2 (A)
/KEY_14: D14.2 (A), SW14.2 (A)
/KEY_15: D15.2 (A), SW15.2 (A)
/KEY_16: D16.2 (A), SW16.2 (A)
/KEY_17: D17.2 (A), SW17.2 (A)
/KEY_18: D18.2 (A), SW18.2 (A)
/KEY_19: D19.2 (A), SW19.2 (A)
/KEY_20: D20.2 (A), SW20.2 (A)
/KEY_21: D21.2 (A), SW21.2 (A)
/KEY_22: D22.2 (A), SW22.2 (A)
/KEY_23: D23.2 (A), SW23.2 (A)
/KEY_24: D24.2 (A), SW24.2 (A)
/KEY_25: D25.2 (A), SW25.2 (A)
/KEY_26: D26.2 (A), SW26.2 (A)
/KEY_27: D27.2 (A), SW27.2 (A)
/KEY_28: D28.2 (A), SW28.2 (A)
/KEY_29: D29.2 (A), SW29.2 (A)
/KEY_30: D30.2 (A), SW30.2 (A)
/KEY_31: D31.2 (A), SW31.2 (A)
/KEY_32: D32.2 (A), SW32.2 (A)
/KEY_33: D33.2 (A), SW33.2 (A)
/KEY_34: D34.2 (A), SW34.2 (A)
/KEY_35: D35.2 (A), SW35.2 (A)
/KEY_36: D36.2 (A), SW36.2 (A)
/KEY_37: D37.2 (A), SW37.2 (A)
/KEY_38: D38.2 (A), SW38.2 (A)
/KEY_39: D39.2 (A), SW39.2 (A)
/KEY_40: D40.2 (A), SW40.2 (A)
/KEY_41: D41.2 (A), SW41.2 (A)
/KEY_42: D42.2 (A), SW42.2 (A)
/KEY_43: D43.2 (A), SW43.2 (A)
/KEY_44: D44.2 (A), SW44.2 (A)
/KEY_45: D45.2 (A), SW45.2 (A)
/KEY_46: D46.2 (A), SW46.2 (A)
/KEY_47: D47.2 (A), SW47.2 (A)
/KEY_48: D48.2 (A), SW48.2 (A)
/KEY_49: D49.2 (A), SW49.2 (A)
/KEY_50: D50.2 (A), SW50.2 (A)
/KEY_51: D51.2 (A), SW51.2 (A)
/KEY_52: D52.2 (A), SW52.2 (A)
/KEY_53: D53.2 (A), SW53.2 (A)
/KEY_54: D54.2 (A), SW54.2 (A)
/KEY_55: D55.2 (A), SW55.2 (A)
/KEY_56: D56.2 (A), SW56.2 (A)
/KEY_57: D57.2 (A), SW57.2 (A)
/KEY_58: D58.2 (A), SW58.2 (A)
/KEY_59: D59.2 (A), SW59.2 (A)
/KEY_60: D60.2 (A), SW60.2 (A)
/KEY_61: D61.2 (A), SW61.2 (A)
/KEY_62: D62.2 (A), SW62.2 (A)
/KEY_63: D63.2 (A), SW63.2 (A)
/KEY_64: D64.2 (A), SW64.2 (A)
/KEY_65: D65.2 (A), SW65.2 (A)
/KEY_66: D66.2 (A), SW66.2 (A)
/KEY_67: D67.2 (A), SW67.2 (A)
/KEY_68: D68.2 (A), SW68.2 (A)
/KEY_69: D69.2 (A), SW69.2 (A)
/KEY_70: D70.2 (A), SW70.2 (A)
/KEY_71: D71.2 (A), SW71.2 (A)
/KEY_72: D72.2 (A), SW72.2 (A)
/KEY_73: D73.2 (A), SW73.2 (A)
/KEY_74: D74.2 (A), SW74.2 (A)
/KEY_75: D75.2 (A), SW75.2 (A)
/KEY_76: D76.2 (A), SW76.2 (A)
/KEY_77: D77.2 (A), SW77.2 (A)
/KEY_78: D78.2 (A), SW78.2 (A)
/KEY_79: D79.2 (A), SW79.2 (A)
/KEY_80: D80.2 (A), SW80.2 (A)
/KEY_81: D81.2 (A), SW81.2 (A)
/KEY_82: D82.2 (A), SW82.2 (A)
/ROW0: D1.1 (K), D2.1 (K), D3.1 (K), D4.1 (K), D5.1 (K), D6.1 (K), D7.1 (K), D8.1 (K), D9.1 (K), D10.1 (K), D11.1 (K), D12.1 (K), U1.1 (GP0)
/ROW1: D15.1 (K), D16.1 (K), D17.1 (K), D18.1 (K), D19.1 (K), D20.1 (K), D21.1 (K), D22.1 (K), D23.1 (K), D24.1 (K), D25.1 (K), D26.1 (K), U1.2 (GP1)
/ROW2: D30.1 (K), D31.1 (K), D32.1 (K), D33.1 (K), D34.1 (K), D35.1 (K), D36.1 (K), D37.1 (K), D38.1 (K), D39.1 (K), D40.1 (K), D41.1 (K), U1.3 (GP2)
/ROW3: D45.1 (K), D46.1 (K), D47.1 (K), D48.1 (K), D49.1 (K), D50.1 (K), D51.1 (K), D52.1 (K), D53.1 (K), D54.1 (K), D55.1 (K), D56.1 (K), U1.4 (GP3)
/ROW4: D59.1 (K), D60.1 (K), D61.1 (K), D62.1 (K), D63.1 (K), D64.1 (K), D65.1 (K), D66.1 (K), D67.1 (K), D68.1 (K), D69.1 (K), D70.1 (K), U1.5 (GP4)
/ROW5: D73.1 (K), D74.1 (K), D75.1 (K), D76.1 (K), D77.1 (K), D78.1 (K), D79.1 (K), D80.1 (K), D81.1 (K), D82.1 (K), U1.6 (GP5)
/ROW6: D13.1 (K), D14.1 (K), D27.1 (K), D28.1 (K), D29.1 (K), D42.1 (K), D43.1 (K), D44.1 (K), D57.1 (K), D58.1 (K), D71.1 (K), D72.1 (K), U1.7 (GP6)
/VBUS_5V: TP3.1, U1.23 (5V)

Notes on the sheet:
82-key exploded ANSI / Windows layout / Rev A
7 x 12 matrix. Switch pin 1 = column; diode cathode = row.
QMK DIODE_DIRECTION = COL2ROW. GP29 header is unused.
ROW0..6 = GP0..6; COL0..8 = GP7..15; COL9..11 = GP26..28.
U1 is the original Waveshare RP2040-Zero USB-C module.
USB, RP2040, flash, regulator and decoupling are on the module.
82 x Kailh CPG151101S11 sockets on the bottom.
82 x 1N4148W SOD-123 diodes on the bottom.
Prototype: confirm module, switches, stabilizers and case fit before ordering.

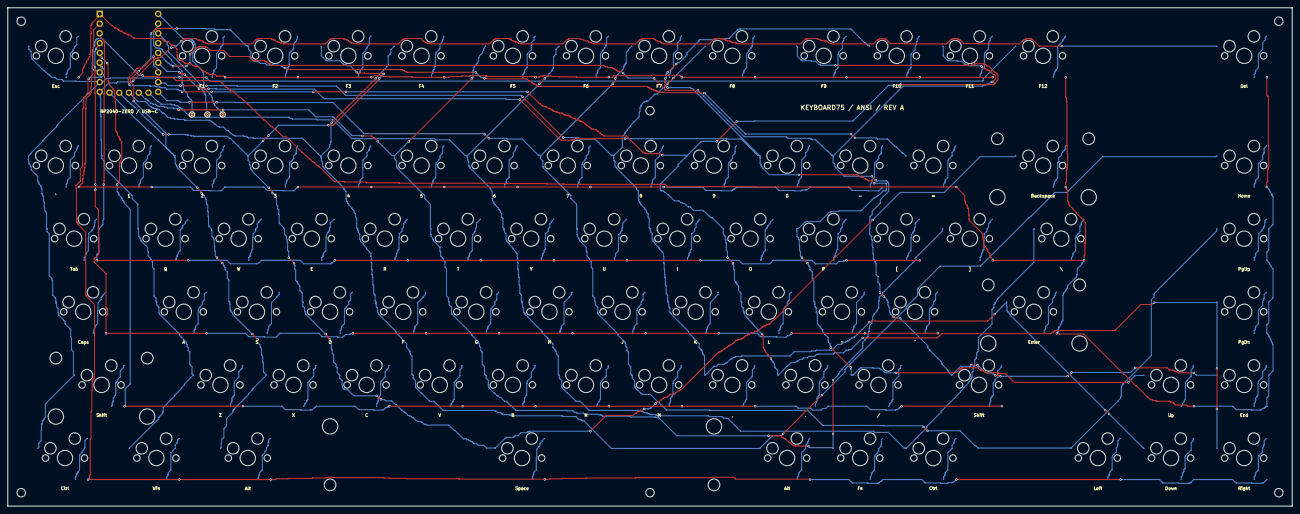
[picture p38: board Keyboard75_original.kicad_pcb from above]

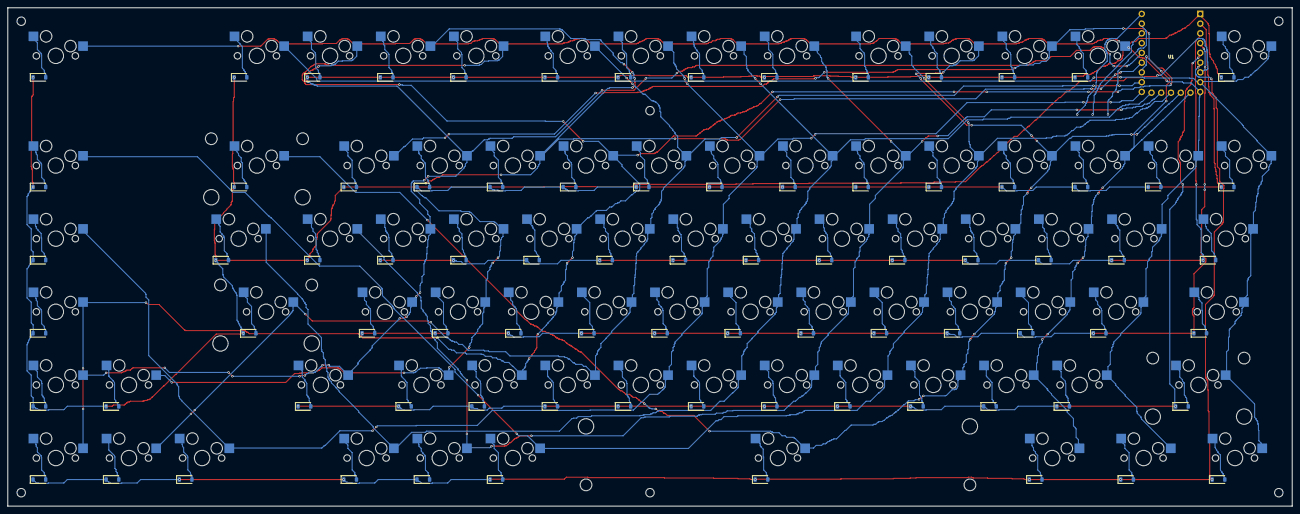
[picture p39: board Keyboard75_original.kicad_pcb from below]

Board: 2 copper layers, 334.6 x 129.8 mm, 174 parts (165 on the bottom side), 104 nets.

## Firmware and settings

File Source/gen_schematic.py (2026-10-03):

"""Generate the Vamora75 schematic and project symbol library (KiCad 10).

    python Source/gen_schematic.py [output_dir]

Circuit: RP2040 minimal design (Raspberry Pi "Hardware design with RP2040"),
USB-C (HRO TYPE-C-31-M-12) with CC pull-downs, USBLC6-2SC6 ESD, 500 mA PTC,
XC6206 3.3 V LDO, W25Q128JV QSPI flash, ABM8-272-T3 12 MHz crystal (15 pF, 1 k
series on XOUT), BOOT/RESET buttons, SWD test pads, and an 82-key 6x16 COL2ROW
matrix of Kailh CPG151101S11 hot-swap sockets with 1N4148W diodes.
"""
from __future__ import annotations

import json
import sys
import uuid
from pathlib import Path

HERE = Path(__file__).resolve().parent
sys.path.insert(0, str(HERE))
import sexp  # noqa: E402
from sexp import Sym as S  # noqa: E402
import vamora_layout as L  # noqa: E402

ROOT = HERE.parent
OUT = Path(sys.argv[1]) if len(sys.argv) > 1 else ROOT / "PCB"
STOCK = Path(r"C:\Program Files\KiCad\10.0\share\kicad\symbols")
LIBNAME = "Vamora75"
NS = uuid.UUID("0f6b4a2c-3a1e-4f39-9a6e-7a3c5d75a075")
SCH_UUID = str(uuid.uuid5(NS, "schematic-root"))
VERSION = 20251024


def uid(*p):
    return str(uuid.uuid5(NS, "/".join(map(str, p))))


# ------------------------------------------------------------------ symbol library
NEEDED = {
    "Device": ["R", "C", "D", "Polyfuse", "Crystal_GND24"],
    "Switch": ["SW_Push"],
    "Connector": ["USB_C_Receptacle_USB2.0_16P", "TestPoint"],
    "MCU_RaspberryPi": ["RP2040"],
    "Memory_Flash": ["W25Q32JVZP"],
    "Power_Protection": ["USBLC6-2SC6"],
    "Regulator_Linear": ["XC6206PxxxMR"],
    "power": ["GND", "+3V3", "+5V", "+1V1", "VBUS", "PWR_FLAG"],
}


def load_lib(name):
    return sexp.loads((STOCK / f"{name}.kicad_sym").read_text(encoding="utf-8"))


def flatten(lib, name):
    sym = next(x for x in sexp.findall(lib, "symbol") if x[1] == name)
    ext = sexp.find(sym, "extends")
    if not ext:
        return [x if not (isinstance(x, list) and x and x[0] == "symbol") else x for x in sym]
    parent = flatten(lib, ext[1])
    pname = parent[1]
    out = ["symbol", name]
    child_props = {p[1]: p for p in sexp.findall(sym, "property")}
    for x in parent[2:]:
        if isinstance(x, list) and x and x[0] == "property":
            out.append(child_props.pop(x[1], x))
        elif isinstance(x, list) and x and x[0] == "symbol":
            unit = list(x)
            unit[1] = unit[1].replace(pname, name, 1)
            out.append(unit)
        else:
            out.append(x)
    for p in child_props.values():
        out.insert(len([y for y in out if not (isinstance(y, list) and y[0] == "symbol")]), p)
    return out


SYMS = {}
for libname, names in NEEDED.items():
    lib = load_lib(libname)
    for nm in names:
        SYMS[nm] = flatten(lib, nm)
# W25Q16JVUXIQ (USON-8 2x3, as on the Raspberry Pi Pico) shares the W25Q32JVZP pinout incl. EP
_f = [x for x in SYMS.pop("W25Q32JVZP")]
_f[1] = "W25Q16JVUXIQ"
for _x in _f:
    if isinstance(_x, list) and _x and _x[0] == "symbol":
        _x[1] = _x[1].replace("W25Q32JVZP", "W25Q16JVUXIQ")
    if isinstance(_x, list) and _x and _x[0] == "property":
        if _x[1] == "Value":
            _x[2] = "W25Q16JVUXIQ"
        elif _x[1] == "Footprint":
            _x[2] = "Package_SON:Winbond_USON-8-1EP_3x2mm_P0.5mm_EP0.2x1.6mm"
        elif _x[1] == "Datasheet":
            _x[2] = "https://www.winbond.com/resource-files/w25q16jv%20spi%20revh%2005182017%20sfdp.pdf"
SYMS["W25Q16JVUXIQ"] = _f


def pins_of(sym):
    """{number: (x, y, angle, name, type)} in symbol (Y-up) coordinates."""
    out = {}

    def walk(o):
        if isinstance(o, list):
            if o and o[0] == "pin":
                at = sexp.find(o, "at")
                nm = sexp.find(o, "name")[1]
                num = sexp.find(o, "number")[1]
                out.setdefault(num, (at[1], at[2], at[3], nm, str(o[1])))
            for z in o:
                walk(z)
    walk(sym)
    return out


PINS = {k: pins_of(v) for k, v in SYMS.items()}


def xform(px, py, ang):
    return {0: (px, -py), 90: (-py, -px), 180: (-px, py), 270: (py, px)}[ang]


# ------------------------------------------------------------------ schematic model
# Label positions tidied by hand in KiCad (2026-10-02). A rebuild keeps them: (ref, field) -> (x, y, angle)
FIELD_AT = {
    ("#PWR023", "Reference"): (397.51, 91.186, 90), ("#PWR023", "Value"): (399.288, 91.186, 90),
    ("#PWR024", "Reference"): (390.398, 91.186, 90), ("#PWR024", "Value"): (392.43, 91.44, 90),
    ("#PWR025", "Reference"): (402.336, 91.186, 90), ("#PWR025", "Value"): (404.368, 91.44, 90),
    ("#PWR026", "Reference"): (385.826, 91.44, 90), ("#PWR026", "Value"): (387.604, 89.916, 90),
    ("#PWR027", "Reference"): (407.416, 91.186, 90), ("#PWR027", "Value"): (409.194, 91.186, 90),
    ("#PWR028", "Reference"): (412.75, 91.186, 90), ("#PWR028", "Value"): (414.48, 91.44, 90),
    ("#PWR037", "Reference"): (520.192, 204.47, 0), ("#PWR037", "Value"): (517.906, 208.28, 0),
    ("Y1", "Value"): (516.128, 194.31, 0),
}


class Sch:
    def __init__(self):
        self.items = []
        self.symbols_used = set()
        self.pwr = 0
        self.comps = []      # for BOM/netplan
        self.done = set()
        self.netplan = {}    # (ref, pin) -> net

    def place(self, sym, ref, value, x, y, ang=0, fp="", lcsc="", mpn="", desc="", extra=None, hide_value=False,
              datasheet="", in_bom=True):
        self.symbols_used.add(sym)
        pins = PINS[sym]
        props = [("Reference", ref, (x + 2.54, y - 3.0), False), ("Value", value, (x + 2.54, y + 3.0), hide_value),
                 ("Footprint", fp, (x, y), True), ("Datasheet", datasheet, (x, y), True), ("Description", desc, (x, y), True)]
        if lcsc:
            props.append(("LCSC", lcsc, (x, y), True))
        if mpn:
            props.append(("MPN", mpn, (x, y), True))
        for k, v in (extra or {}).items():
            props.append((k, v, (x, y), True))
        e = ["symbol", ["lib_id", f"{LIBNAME}:{sym}"], ["at", x, y, ang], ["unit", 1], ["body_style", 1],
             ["exclude_from_sim", S("no")], ["in_bom", S("no" if (ref.startswith("#") or not in_bom) else "yes")],
             ["on_board", S("no" if ref.startswith("#") else "yes")], ["dnp", S("no")], ["uuid", uid("sym", ref)]]
        for k, v, (tx, ty), hide in props:
            tx, ty, ta = FIELD_AT.get((ref, k), (tx, ty, 0))
            pe = ["property", k, v, ["at", tx, ty, ta]]
            if hide:
                pe.append(["hide", S("yes")])
            pe.append(["effects", ["font", ["size", 1.27, 1.27]], ["justify", S("left")]])
            e.append(pe)
        for num in pins:
            e.append(["pin", num, ["uuid", uid("pin", ref, num)]])
        e.append(["instances", ["project", LIBNAME, ["path", "/" + SCH_UUID, ["reference", ref], ["unit", 1]]]])
        self.items.append(e)
        if not ref.startswith("#"):
            self.comps.append(dict(ref=ref, value=value, footprint=fp, lcsc=lcsc, mpn=mpn, symbol=sym, desc=desc))
        return {num: (x + xform(p[0], p[1], ang)[0], y + xform(p[0], p[1], ang)[1], p) for num, p in pins.items()}

    def pin_dir(self, p, ang):
        """Outward direction (angle where a label should point) for a pin."""
        pa = (p[2] + ang) % 360
        # pin angle = direction from connection point toward body; label goes opposite
        return {0: 180, 90: 270, 180: 0, 270: 90}[pa]

    def label(self, name, xy, direction=0, ref=None, pin=None):
        x, y = xy
        just = {0: "left", 180: "right", 90: "left", 270: "right"}[direction]
        ang = {0: 0, 180: 0, 90: 90, 270: 90}[direction]
        self.items.append(["label", name, ["at", x, y, ang], ["fields_autoplaced", S("yes")],
                           ["effects", ["font", ["size", 1.27, 1.27]], ["justify", S(just), S("bottom")]],
                           ["uuid", uid("lbl", name, round(x, 3), round(y, 3))]])
        if ref:
            self.netplan[(ref, pin)] = name

    def pinlabel(self, placed, ref, num, name, ang=0):
        x, y, p = placed[num]
        d = self.pin_dir(p, ang)
        self.netplan[(ref, num)] = name
        key = (name, round(x, 3), round(y, 3))
        if key in self.done:
            return
        self.done.add(key)
        if name in POWER_NETS:
            # GND-style symbols draw downward at rotation 0, supply symbols upward
            rot = (d + 90) % 360 if name == "GND" else (d - 90) % 360
            self.power(name, (x, y), rot=rot)
        else:
            self.label(name, (x, y), d)

    def power(self, kind, xy, ref_for=None, pin=None, rot=0):
        self.pwr += 1
        sym = kind
        r = f"#{'FLG' if kind == 'PWR_FLAG' else 'PWR'}{self.pwr:03d}"
        self.place(sym, r, kind, xy[0], xy[1], rot, hide_value=(kind == "PWR_FLAG"))
        if ref_for:
            self.netplan[(ref_for, pin)] = kind

    def nc(self, xy):
        self.items.append(["no_connect", ["at", xy[0], xy[1]], ["uuid", uid("nc", round(xy[0], 3), round(xy[1], 3))]])

    def wire(self, a, b):
        self.items.append(["wire", ["pts", ["xy", a[0], a[1]], ["xy", b[0], b[1]]],
                           ["stroke", ["width", 0], ["type", S("default")]], ["uuid", uid("w", a, b)]])

    def text(self, t, x, y, size=1.8, bold=False):
        fnt = ["font", ["size", size, size]] + ([["bold", S("yes")]] if bold else [])
        self.items.append(["text", t, ["exclude_from_sim", S("no")], ["at", x, y, 0],
                           ["effects", fnt, ["justify", S("left"), S("bottom")]], ["uuid", uid("txt", t[:40], x, y)]])

    def box(self, x0, y0, x1, y1):
        self.items.append(["rectangle", ["start", x0, y0], ["end", x1, y1],
                           ["stroke", ["width", 0.3], ["type", S("dash")]], ["fill", ["type", S("none")]],
                           ["uuid", uid("rect", x0, y0)]])


POWER_NETS = {"GND", "+3V3", "+5V", "+1V1", "VBUS"}


def g(v):
    """snap to 1.27 mm grid"""
    return round(v / 1.27) * 1.27


FP = {
    "R0402": f"{LIBNAME}:Resistor_0402", "C0402": f"{LIBNAME}:Capacitor_0402",
    "C0603": f"{LIBNAME}:C_0603_1608Metric", "D": f"{LIBNAME}:Diode_SOD-123",
    "QFN": f"{LIBNAME}:QFN-56-1EP_7x7mm_P0.4mm_EP3.2x3.2mm_ThermalVias",
    "USON8": f"{LIBNAME}:Winbond_USON-8-1EP_3x2mm_P0.5mm_EP0.2x1.6mm",
    "USBC": f"{LIBNAME}:USB_C_HRO_TYPE-C-31-M-12", "SOIC8": f"{LIBNAME}:SOIC-8_5.3x5.3mm_P1.27mm",
    "XTAL": f"{LIBNAME}:Crystal_SMD_3225-4Pin_3.2x2.5mm", "SOT23": f"{LIBNAME}:Voltage_SOT-23", "SOT23-6": f"{LIBNAME}:ESD_SOT-23-6",
    "FUSE": f"{LIBNAME}:Fuse_0805_2012Metric", "BTN": f"{LIBNAME}:SW_Push_1P1T_XKB_TS-1187A",
    "TP": f"{LIBNAME}:TestPoint_Pad_D1.0mm",
}


def build():
    s = Sch()
    # ---------------------------------------------------------------- titles / frames
    s.box(25, 25, 245, 225)
    s.text("USB-C · protection · 3.3 V supply", 30, 33, 3, True)
    s.box(255, 25, 815, 270)
    s.text("RP2040 · 2 MB QSPI flash · 12 MHz crystal · boot/reset · SWD", 260, 33, 3, True)
    s.box(25, 280, 815, 575)
    s.text("Key matrix · 82 × Kailh CPG151101S11 hot-swap sockets · 1N4148W · 6 rows × 16 columns · COL2ROW", 30, 288, 3, True)

    # ---------------------------------------------------------------- USB-C
    j1 = s.place("USB_C_Receptacle_USB2.0_16P", "J1", "TYPE-C-31-M-12", g(60), g(110), 0, FP["USBC"], "C165948",
                 "HRO TYPE-C-31-M-12", "USB-C receptacle, USB 2.0, 16 pin, bottom-side mounted at rear edge")
    for num in ("A4", "A9", "B4", "B9"):
        s.pinlabel(j1, "J1", num, "VBUS")
    s.pinlabel(j1, "J1", "A5", "CC1")
    s.pinlabel(j1, "J1", "B5", "CC2")
    s.pinlabel(j1, "J1", "A6", "USB_D+")
    s.pinlabel(j1, "J1", "B6", "USB_D+")
    s.pinlabel(j1, "J1", "A7", "USB_D-")
    s.pinlabel(j1, "J1", "B7", "USB_D-")
    s.nc(j1["A8"][:2])
    s.nc(j1["B8"][:2])
    for num in ("A1", "A12", "B1", "B12"):
        s.pinlabel(j1, "J1", num, "GND")
    s.pinlabel(j1, "J1", "SH", "GND")

    r1 = s.place("R", "R1", "5.1k", g(110), g(100), 0, FP["R0402"], "C25905", "0402WGF5101TCE", "USB-C CC1 pull-down (sink)")
    s.pinlabel(r1, "R1", "1", "CC1")
    s.pinlabel(r1, "R1", "2", "GND")
    r2 = s.place("R", "R2", "5.1k", g(125), g(100), 0, FP["R0402"], "C25905", "0402WGF5101TCE", "USB-C CC2 pull-down (sink)")
    s.pinlabel(r2, "R2", "1", "CC2")
    s.pinlabel(r2, "R2", "2", "GND")

    u2 = s.place("USBLC6-2SC6", "U2", "USBLC6-2SC6", g(175), g(100), 0, FP["SOT23-6"], "C7519", "USBLC6-2SC6",
                 "USB D+/D- and VBUS ESD protection")
    # bottom-side mounting mirrors the SOT-23-6, so D+ uses channel I/O2 and D- uses I/O1
    s.pinlabel(u2, "U2", "3", "USB_D+")
    s.pinlabel(u2, "U2", "4", "USB_D+")
    s.pinlabel(u2, "U2", "1", "USB_D-")
    s.pinlabel(u2, "U2", "6", "USB_D-")
    s.pinlabel(u2, "U2", "5", "VBUS")
    s.pinlabel(u2, "U2", "2", "GND")

    f1 = s.place("Polyfuse", "F1", "500mA", g(110), g(160), 0, FP["FUSE"], "C66452", "SMD0805-050", "Resettable PTC fuse, 0.5 A hold")
    s.pinlabel(f1, "F1", "1", "VBUS")
    s.pinlabel(f1, "F1", "2", "+5V")
    c1 = s.place("C", "C1", "10uF", g(135), g(160), 0, FP["C0603"], "C19702", "CL10A106KP8NNNC", "LDO input")
    s.pinlabel(c1, "C1", "1", "+5V")
    s.pinlabel(c1, "C1", "2", "GND")
    u3 = s.place("XC6206PxxxMR", "U3", "XC6206P332MR", g(175), g(160), 0, FP["SOT23"], "C5446", "XC6206P332MR",
                 "3.3 V 200 mA LDO")
    s.pinlabel(u3, "U3", "3", "+5V")
    s.pinlabel(u3, "U3", "2", "+3V3")
    s.pinlabel(u3, "U3", "1", "GND")
    c2 = s.place("C", "C2", "10uF", g(210), g(160), 0, FP["C0603"], "C19702", "CL10A106KP8NNNC", "LDO output")
    s.pinlabel(c2, "C2", "1", "+3V3")
    s.pinlabel(c2, "C2", "2", "GND")
    # power flags
    for i, net in enumerate(["+5V", "GND", "VBUS"]):
        x, y = g(60 + 45 * i), g(205)
        s.power("PWR_FLAG", (x, y))
        s.power(net, (x, y), rot=0 if net == "GND" else 180)
    s.text("CC1/CC2 5.1 kΩ = USB-C sink (works with C-to-C cables). PTC limits faults to 0.5 A.", 30, 218, 1.5)

    # ---------------------------------------------------------------- RP2040
    ux, uy = g(400), g(140)
    u1 = s.place("RP2040", "U1", "RP2040", ux, uy, 0, FP["QFN"], "C2040", "RP2040",
                 "Raspberry Pi RP2040 MCU, QFN-56, exposed pad = GND")
    gpio_net = {}
    for r, gp in enumerate(L.ROW_GPIO):
        gpio_net[gp] = f"ROW{r}"
    for c, gp in enumerate(L.COL_GPIO):
        gpio_net[gp] = f"COL{c}"
    for num, p in PINS["RP2040"].items():
        name = p[3]
        if name.startswith("GPIO"):
            gp = int(name[4:].split("/")[0])
            if gp in gpio_net:
                s.pinlabel(u1, "U1", num, gpio_net[gp])
            else:
                s.nc(u1[num][:2])
    for num in ("1", "10", "22", "33", "42", "49", "43", "44", "48"):
        s.pinlabel(u1, "U1", num, "+3V3")
    for num in ("45", "23", "50"):
        s.pinlabel(u1, "U1", num, "+1V1")
    s.pinlabel(u1, "U1", "57", "GND")
    s.pinlabel(u1, "U1", "19", "GND")          # TESTEN
    s.pinlabel(u1, "U1", "26", "RUN")
    s.pinlabel(u1, "U1", "46", "RP_DM")
    s.pinlabel(u1, "U1", "47", "RP_DP")
    for num, net in (("56", "QSPI_SS"), ("52", "QSPI_SCLK"), ("53", "QSPI_SD0"), ("55", "QSPI_SD1"),
                     ("54", "QSPI_SD2"), ("51", "QSPI_SD3")):
        s.pinlabel(u1, "U1", num, net)
    s.pinlabel(u1, "U1", "20", "XIN")
    s.pinlabel(u1, "U1", "21", "XOUT")
    s.nc(u1["24"][:2])          # SWCLK - not needed: ROM USB bootloader + BOOT/RESET buttons
    s.nc(u1["25"][:2])          # SWDIO

    # USB series resistors
    for i, (ref, a, b) in enumerate((("R3", "RP_DP", "USB_D+"), ("R4", "RP_DM", "USB_D-"))):
        r = s.place("R", ref, "27R", g(300 + 14 * i), g(80), 0, FP["R0402"], "C25100", "0402WGF270JTCE", "USB series termination")
        s.pinlabel(r, ref, "1", a)
        s.pinlabel(r, ref, "2", b)

    # QSPI flash
    u4 = s.place("W25Q16JVUXIQ", "U4", "W25Q16JVUXIQ", g(300), g(190), 0, FP["USON8"], "C2843335", "W25Q16JVUXIQ",
                 "2 MB QSPI NOR flash (same part as Raspberry Pi Pico)")
    for num, net in (("1", "QSPI_SS"), ("6", "QSPI_SCLK"), ("5", "QSPI_SD0"), ("2", "QSPI_SD1"), ("3", "QSPI_SD2"),
                     ("7", "QSPI_SD3"), ("8", "+3V3"), ("4", "GND")):
        s.pinlabel(u4, "U4", num, net)
    s.nc(u4["9"][:2])
    r5 = s.place("R", "R5", "10k", g(330), g(240), 0, FP["R0402"], "C25744", "0402WGF1002TCE", "Flash CS pull-up")
    s.pinlabel(r5, "R5", "1", "+3V3")
    s.pinlabel(r5, "R5", "2", "QSPI_SS")
    r6 = s.place("R", "R6", "1k", g(345), g(240), 0, FP["R0402"], "C11702", "0402WGF1001TCE", "BOOTSEL series resistor")
    s.pinlabel(r6, "R6", "1", "QSPI_SS")
    s.pinlabel(r6, "R6", "2", "BOOTSEL")
    sw_boot = s.place("SW_Push", "SW90", "BOOT", g(375), g(255), 0, FP["BTN"], "C318884", "TS-1187A-B-A-B",
                      "Hold while plugging in to enter the RP2040 USB bootloader")
    s.pinlabel(sw_boot, "SW90", "1", "BOOTSEL")
    s.pinlabel(sw_boot, "SW90", "2", "GND")
    r7 = s.place("R", "R7", "10k", g(420), g(240), 0, FP["R0402"], "C25744", "0402WGF1002TCE", "RUN pull-up")
    s.pinlabel(r7, "R7", "1", "+3V3")
    s.pinlabel(r7, "R7", "2", "RUN")
    sw_rst = s.place("SW_Push", "SW91", "RESET", g(450), g(255), 0, FP["BTN"], "C318884", "TS-1187A-B-A-B", "Reset")
    s.pinlabel(sw_rst, "SW91", "1", "RUN")
    s.pinlabel(sw_rst, "SW91", "2", "GND")

    # crystal
    y1 = s.place("Crystal_GND24", "Y1", "12MHz", g(520), g(200), 0, FP["XTAL"], "C20625731", "ABM8-272-T3",
                 "12 MHz, CL 10 pF (Raspberry Pi approved for RP2040)")
    s.pinlabel(y1, "Y1", "1", "XIN")
    s.pinlabel(y1, "Y1", "3", "XTAL_OUT")
    s.pinlabel(y1, "Y1", "2", "GND")
    s.pinlabel(y1, "Y1", "4", "GND")
    r8 = s.place("R", "R8", "1k", g(555), g(185), 0, FP["R0402"], "C11702", "0402WGF1001TCE", "XOUT drive limit")
    s.pinlabel(r8, "R8", "1", "XOUT")
    s.pinlabel(r8, "R8", "2", "XTAL_OUT")
    for i, (ref, net) in enumerate((("C16", "XIN"), ("C17", "XTAL_OUT"))):
        c = s.place("C", ref, "15pF", g(500 + 40 * i), g(235), 0, FP["C0402"], "C1548", "0402CG150J500NT", "Crystal load")
        s.pinlabel(c, ref, "1", net)
        s.pinlabel(c, ref, "2", "GND")

    # decoupling
    caps = [("C3", "100nF", "+3V3", "IOVDD 1"), ("C4", "100nF", "+3V3", "IOVDD 10"), ("C5", "100nF", "+3V3", "IOVDD 22"),
            ("C6", "100nF", "+3V3", "IOVDD 33"), ("C7", "100nF", "+3V3", "IOVDD 42"),
            ("C9", "100nF", "+3V3", "USB_VDD 48 / IOVDD 49"), ("C10", "100nF", "+3V3", "ADC_AVDD 43"),
            ("C11", "100nF", "+1V1", "DVDD 23"), ("C12", "100nF", "+1V1", "DVDD (pins 23/50)"),
            ("C13", "1uF", "+3V3", "VREG_VIN 44"), ("C14", "1uF", "+1V1", "VREG_VOUT 45"),
            ("C15", "100nF", "+3V3", "Flash VCC")]
    for i, (ref, val, net, why) in enumerate(caps):
        lc, mp = ("C1525", "CL05B104KO5NNNC") if val == "100nF" else ("C52923", "CL05A105KA5NQNC")
        c = s.place("C", ref, val, g(600 + 16 * (i % 7)), g(90 + 55 * (i // 7)), 0, FP["C0402"], lc, mp, f"Decoupling {why}")
        s.pinlabel(c, ref, "1", net)
        s.pinlabel(c, ref, "2", "GND")

    # test points (SWD, power)
    for i, (ref, net) in enumerate((("TP1", "RUN"), ("TP2", "+3V3"), ("TP3", "GND"), ("TP4", "+5V"))):
        t = s.place("TestPoint", ref, net, g(600 + 25 * i), g(225), 0, FP["TP"], "", "", "Test pad (not assembled)",
                    in_bom=False)
        s.pinlabel(t, ref, "1", net)
    s.text("Hold BOOT while connecting USB (or press RESET while holding BOOT) to get the RPI-RP2 UF2 drive.\n"
           "A blank board enumerates as RPI-RP2 automatically. Test pads: RUN, +3V3, GND, +5V.", 600, 255, 1.5)

    # ---------------------------------------------------------------- key matrix
    keys = L.keys()
    x0, y0, dx, dy = 45, 315, 48.26, 43.18
    for k in keys:
        cx = g(x0 + dx * k["col"])
        cy = g(y0 + dy * k["row"])
        sw = s.place("SW_Push", k["ref"], k["label"], cx, cy, 0, f"{LIBNAME}:Hotswap_MX_{L.fp_size_name(k['w'])}",
                     "C5156480", "Kailh CPG151101S11", "MX hot-swap socket (switch is user-installed)",
                     extra={"Key": k["label"], "Matrix": f"R{k['row']}C{k['col']}"},
                     datasheet="https://www.kailhswitch.com/mechanical-keyboard-switches/box-switches/mechanical-keyboard-switches-kailh-pcb-socket.html")
        s.pinlabel(sw, k["ref"], "1", f"COL{k['col']}")
        # diode vertical, anode on the switch pin 2, cathode down to the row label
        ax, ay, _ = sw["2"]
        d = s.place("D", k["diode"], "1N4148W", ax, ay + 3.81, 90, FP["D"], "C81598", "1N4148W", "Matrix diode")
        s.netplan[(k["ref"], "2")] = f"K{k['n']}"
        s.netplan[(k["diode"], "2")] = f"K{k['n']}"
        s.pinlabel(d, k["diode"], "1", f"ROW{k['row']}")
    for c in range(L.MATRIX_COLS):
        s.text(f"COL{c}  GPIO{L.COL_GPIO[c]}", g(x0 + dx * c) - 8, y0 - 12, 1.6, True)
    for r in range(L.MATRIX_ROWS):
        s.text(f"ROW{r}\nGPIO{L.ROW_GPIO[r]}", 28, g(y0 + dy * r) + 6, 1.6, True)
    return s
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

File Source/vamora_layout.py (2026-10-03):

"""Vamora75 — single source of truth for layout, matrix, board geometry and revision.

Units: millimetres. PCB coordinates are KiCad page coordinates (Y down).
Board-local coordinates ("b-coords") have their origin at the PCB's rear-left
corner, X to the right, Y toward the user (front).
"""
from __future__ import annotations

REVISION, REV_DATE = "1.2", "2026-10-03"
DESIGNERS = ("Kevin Le", "Sammy DeGraaff", "Mohammed-Mehdi Hamdaoui")
TEAM = "Vamora"

U = 19.05                    # key pitch
MARGIN = 3.0                 # PCB margin around the key field
COLS_U, ROWS_U = 17.25, 6.75  # key field size in units (arrows sit 0.25u lower)
BOARD_W = COLS_U * U + 2 * MARGIN      # 334.6125
BOARD_H = ROWS_U * U + 2 * MARGIN      # 134.5875
PAGE_X0, PAGE_Y0 = 40.0, 80.0          # where the board sits on the KiCad A3 page

# (label, x[u], y[u], w[u], QMK keycode, matrix row, matrix col)
# Physical layout: the exploded 75% Windows ANSI (82 keys) of rev 0.1, with the arrow
# cluster moved 0.25u left and 0.25u down in rev 1.1 so it stands apart from the
# Del/Home/PgUp/PgDn/End column. Matrix: 6 physical rows x 16 columns (COL2ROW).
KEYS = [
    ("Esc", 0, 0, 1, "KC_ESC", 0, 0), ("F1", 2, 0, 1, "KC_F1", 0, 2), ("F2", 3, 0, 1, "KC_F2", 0, 3),
    ("F3", 4, 0, 1, "KC_F3", 0, 4), ("F4", 5, 0, 1, "KC_F4", 0, 5), ("F5", 6.25, 0, 1, "KC_F5", 0, 6),
    ("F6", 7.25, 0, 1, "KC_F6", 0, 7), ("F7", 8.25, 0, 1, "KC_F7", 0, 8), ("F8", 9.25, 0, 1, "KC_F8", 0, 9),
    ("F9", 10.5, 0, 1, "KC_F9", 0, 10), ("F10", 11.5, 0, 1, "KC_F10", 0, 11), ("F11", 12.5, 0, 1, "KC_F11", 0, 12),
    ("F12", 13.5, 0, 1, "KC_F12", 0, 13), ("Del", 16.25, 0, 1, "KC_DEL", 0, 15),

    ("`", 0, 1.5, 1, "KC_GRV", 1, 0), ("1", 1, 1.5, 1, "KC_1", 1, 1), ("2", 2, 1.5, 1, "KC_2", 1, 2),
    ("3", 3, 1.5, 1, "KC_3", 1, 3), ("4", 4, 1.5, 1, "KC_4", 1, 4), ("5", 5, 1.5, 1, "KC_5", 1, 5),
    ("6", 6, 1.5, 1, "KC_6", 1, 6), ("7", 7, 1.5, 1, "KC_7", 1, 7), ("8", 8, 1.5, 1, "KC_8", 1, 8),
    ("9", 9, 1.5, 1, "KC_9", 1, 9), ("0", 10, 1.5, 1, "KC_0", 1, 10), ("-", 11, 1.5, 1, "KC_MINS", 1, 11),
    ("=", 12, 1.5, 1, "KC_EQL", 1, 12), ("Backspace", 13, 1.5, 2, "KC_BSPC", 1, 13), ("Home", 16.25, 1.5, 1, "KC_HOME", 1, 15),

    ("Tab", 0, 2.5, 1.5, "KC_TAB", 2, 0), ("Q", 1.5, 2.5, 1, "KC_Q", 2, 1), ("W", 2.5, 2.5, 1, "KC_W", 2, 2),
    ("E", 3.5, 2.5, 1, "KC_E", 2, 3), ("R", 4.5, 2.5, 1, "KC_R", 2, 4), ("T", 5.5, 2.5, 1, "KC_T", 2, 5),
    ("Y", 6.5, 2.5, 1, "KC_Y", 2, 6), ("U", 7.5, 2.5, 1, "KC_U", 2, 7), ("I", 8.5, 2.5, 1, "KC_I", 2, 8),
    ("O", 9.5, 2.5, 1, "KC_O", 2, 9), ("P", 10.5, 2.5, 1, "KC_P", 2, 10), ("[", 11.5, 2.5, 1, "KC_LBRC", 2, 11),
    ("]", 12.5, 2.5, 1, "KC_RBRC", 2, 12), ("\\", 13.5, 2.5, 1.5, "KC_BSLS", 2, 13), ("PgUp", 16.25, 2.5, 1, "KC_PGUP", 2, 15),

    ("Caps", 0, 3.5, 1.75, "KC_CAPS", 3, 0), ("A", 1.75, 3.5, 1, "KC_A", 3, 1), ("S", 2.75, 3.5, 1, "KC_S", 3, 2),
    ("D", 3.75, 3.5, 1, "KC_D", 3, 3), ("F", 4.75, 3.5, 1, "KC_F", 3, 4), ("G", 5.75, 3.5, 1, "KC_G", 3, 5),
    ("H", 6.75, 3.5, 1, "KC_H", 3, 6), ("J", 7.75, 3.5, 1, "KC_J", 3, 7), ("K", 8.75, 3.5, 1, "KC_K", 3, 8),
    ("L", 9.75, 3.5, 1, "KC_L", 3, 9), (";", 10.75, 3.5, 1, "KC_SCLN", 3, 10), ("'", 11.75, 3.5, 1, "KC_QUOT", 3, 11),
    ("Enter", 12.75, 3.5, 2.25, "KC_ENT", 3, 13), ("PgDn", 16.25, 3.5, 1, "KC_PGDN", 3, 15),

    ("LShift", 0, 4.5, 2.25, "KC_LSFT", 4, 0), ("Z", 2.25, 4.5, 1, "KC_Z", 4, 1), ("X", 3.25, 4.5, 1, "KC_X", 4, 2),
    ("C", 4.25, 4.5, 1, "KC_C", 4, 3), ("V", 5.25, 4.5, 1, "KC_V", 4, 4), ("B", 6.25, 4.5, 1, "KC_B", 4, 5),
    ("N", 7.25, 4.5, 1, "KC_N", 4, 6), ("M", 8.25, 4.5, 1, "KC_M", 4, 7), (",", 9.25, 4.5, 1, "KC_COMM", 4, 8),
    (".", 10.25, 4.5, 1, "KC_DOT", 4, 9), ("/", 11.25, 4.5, 1, "KC_SLSH", 4, 10), ("RShift", 12.25, 4.5, 1.75, "KC_RSFT", 4, 12),
    ("Up", 15.0, 4.75, 1, "KC_UP", 4, 14), ("End", 16.25, 4.5, 1, "KC_END", 4, 15),

    ("LCtrl", 0, 5.5, 1.25, "KC_LCTL", 5, 0), ("Win", 1.25, 5.5, 1.25, "KC_LGUI", 5, 1), ("LAlt", 2.5, 5.5, 1.25, "KC_LALT", 5, 2),
    ("Space", 3.75, 5.5, 6.25, "KC_SPC", 5, 5), ("RAlt", 10, 5.5, 1, "KC_RALT", 5, 9), ("Fn", 11, 5.5, 1, "MO(1)", 5, 10),
    ("RCtrl", 12, 5.5, 1, "KC_RCTL", 5, 11), ("Left", 14.0, 5.75, 1, "KC_LEFT", 5, 13), ("Down", 15.0, 5.75, 1, "KC_DOWN", 5, 14),
    ("Right", 16.0, 5.75, 1, "KC_RGHT", 5, 15),
]

MATRIX_ROWS, MATRIX_COLS = 6, 16

# RP2040 GPIO assignment, chosen for a crossing-free fan-out of the bottom-mounted QFN
# that sits in the F12-Del gap: COL0..COL12 leave the west side as a bus along the
# 0.5u gap under the F-row; rows, COL13 and COL14 drop down the nav-column gap.
ROW_GPIO = [0, 6, 5, 4, 3, 2]
COL_GPIO = [29, 28, 27, 26, 24, 23, 22, 21, 20, 19, 18, 17, 16, 8, 7, 1]
# Free: GPIO9-15, GPIO25. GP25 stays free on purpose (status LED of the
# Raspberry Pi Pico CircuitPython build used as the no-compile firmware option).

STAB_SPACING = {2.0: 11.938, 2.25: 11.938, 2.75: 11.938, 6.25: 50.0, 7.0: 57.15}


def fp_size_name(w: float) -> str:
    return {1: "1.00u", 1.25: "1.25u", 1.5: "1.50u", 1.75: "1.75u", 2: "2.00u", 2.25: "2.25u", 6.25: "6.25u"}[w]


def keys():
    """List of dicts with computed centres (board-local b-coords and KiCad page coords)."""
    out = []
    for n, (label, x, y, w, kc, r, c) in enumerate(KEYS, start=1):
        bx = MARGIN + (x + w / 2) * U
        by = MARGIN + (y + 0.5) * U
        out.append(dict(n=n, ref=f"SW{n}", diode=f"D{n}", label=label, x=x, y=y, w=w, kc=kc,
                        row=r, col=c, bx=bx, by=by, px=PAGE_X0 + bx, py=PAGE_Y0 + by,
                        stab=STAB_SPACING.get(w)))
    return out


def check():
    ks = keys()
    assert len(ks) == 82
    cells = {(k["row"], k["col"]) for k in ks}
    assert len(cells) == 82, "duplicate matrix position"
    assert all(0 <= k["row"] < MATRIX_ROWS and 0 <= k["col"] < MATRIX_COLS for k in ks)
    gp = ROW_GPIO + COL_GPIO
    assert len(set(gp)) == len(gp) and 25 not in gp
    return True


if __name__ == "__main__":
    check()
    print(f"board {BOARD_W:.4f} x {BOARD_H:.4f} mm, {len(KEYS)} keys, matrix {MATRIX_ROWS}x{MATRIX_COLS}")

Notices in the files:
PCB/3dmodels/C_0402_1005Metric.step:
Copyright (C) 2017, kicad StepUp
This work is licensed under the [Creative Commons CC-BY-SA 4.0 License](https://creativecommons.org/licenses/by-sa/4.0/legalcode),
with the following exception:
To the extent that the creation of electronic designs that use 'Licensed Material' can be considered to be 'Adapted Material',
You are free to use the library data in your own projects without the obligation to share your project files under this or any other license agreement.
